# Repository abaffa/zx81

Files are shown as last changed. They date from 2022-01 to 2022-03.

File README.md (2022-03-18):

# ZX80/81 Project
A tribute repository for the Sinclair ZX81 homecomputer. Or... how I build my own zeddy.

I used the PCB designed by Wilco2009. You can get more info about (eagle/gerbers) at his repos (https://github.com/wilco2009/zx80-81-Double-Clone)

## Technical Information about ZX81
* [ZX81 Datasheet](_zx81/README.md)
* [ZX81 Peripherals](_zx81/peripherals/README.md)
* [ZX80/81 Project - Schematics](schema/README.md)

---

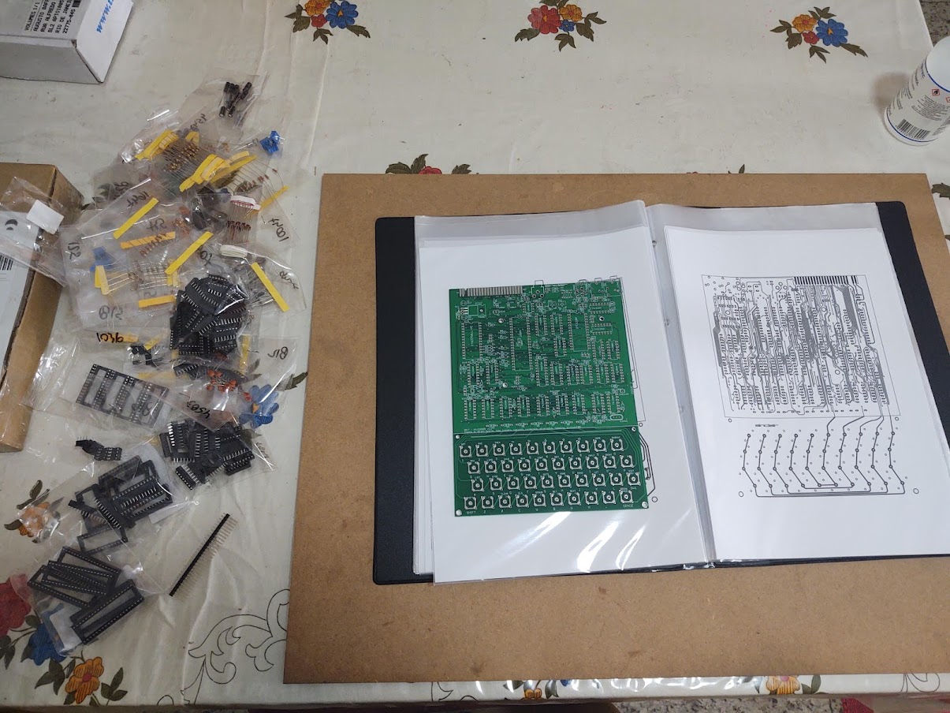
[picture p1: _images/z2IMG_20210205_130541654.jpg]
Starting Project


Starting Project

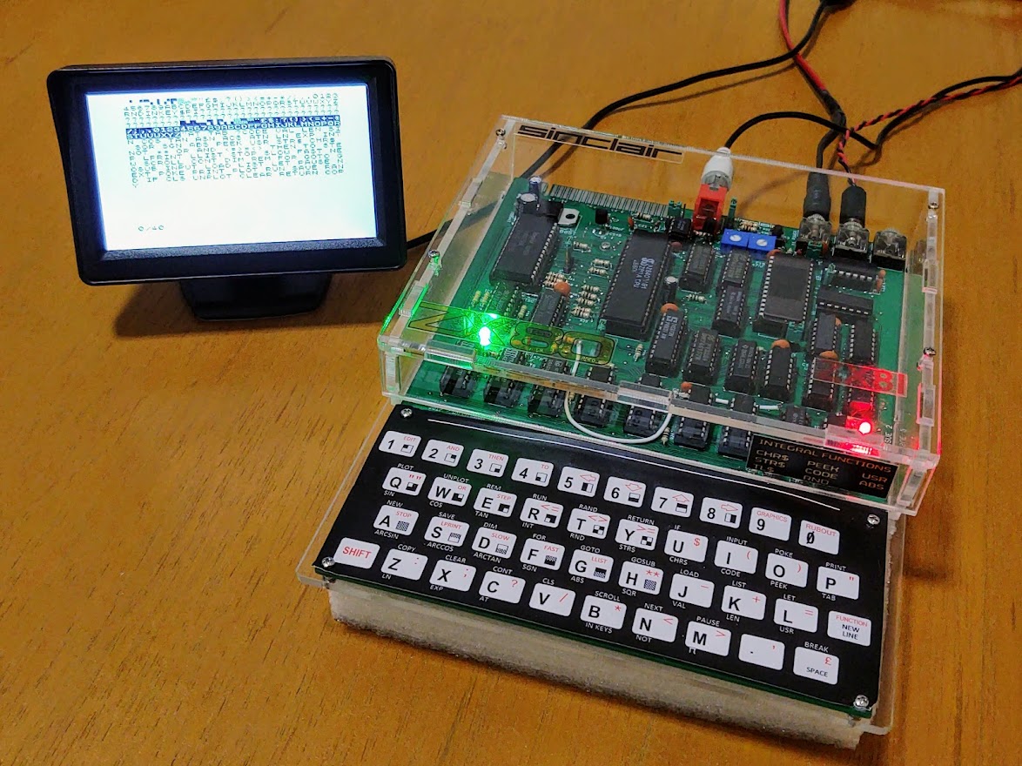
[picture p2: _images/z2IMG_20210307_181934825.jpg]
Project Done


Project Done

Zonx Prototype (https://www.youtube.com/watch?v=Kemn_Q3tHYs)

Zonx Prototype (video)

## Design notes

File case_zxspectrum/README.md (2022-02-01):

# 3D printed ZX Spectrum replacement case
by menyiques is licensed under the Creative Commons - Attribution - Share Alike license.

http://creativecommons.org/licenses/by-sa/3.0/

## Summary

WARNING: This is a concept and not a printable finished model.  Print under your responsability.

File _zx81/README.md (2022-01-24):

# Sinclair ZX81 Datasheet

* [Hardware](hardware.md)
* [Maintenance](maintenance.md)
* [Troubleshooting](troubleshooting.md)
* [Mods](mods.md)
* [List of Components](bom.md)

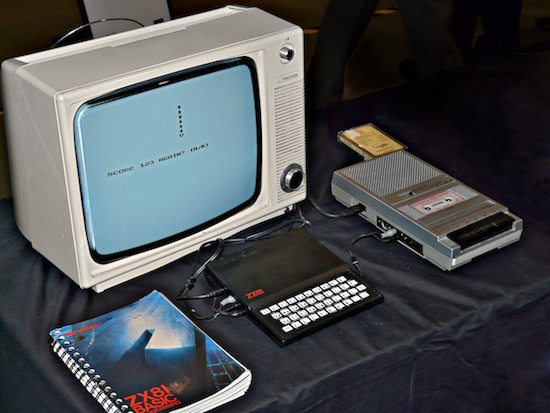
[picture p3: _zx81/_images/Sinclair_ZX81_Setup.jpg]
Sinclair ZX81


The ZX81 is the third computer from Sir Clive Sinclair's company, following the MK14 and the ZX80. Even having a relatively simple electronics, since it is made up of only 4 chips, it represents a significant improvement over its predecessor ZX80.

The computer is based on Zilog's Z80A microprocessor, with fairly limited RAM memory (1 kB), although expandable; and an 8 kB ROM that increased the 4 kb that the ZX80 had.

It introduces what would be a constant in Sinclair computers, which is the dedicated chip or "customized chip", such as the "Uncommitted Logic Array" or ULA.

The ULA was manufactured by Ferranti for Sinclair and replaces a total of 18 chips that performed similar functions in the ZX80. The main functions of this chip are:

* Generation of the clock frequency of 6.5 MHz through a ceramic filter.
* Bypass of the 3.5 MHz frequency necessary for microprocessor operation.
* TV signal generation compatible for RF modulator.
* Control of the external recording and playback device (SAVE / LOAD).
* Keyboard controls.
* Management of access priorities to RAM and ROM.
* Control of the general “timing” of the system.

Another important novelty compared to the ZX80 is the introduction of the SLOW mode, in addition to the FAST mode that it shares with the ZX80. This mode eliminates the annoying flicker characteristic of the ZX80 when making keystrokes.

The computer has no sound or color, working only in black and white and with limited graphic capabilities.

The keyboard is another of the characteristics of this computer, formed by a discussed membrane of 40 multifunction touch keys.

The computer uses Sinclair Basic as its programming language, whose interpreter is in ROM, in addition to the processor's own machine language. Although it is possible to find assemblers for other languages such as Forth.

It has an internal consumption in basic configuration of between 310 and 390 mA.

| Item  | Value |
| --- | --- |
|  Name |  Sinclair ZX81 |
|  Origin |  United Kingdom |
|  Launched |  March, 5th 1981 |
|  End of Production |  1984 |
|  Language |  Sinclair Basic |
|  Units Sold  |  > 1.5 Million |
|  Keyboard  |  40 Keys membrane keyboard |
|  CPU  |  Zilog Z80 A |
|  Speed  |  3.5 Mhz |
|  Bus  |  Data: 8 bits / Address 16 bits |
|  Ram  |  1KB (901 bytes available) - Max Expansion: 64KB (56 KB Available) |
|  Rom  |  8 KB |
|  Text Mode  | 32 x 24 (2 lines reserved for system messages and commands) |
|  Graphic Mode  | 64 x 44 (using PLOT / UNPLOT commands) |
|  Color  |  Black and White |
|  Sound  |  No |
|  Size and Weight  |  167 x 175 x 40 mm / 350 gr |
|  I/O Ports  |  Expansion Port, 2 cassete outputs (play and record), RF video output, load speed 300 bps (KCS) |
|  Power Source  |  External PSU, 9V DC, 600 mA (Positive polarity at the tip of the jack) |
|  Peripherals  |  ZX Printer |
|  Price  |  Kit: 50 GBP (UK, Jun 1981) - Assembled: 70 GBP (UK, Jun 1981) |

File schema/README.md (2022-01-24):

# ZX80/81 Project - Schematics
Schematics I made while studying how the ZX80/81 works

* [ZX81_Detailed_Schematics](ZX81_Detailed_Schematics.pdf) - Detailed Schematics used to create the PCBs - Gerber file
* [ZX81_Andy_Rea_ULA_Explained](ZX81_Andy_Rea_ULA_Explained.pdf) - ZX81 and ULA logic based on explained by Andy Rea
* [ZX81_Complete](ZX81_Complete.PDF) - Complete Schematic (ZX80 + Slow Circuit = ZX81) based on Sinclairs ZX80 Schematics and Grant Searle project

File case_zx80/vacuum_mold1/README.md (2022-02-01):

# Sinclair ZX80 Vacuum Form Molds 

by wjsteele is licensed under the Creative Commons - Public Domain Dedication license.

## Summary

This is a first attempt at a vacuum form mold set for the Sinclair ZX80 computer.  The ZX80's case was originally vacuum formed from polystyrene sheets, only later becoming injection molded.

This is an attempt to produce simple molds that can be made to replace the original cases which have become very brittle due to their age, or for a new ZX80 replica.  The Sinclair ZX80 computer was produced by a company called "Science Of Cambridge" (Later renamed Sinclar Research) in 1980 and was powered by the Zilog Z80 Microprocessor and utilized 4k of Rom and 1k of Ram.

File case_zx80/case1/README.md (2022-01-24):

# Sinclair ZX80 Case

by alvaroalea is licensed under the Creative Commons - Attribution - Non-Commercial - Share Alike license.

https://www.thingiverse.com/thing:1880449
http://creativecommons.org/licenses/by-nc-sa/3.0/

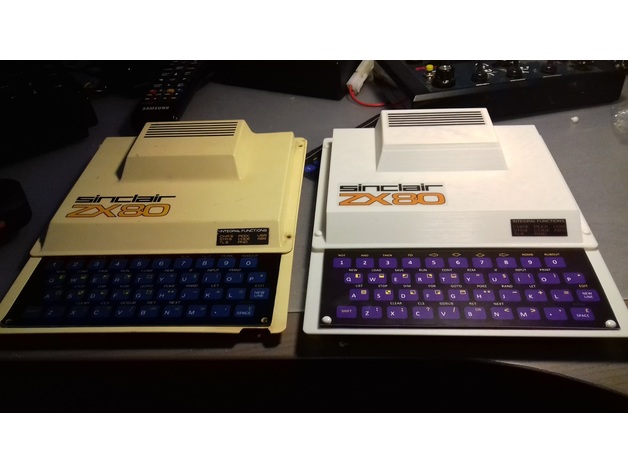
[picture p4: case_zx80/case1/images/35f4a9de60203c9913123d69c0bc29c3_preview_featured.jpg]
Printed Case


## Summary

This is part of the project to clone the Sinclair ZX80 8bits computer from 80's by people of the forum http://www.va-de-retro.com/foros/app.php/portal

botton side need to be printer in two part and optionally glued  in normal printers.

For the ribets, search for R2648 in certain chinesse web.

To be printed with support, the STL file also include some aditional supports I need to print it correctly with Cura.

There are aditional parts, for some customizations I made, check the correct parts for your need.

## Print Settings

Printer Brand: Prusa
Printer: Prusa Steel
Rafts: No
Supports: Yes
Resolution: 0.2mm layer, 0.4 nozzle
Infill: 100%

Notes: 
It's need a lot of support, I use Cura, with the zig-zag setting and a separation of 5mm.

## Post-Printing

Remove all the support and enlage the holes with a 2.5mm drill

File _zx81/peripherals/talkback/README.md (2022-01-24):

# ZX81 TALK-BACK

* [Mageco Eletronic SPO256 ZX81 Vocal Synthetizer Manual in French](MANUEL-ZX81-SPO256[MAGECO].pdf)
* [Eletronics - The Maplin Magazine Mar, 05th 1983](Maplin-Electronics-1983-03-05.pdf)

# ZX81 Talk~Back by Dave Goodman
(Maplin Magazine March 1983, UK)

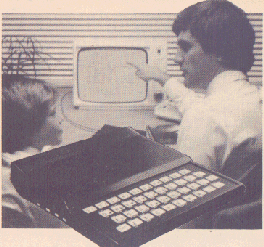
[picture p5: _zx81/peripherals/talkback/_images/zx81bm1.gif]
ZX81


* Add speech to your programs
* Allophone set provides unlimited vocabulary
* Plugs directly into expansion socket or motherboard
* Entry from simple PEEK and POKE in BASIC
* Audio output to extemal amplifier or our 'Sound-on-TV'

For many years considerable research and development has been done in the field of human speech synthesis. All languages have their own complex speech sounds, or ALLOPHONES, which are strung together to form recognisable words. The SHAW alphabet gives an indication of speech sounds, as many schoolchildren are probably aware.
Simple words like 'cad' use the letters 'see', 'ae', and 'tee'. Stringing these allophones together will produce the sound 'seat', not at all like 'cat', so letters of the alphabet are pronounced differently according to where they are used!

General Instruments' SPO256 Orator-Speech Processor makes use of the allophone system by storing sounds, with instructions, in 16K ROM. A Microtroller control data flow from ROM to a digital filter where speech elements are linked together, along with pitch and amplitude information. The resulting information is pulse width modulated, producing a digital output which has to be low pass filtered to produce recognisable speech.
Sixty-three allophones are available for use, and by concatenating individual sounds, reproduction of entire word lengths is possible. This is very flexible, although speech quality is not as good as systems where complete words are stored.

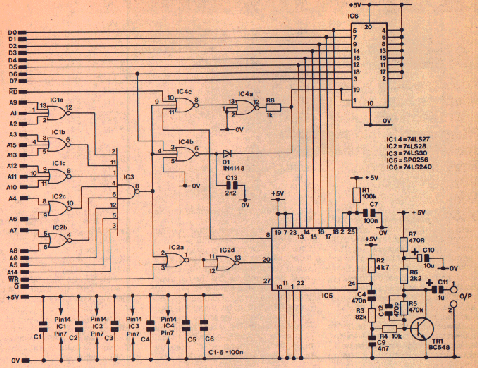
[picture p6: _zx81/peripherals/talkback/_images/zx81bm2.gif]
Circuit Diagram


## Circuit Description

Address lines A0 to A15 are decoded by IC1, 2 and 3 to give a memory-mapped 'PORT address of 16417. This address has not been allocated to the working system of the Zx81, and as it also has a RAM location it is ideal for use in this application. Writing to this address (POKE 16417) places a negative pulse on IC5 pin 20 Address Load input. Data written into IC5, on pins 13 to 18, is then loaded onto the input port, where it is processed to give speech output on pin 24. The circuitry of TR1 forms a low pass filter, to remove any H.F. content from the speech, and the resultant signal is amplified to a usable level of 100-500mV with the output on pin 1 (pin 2 is the 0V or screen). Obviously, the computer can supply data at a far greater rate than it can be processed by IC5, so pin 8 (standby) is used to enable IC6 if the 'PORT' address is read (PEEKed).

With suitable programming IC6 will place D0 to D8 to binary 0 and a software loop will prevent further data being entered to IC5 until the standby output resets. One problem, however, becomes apparent when the system is first switched on; R1 and C7 reset the SPO256 and pin 8 goes low. While the ZX81 CPU is resetting RAM locations, IC6 is enabled and data is prematurely entered, causing the computer to crash. lC4b, C13, and D1 hold IC6 pins 1 and 19 high to prevent this happening. Entering the command NEW can also cause this problem, but not if you are using 1 to 16K RAM. C13 may need to increase in value if larger RAM is used, and this is a subject for experimentation.

## Construction

Insert all 48 track pins through the holes marked with a circle, and solder them on both sides of the PCB. Fit resistors R1 to R7; if using the new 1% resistors with 5 band colour codes make sure that the values are correct. Finally, fit all capacitors, noting the polarity marking on C10. Do not insert the ICs yet. Solder all components to the PCB, clean, and inspect your work. Many faults can be cleared by using thinners and a stiff brush to remove all flux and solder splashes from the PCB.

If you do not possess a mother-board, fit a 2 x 23 socket (RK35Q) to the edge connector and solder all pins. Otherwise plug the module into your ZX81.

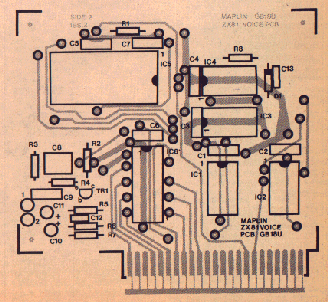
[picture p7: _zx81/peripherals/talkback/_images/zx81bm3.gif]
PCB Artwork and Legend


## Testing

Apply power. If all is well the cursor will appear as normal. Use a voltmeter to check that the 0V and +5V rails are correct on the PCB. Switch off and insert the six ICs into their sockets. Re-apply power. The cursor should appear again. You will need either an external amplifier or our sound/video project with connections to pins 1 and 2 on the module. Turn the amplifier or TV volume control to an acceptable level and type in POKE 16417, 197 followed by NEWLINE. You should hear the allophone 'oy' and a continuous 'e' sound. Type POKE 16417,0 NEWLINE and the sound will cease. Thus far, all should be well. Now enter program 1 and run it. Various prompts and directions appear during the program run and allophone sounds, not words, will be heard. Run the program several times to familiarise yourself with each sound and code number.

## Using the Talkback

If you refer to the Sinclair Manual page 178, you will see that address 16417 is not used by the working system. Fortunately this address, being part of the memory map, has a location in RAM which makes it ideal for use a a 'PORT'. Data POKEd to this address is read by the SPO256 chip, so the numbers entered must range from 192 to 255 to suit.
Table 1 gives a list of numbers and their equivalent allophone sound. Also shown is a list of ZX81 characters corresponding to each number and allophone. If a word, like COMPUTER, is phonetically split into a series of vowels and consonants the allophone equivalent will be something like this:

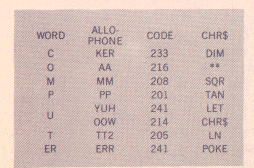
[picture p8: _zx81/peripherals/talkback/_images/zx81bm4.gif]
ZX81 Allophone Equivalent


## Allophones

The 5P0256 has 63 allophones, five of which are pauses of different duration, which leaves 58 to span the range of the English language. Because of this limitation compromises have to be made with pronunciation, but, in practise it is not a real problem as long as you do not mind your computer speaking with an American accent!

The letter c in computer does not sound like 'see', but 'k' as in kite. A short pause, e.g. code 194 (50ms) inserted between C and computer enhances the C, as can be heard in program 2. If you ran the test program, you will have heard each allophone spoken, and be already familiar with the sounds available, so now enter program 2.
The technique used in this program relies on placing allophone code numbers as CHR$ in line 1 after the REM statement. Altogether there are 18 CHRS in this line, including pauses. The first address after REM is 16514, so each character has its own address to 16532. The value of each address is POKEd into variable A, this being the PORT address of the speech processor, and line 1 is scanned, a character at a time, by line 10.

A software loop is set up by line 25 to allow time for each allophone to be spoken before continuing with the next instruction. Try removing line 25 from the program and listening to the difference.

Maybe you have your own routines for POKEIng numbers into port locations, so I won't go into programming techniques on the ZX81. Needless to say, if using this method the address must be found for the first character to be read after REM, otherwise your program may crash. Some of the allophone CHR$ must be entered in command word mode. One way of doing this is to first enter THEN (shift CHRS) to change the cursor from L to K, and then enter the command word. Step the cursor back to THEN and RUBOUT.

Step the cursor forward past the command word, and continue with the next CHR$. Always add a space (192 or "") at the end of the character string or insert POKE 16417,0 at the end of your program, otherwise speech will continue.
FOR-NEXT or PAUSE delays can be entered after the POKE 16417 command to slow down speech if you find that it talks too fast. Use codes 192 to 196 to add pauses between allophones where required. Previous sounds spoken can then be emphasised to suit the word formation, and speech made more intelligible.

Program 1.
```
1 REM TEST PROGRAM
2 LET A = 197
3 LET PORT = 16417
4 PRINT "PRESS NEWLINE"
5 IF INKEY$ = " " THEN GOTO 5
6 PRINT "ALLOPHONE ""OY"" WILL BE SPOKEN"
7 PAUSE 250
6 POKE PORT,A
9 POKE PORT,0
10 CLS
11 PRINT "NUMBER 197 TO 255 WILL BE DISPLAYED AND THE ALLOPHONE SPOKEN."
12 PAUSE 500
13 FOR A = 197 TO 255
14 PRINT AT 10,14;A
15 POKE PORT,A
16 FOR B = 0 TO 10
17 NEXT B
18 POKE PORT,192
19 NEXT A
20 POKE PORT,192
21 PRINT AT 15,0:"PRESS NEWLINE TO REPEAT TESTS"
22 INPUT A$
23 CLS
24 GOTO 11
```

Program 2.
```
1 LEN "" AT AND SQR "" TAB USR DIM AT ** SQR TAN LET CHR$ LN NEXT""
3 LET A = 16417
5 LET B = 16514
7 REM NUMBER OF CHR$
10 FOR C = B TO (B+17)
15 POKE A,PEEK C
20 REM WORD LENGTH
25 PEEK A=0 THEN GO TO 25
30 NEXT C
35 CLS
40 PRINT " ""I AM A COMPUTER"" "
45 PRINT AT 18.0;"PRESS NEWLINE"
50 INPUT A$
60 GOTO 1
```

Table 1
| chr$ | code | allophone | chr$ | code | allophone | chr$ | code | allophone |
|---|---|---|---|---|---|---|---|---|
| "" | 192 | pause 10ms | chr$ | 214 | oow | for | 235 | zer |
| at | 193 | pause 30ms | not | 215 | ao | goto | 236 | na |
| tab | 194 | pause 50ms | ** | 216 | aa | gosub | 237 | ll |
| code | 196 | pause 200ms | or | 217 | ye | input | 238 | ww |
| val | 197 | oy | and | 218 | ae | load | 239 | re |
| len | 198 | ay | <= | 219 | hh1 | list | 240 | wh |
| sin | 199 | eh | >= | 220 | bu | let | 241 | yuh |
| cos | 200 | kk3 | <> | 221 | th | pause | 242 | ch |
| tan | 201 | pp | then | 222 | uo | next | 243 | ere |
| asn | 202 | jh | to | 223 | uoo | poke | 244 | err |
| acs | 203 | nn | step | 224 | ou | print | 245 | uo |
| atn | 204 | 1h | lprint | 225 | dd2 | plot | 246 | dh2 |
| ln | 205 | tt2 | llist | 226 | gg | run | 247 | ss |
| exp | 206 | rr1 | stop | 227 | ve | save | 248 | nnn |
| int | 207 | ax | slow | 228 | gu | rand | 249 | her |
| sqr | 208 | mm | fast | 229 | ssh | if | 250 | or |
| sgn | 209 | tt1 | new | 230 | sz | cls | 251 | ar |
| abs | 210 | dh1 | scroll | 231 | r | unplot | 252 | yr |
| peek | 211 | iy | cont | 232 | ff | clear | 253 | ggg |
| usr | 212 | ey | dim | 233 | ker | return | 254 | el |
| str$ | 213 | dd1 | rem | 234 | ku | copy | 255 | bb | 

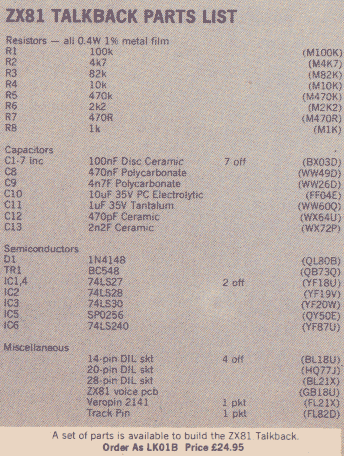
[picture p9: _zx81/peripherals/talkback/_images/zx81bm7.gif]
ZX81 Talkback parts list


---

## ZX81 Talk-Again

* [Talk-Again Repos by MCarlson](https://github.com/mcarlson-sb/talk-again)

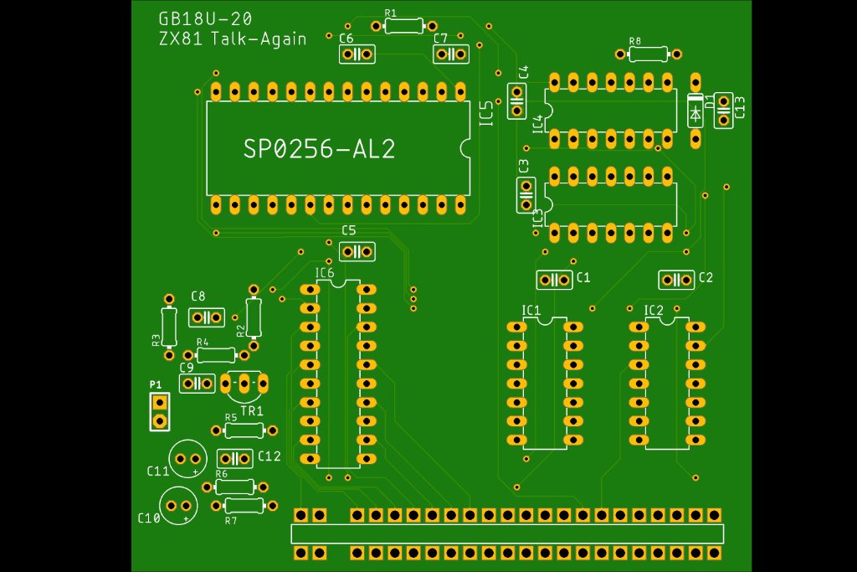
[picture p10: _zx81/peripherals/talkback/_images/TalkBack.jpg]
Talk-Again PCB


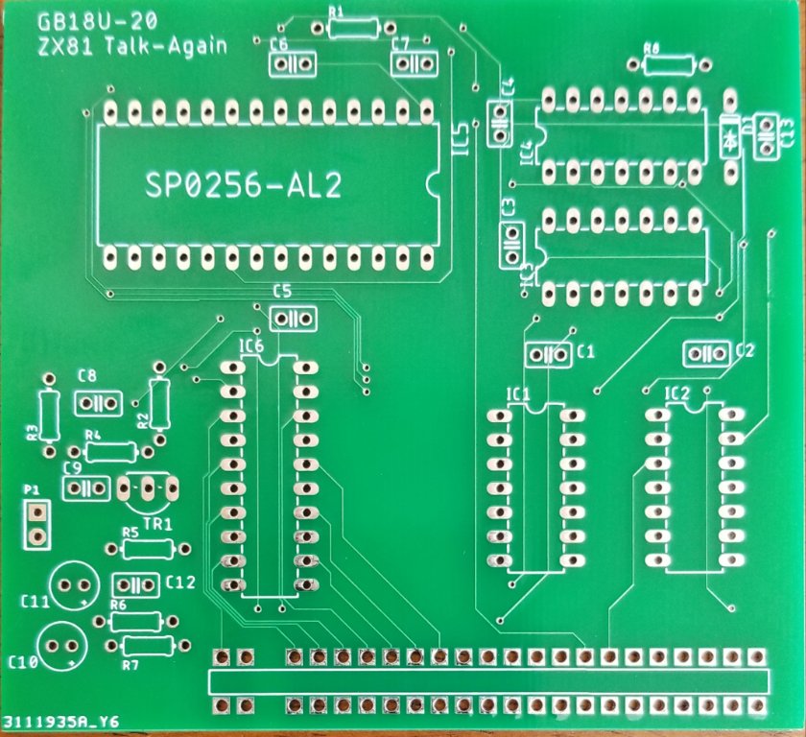
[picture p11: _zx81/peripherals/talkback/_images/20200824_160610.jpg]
Talk-Again PCB2


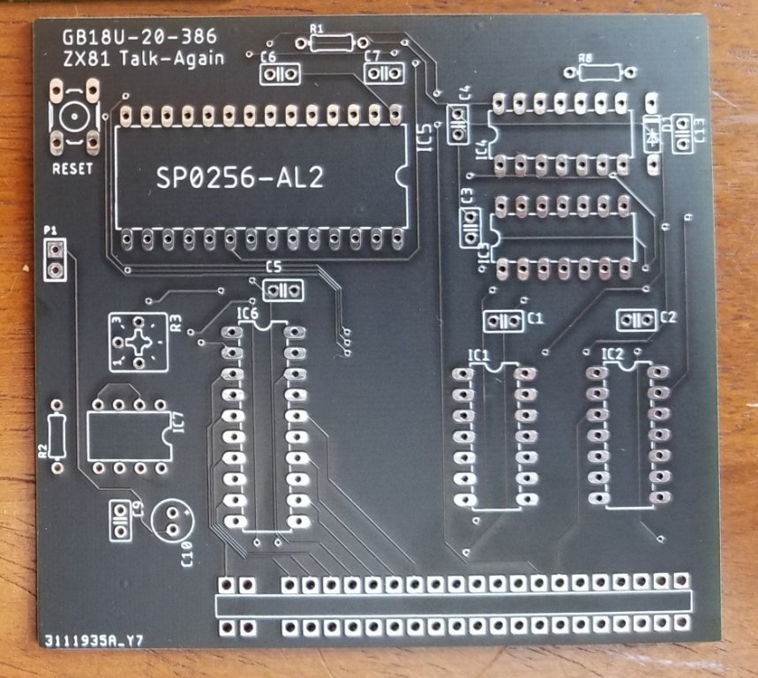
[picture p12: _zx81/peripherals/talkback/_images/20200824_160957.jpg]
Talk-Again PCB3


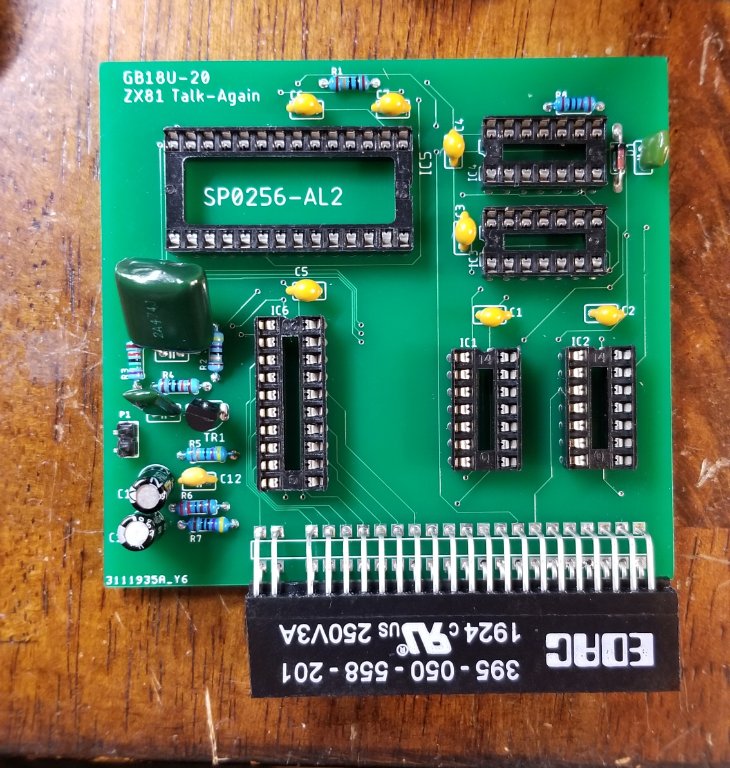
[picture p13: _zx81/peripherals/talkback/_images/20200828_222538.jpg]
Talk-Again PCB4


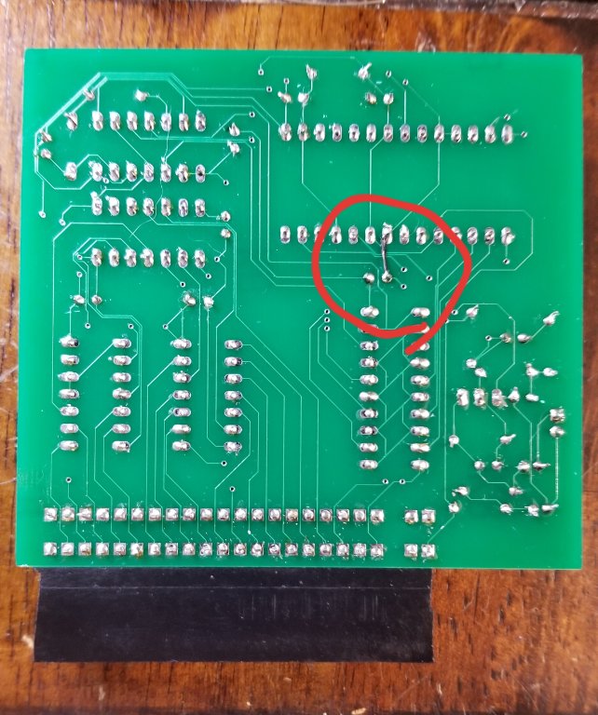
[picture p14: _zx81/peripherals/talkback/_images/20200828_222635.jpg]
Talk-Again PCB5


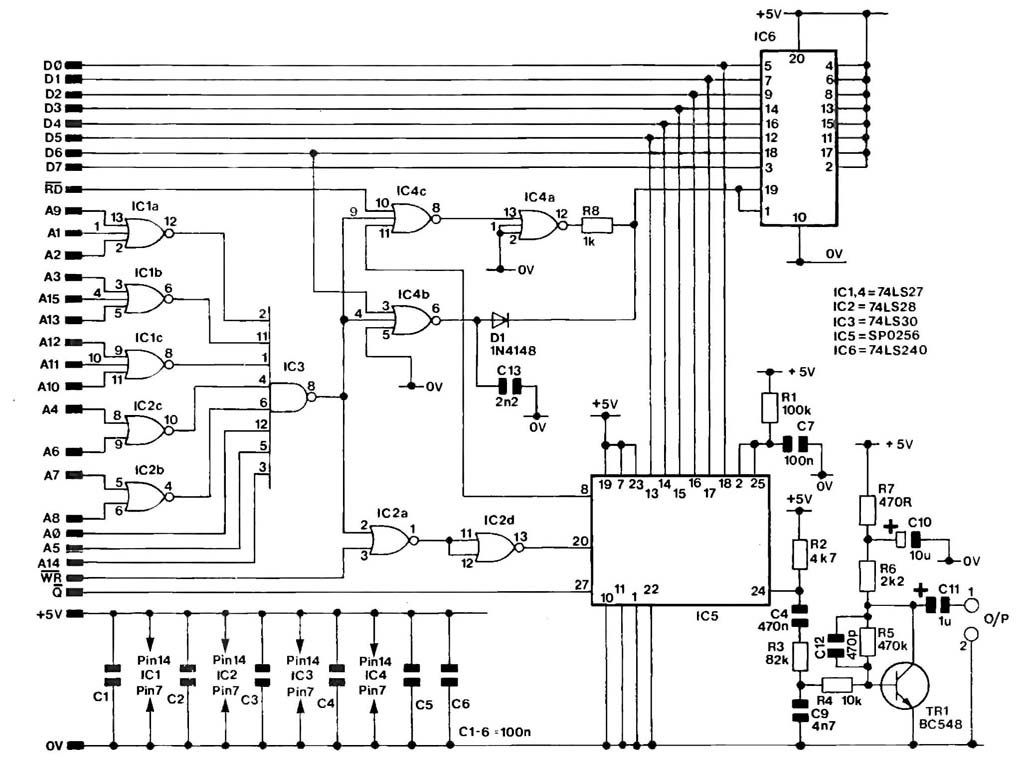
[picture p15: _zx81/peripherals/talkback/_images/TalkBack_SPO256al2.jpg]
TalkBack original Schema


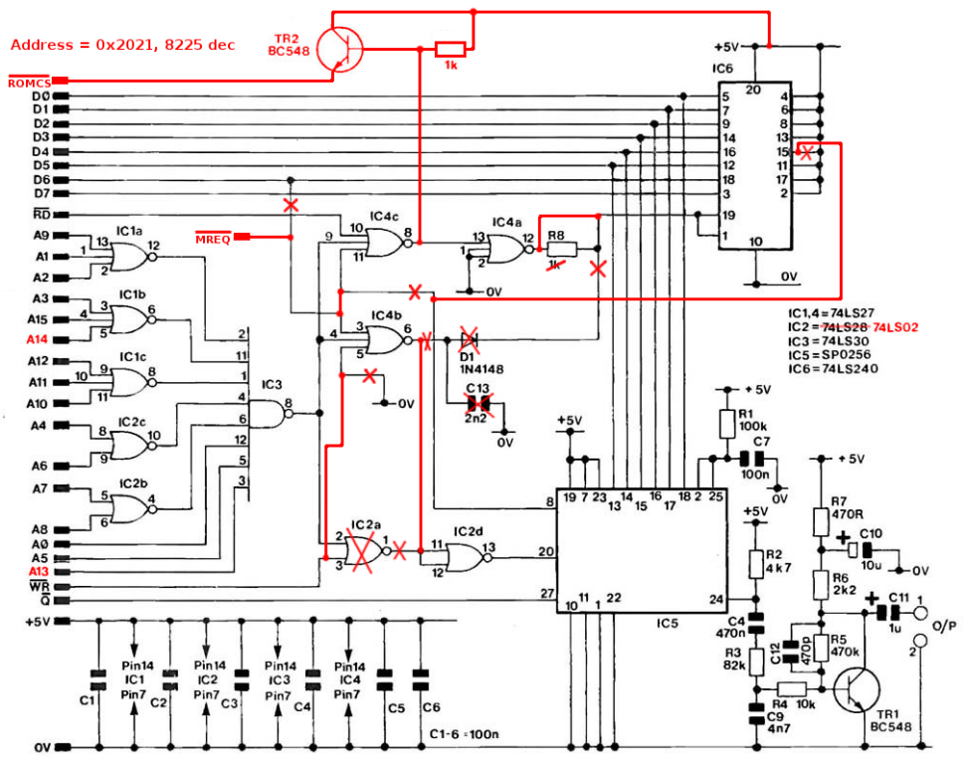
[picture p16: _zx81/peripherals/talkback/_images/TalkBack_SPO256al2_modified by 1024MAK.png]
TalkBack Modified Schema


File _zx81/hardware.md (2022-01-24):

# ZX81 Hardware

## Basic Motherboards

Issue #1. Made with curved traces and handmade. The board has the “solder mask” on the solder side in green. Most plates are green on the component side as well, although some plates can be found to be the color of the raw material on the plate.

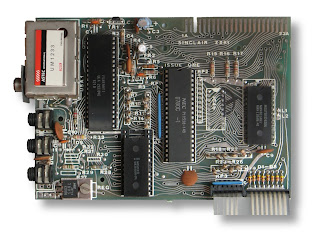
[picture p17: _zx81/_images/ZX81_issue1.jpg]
Issue 1


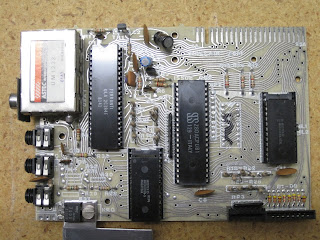
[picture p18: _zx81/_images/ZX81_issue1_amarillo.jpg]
Issue 1_yellow Issue 1 Yellow


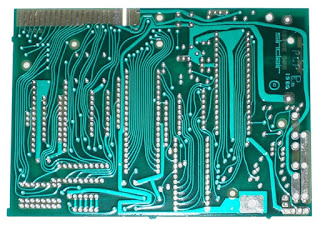
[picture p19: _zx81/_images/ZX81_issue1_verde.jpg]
Issue 1_green Issue 1 Green


Issue #2. It is a fairly difficult prototype to find. It is a unit that was made as a test for issue 3.

Issue #3. Made with CAD design and straight lines. The board has the solder mask on the solder side in red.

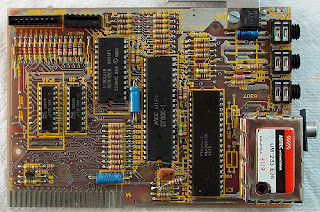
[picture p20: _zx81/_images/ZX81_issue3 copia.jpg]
Issue 3


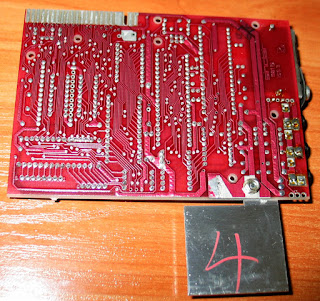
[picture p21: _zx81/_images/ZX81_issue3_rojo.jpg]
Issue 3_red Issue 3 Red


## CPUs

The CPU models that may appear in the ZX81 are:

* ZILOG Z80A
* NEC (uPD780C-1)
* MOSTEK (MK3880)

The pin layout or “pinout” is shown in the following figure:

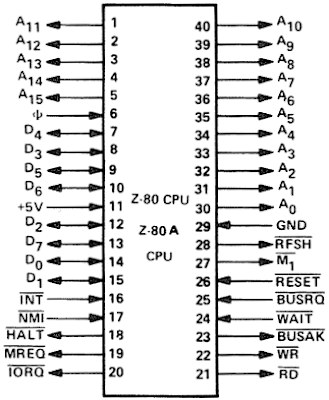
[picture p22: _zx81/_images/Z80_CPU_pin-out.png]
cpu_pinout CPU Pinout


## ROM

The ROM models that can be found in a ZX81 are:

* 2364 (8kB x 8 bits) 24-pin, on 28-pin socket
* Compatible Motorola ZCM38818C or 68764
* Compatible Mostek MK36809. This model can be found welded directly to the plate, without a base

The ROM firmware versions are:

* The “Standard” ROM. It is the original and the first buggy version as programmed by Sinclair.
* The “Improved” ROM. It is the second version programmed by Sinclair, and refined by Dr. I. Logan and Dr. Frank O'Hara. Some boards mounted a small circuit on top of the CPU with two SN74LS27N chips (“piggyback fix”).
* The “Shoulders of Giants” ROM. It is a debugged version programmed by Geoff Wearmouth.

The "piggyback fix" added to the "standard ROM" fixes the arithmetic errors but does not fix another bug involving the PAUSE function.

The error due to PAUSE –always with old ROMs-, causes the computer to crash or delete the program it has in memory by interrupting it with BREAK (“white-out effect”), as long as it is working in FAST mode. To avoid this, put POKE 16437,255; before the PAUSE statement.

The definitive test is to type PRINT PEEK 54, if the value received is 136, the ROM is correct.

To calculate the ROM checksum, enter the following code:

```
10 FAST
20 LET A=0
30 FOR B=0 TO 8191
40 LET A=A+PEEK B
50 NEXT B
60 PRINT A
```

| |  Standard ROM  |  Standard ROM + Piggyback Fix  |  Improved ROM  |
|---|---|---|---|
|  Checksum:  |  854885  |  854885  |  855106  |
|  PRINT PEEK 3823  |  33  |  33  |  205  |
|  PRINT SQR 0.25  |  1.3591409  |  0.5  |  0.5  |
|  PRINT 0.25**2  |  3.142384  |  0.0625  |  0.0625  |
|  PRINT 4-0.0000000001  |  12  |  4  |  4  |
|  PRINT SQR 0.0625  |  1.847264  |  0.25  |  0.25  |

The ROM pinout is shown in the following figure:

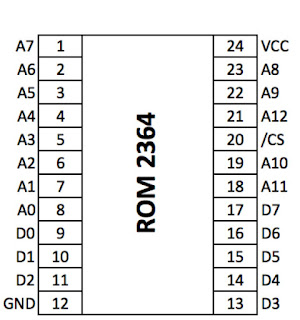
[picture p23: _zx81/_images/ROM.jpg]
rom_pinout ROM Pinout


## RAM

The boards can have two different models of RAM mounted:

* Two 18-pin ICs of type 2114 (1kB x 4 bits).
* A 24-pin IC of type 4118 (1kB x 8 bits) or 4816 (2kB x 8 bits). Type 4801 (1kB x 8 bits) is compatible with 4118.

| |  PRINT PEEK 16388 + 256*PEEK 16389  |  PRINT PEEK 16389  |
|---|---|---|
|  RAM 1kB:  |  17408  |  68  |
|  RAM 16kB:  |  32768  |  128  |

The pinouts of the different options are shown in the following figures:

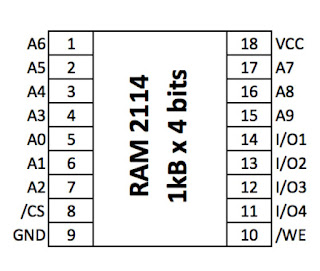
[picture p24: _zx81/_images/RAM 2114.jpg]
Ram_2114 RAM 2114


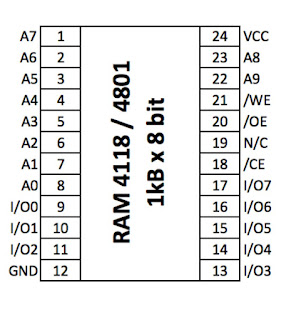
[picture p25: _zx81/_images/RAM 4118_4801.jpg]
Ram_4118_4801 RAM 4118/4801


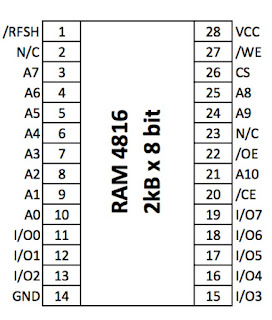
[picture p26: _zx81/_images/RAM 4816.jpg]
Ram_4816 RAM 4816


## ULA

There are three ULA models, both based on the Ferranti 2C000 prototype.

* 1st version: 2C158E. The reference to the version is placed on the rear face of the chip.
Only the year and week of production is written on the face when mounted on
the plinth This version does not generate the “back porch” of the image. The first versions
of this ULA, which were mounted on the issue #1 plate, are soldered directly
to plate without plinth.

* 2nd version: 2C184E. The video signal does not produce the "back porch" so on modern TVs you can see no picture or a very dark picture.

* 3rd version: 2C210E. It is the most modern version. Fix generation problem
from the back porch.

The pinout is common to all versions of ULA and can be seen in the figure below.

ULA_Pinout ULA Pinout

## Transistors

The ZX81 has only two transistors on the board: TR1 and TR2.

The transistor TR1 is part of the circuit that participates in the generation of the display of
so particular screen of the SLOW mode, interconnecting the signals /NMI, /HALT, /WAIT
and /INT, between the ULA and the CPU.

Transistor TR2 amplifies the clock signal at pin 14 of the ULA. The X1 oscillator is
6.5 MHz, which the ULA divides to 3.25 MHz, which is the CLK signal needed by the CPU in its
pin 6

## Electrolytic Capacitors

The ZX81 board only has two electrolytic capacitors: C3 and C5.

Capacitor C3 (22 uF – 16V) is part of the 7805 regulator circuit and serves as
input signal filtering and avoid unregulated power supply ripple.

Capacitor C5 is connected to pin 26 of the CPU which corresponds to the signal
/RESET. The ZX81 does not have a reset button but it has the circuit to be able to
install it. A simple push button between the pins of capacitor C5 enables the reset on the ZX81.

## Screen resolution

The way the ZX81 encodes video memory is slightly different if we have more than 3.25kB of RAM or less. In the case of having more than 3.25kB, the screen lines are encoded in the so-called expanded mode and always have the same size: 24 x 32 bytes (768 bytes + 25 bytes in HALT instructions = 793 bytes). The first byte in video memory is a HALT opcode, and each line is terminated with a HALT (end of line).

dfile Display File

In the case of having less than 3.25kB, the minimum size is 25 bytes, which corresponds to the first byte (HALT), plus 1 byte (HALT) for each of the 24 rows. That is, an empty screen occupies 25 bytes.

The following figure shows an example of the space occupied by the rendering after running the program in Basic on a computer with less than 3.25 kB of RAM. 

dfile2 Display File 2

## Expansion Port

The expansion port of the ZX81 is made up of a 46-pin male connector, although in reality 44 are used. The other two serve as placement marks.

expansion_port Expansion Port

| Top side |  |  | Bottom Side | 
|---|--|--|---|
| 1A | D7 | 1B | 5V |
| 2A | RAMCS | 2B |  |
| 3A | --SLOT-- | 3B | --SLOT-- |
| 4A | D0 | 4B | GND |
| 5A | D1 | 5B | GND |
| 6A | D2 | 6B | CLK |
| 7A | D6 | 7B | A1 |
| 8A | D5 | 8B | A2 |
| 9A | D3 | 9B | A3 |
| 10A | D4 | 10B | A4 |
| 11A | /INT | 1B | A15 |
| 12A | /NMI | 1B | A14 |
| 13A | /HALT | 1B | A13 |
| 14A | /MREQ | 1B | A12 |
| 15A | /IORQ | 1B | A11 |
| 16A | /RD | 1B | A10 |
| 17A | /WR | 1B | A9 |
| 18A | /BUSAK | 1B | A8 |
| 19A | /WAIT | 1B | A7 |
| 20A | /BUSRQ | 1B | A6 |
| 21A | /RESET | 1B | A5 |
| 22A | /M1 | 1B | A4 |
| 23A | /RFSH | 1B | /ROMCS |

| Signal  | Name  | Active | Direction |
|---|---|---|---|
| Address Bus | A0-A15 | HIGH | output |
| Data Bus | D0'-D7' | HIGH | bi-directional |
| Memory Request | /MREQ | LOW | output |
| I/O Request | /IORQ | LOW | output |
| Read | /RD | LOW | output |
| Write | /WR | LOW | output |
| ROM Selection | /ROMCS' | LOW | n/a |
| RAM Selection | /RAMCS | LOW | n/a |
| Reset | /RESET | LOW | n/a |
| Halt | /HALT | LOW | output |
| Wait | /WAIT | LOW | input |
| Bus Request | /BUSRQ | LOW | input |
| Bus Acknowledge | /BUSAK | LOW | output |
| Clock | /CLK | LOW | output |
| Refresh | /RFSH | LOW | output |
| Non-maskable Interruption | /NMI | LOW | intput |
| Interruption | /INT | LOW | input |
| Machine Cycle 1 | /M1 | LOW | output |

## External Connectors

|  RING  |  TYPE  |  CONNECTOR  |  TIP  |
|---|---|---|---|
|  TV Video  | RCA female 3.5 mm  |  GND |  TV signal  |
|  EAR  |  3.5 mm female jack  |  GND  |  Cassette input | 
|  MIC  |  3.5 mm female jack  |  GND  |  Cassette input  |
|  Power Source  |  3.5mm female jack  |  GND  |  9V DC  |

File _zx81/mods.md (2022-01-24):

# ZX81 Mods

## Internal Memory Expansion

This expansion is based on a 62256 SRAM static memory chip (32Kb x 8 bits). Other SRAM memories such as 43256, 55257 and 62CT081 are also suitable for this modification. With this expansion you can get up to 32kB of SRAM on the ZX81 board. With a simplification to this modification, 16kB are obtained.

The diagram shown below shows the modification corresponding to 32 KB:

32KB Ram

Below is the schematic for 16 kB:

16KB Ram

Cables HGR

Resistor HGR

Once this modification has been made, certain errors have been detected when executing HIRES graphics. These errors are not shown, however, with the Pseudo-HIRES, that is, in those generated entirely by software routines.

Cartoon WRX

Cartoon Original

There is no clear explanation for the error obtained, but it points to a higher speed of current SRAM memories compared to older ones. The proposed solution was found at random, and consists of putting a capacitor between the /RAMCS signal (pin 20) and GND (pin 22). The suggested capacitor value ranges from 33 pF to 68 pF, passing through values of 47 pF and 56 pF.

The next photo shows the position of the capacitor.

SRAM Capacitor

### References:

* [ZX-Team web - Internal 32 kB for the ZX81](http://www.zx81.de/english/_frame_e.htm)

## Replacing Original ROM with EPROM

The Spectrum's original ROM is a 24-pin 2364 (8kB x 8bit) chip, and is compatible with others such as the 68764 (Motorola) and 2716 EPROMs (or the Texas 2516 equivalent). All of them are either hard to find or too expensive for the purpose. This prototype shows a common EPROM like the 27C128. This EPROM is 16kB, and knowing that the ZX81 ROM is 8kB, it would allow us to have 2 different ROMs on the chip. With a selector that bridges the signal from A13 to GND or 5V, we would be able to select one bank or the other.

The 27C128 EPROM has 28 pins, so it is necessary to make a "piggyback" circuit to be able to place it on the socket. However, the ZX81 usually mounts 28-pin sockets even though the original ROM is 24-pin. To make a correct connection of the pins of the original ROM with the EPROM it is recommended to make this additional circuit.

Many of the connections are matched, hence the importance of aligning the socket with the pin strip. Very few wiring is required.

New EPROM

New EPROM2

The scheme is shown below:

New EPROM Schema

### References:
[Grant Searle hardware page for ZX80/ZX81](http://searle.hostei.com/grant/zx80/zx80.html#ROM)

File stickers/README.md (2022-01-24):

# ZX80/81 Project - Stickers
PVC Vinyl Stickers for ZX80/81 project

applied stickers Applied Stickers

Applied Stickers

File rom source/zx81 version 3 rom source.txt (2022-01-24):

; ===========================================================
; An Assembly Listing of the Operating System of the ZX81 ROM
; ===========================================================

; Last updated: 13-DEC-2004
; 2011		Updated to remove -, +, /, *, &, 
;		characters from labels (which confuse assemblers)
;
; 2011		Updated for conditional assembly of ORIGINAL or "Shoulders of Giants" ROM
;
; 2014-08-01	Updated to add CHARS_PER_LINE_WINDOW  which is normally 32.
;
;	The ideal pixel rates for square pixels on a PAL system are
;	14.75  MHz (interlaced) and
;	 7.375 MHz (non-interlaced, which the ZX80/ZX81 are).
;	These are not commonly available but fortunately one can buy
;	baud-rate generator frequencies such as
;	14.7456 and 7.3728 MHz that are only 0.03% low
;	which is more than close enough.
;
;	ZX video normally has 6.5 MHz pixel rate,
;	so 32 characters take 256 pixels in 39.4 microseconds.
;	A 7.3728 MHz clock and 40 characters produces 
;	320 pixels in 43.4 microseconds.
;
;	ZX80 video generation is software defined so it is
;	easy to get square pixels simply by subtracting 8 from the bytes
;	at hex addresses 287, 2AA and 2B8.
;	The video will appear to the left of the screen but
;	the characters will be square and a diagonal graphic line
;	will be at 45 degrees.
;
;	ZX81 video generation in fast mode exactly the same as the ZX80.
;
;	ZX81 video generation in slow mode is problematic, in that
;	the NMI generator expects a 3.25 MHz CPU clock 
;	(3.25MHz / 208 = 15.625 kHz = 64 microsecond line period)
;	It is inside the ULA where it cannot be modified.
;
;	Simply fitting a 7.3728 MHz crystal would reduce the line period to
;	57.3 microseconds. Slow mode would require the CPU clock to be
;	divided by 236.
;
;	Square pixels on NTSC requires 11+3/11 = 11.272... MHz (interlaced)
;	or 5.63.. non-interlaced which is slower than the original 6.5 MHz.
;	The NTSC line period is still 64 microseconds, so 256 pixels
;	stretch over 45 microseconds, and 320 pixels over 56 microseconds.
;	Thus it is possible to get square pixels on an NTSC display,
;	it is not possible to get 40 column text as well.
;	That would require the PAL clock, but pixels would not be square.
;
;	The ZX printer is fixed in hardware.
;	It will not work in 40-column mode.
;
;
;
;	PIXEL_CLOCK	equ	7372500
;
; on-line assembler complains about the line above
;
; CHARS_PER_LINE_WINDOW always 32 for 6.5   MHz pixel rate
;                       always 40 for 7.375 MHz PAL square pixel rate
;
CHARS_PER_LINE_WINDOW	equ	40	; 32	originally
;
; CHARS_PER_LINE always 32 for 6.5 MHz pixel rate
;                but 32 or 40 if using PAL square pixel rate
;
CHARS_HORIZONTAL	equ	40	; 32	originally
CHARS_VERTICAL		equ	24
;
; 2014-08-01
; Largely working but some bugs remain.
; Working:
; You can type text and it takes 40 characters before new line.
; 40 characters are nicely centred in the screen.
; PLOT X,Y accepts X from 0 to 79.
; Faulty:
; System crashing in an authentic ZX81 fashion,
; I don't know if this is due to software bugs
; or socket joint disturbance from key presses.
; 
;
; 2018-01-09 add org
; Assembles using on-line assembler "zasm" at:
;
; http://k1.spdns.de/cgi-bin/zasm.cgi
;
	org	0
	
FALSE		equ	0

ORIGINAL	equ	0
NOT_BODGED	equ	1

; 2018-02-09 CHARS_HORIZONTAL placed in SCROLL routine.
;		Thanks to Adam Klotblixt for testing code and spotting this bug.
;	Also added to some G007 routines.
;

;
; Work in progress.
; This file will cross-assemble an original version of the "Improved"
; ZX81 ROM.
; The file can be modified to change the behaviour of the ROM
; when used in emulators although there is no spare space available.
;
; The documentation is incomplete and if you can find a copy
; of "The Complete Spectrum ROM Disassembly" then many routines
; such as POINTERS and most of the mathematical routines are
; similar and often identical.
;
; I've used the labels from the above book in this file and also
; some from the more elusive Complete ZX81 ROM Disassembly
; by the same publishers, Melbourne House.

#if 0
; zasm does not understand these:
#define DEFB .BYTE	; TASM cross-assembler definitions
#define DEFW .WORD
#define EQU	.EQU
#endif

; define stuff sensibly:
;
; I/O locations:
;
IO_PORT_TAPE		equ	$FF	; write
IO_PORT_SCREEN		equ	$FF	; write

IO_PORT_KEYBOARD_RD	equ	$FE	; A0 low
IO_PORT_NMI_GEN_ON	equ	$FE	; A0 low
IO_PORT_NMI_GEN_OFF	equ	$FD	; A1 low
IO_PORT_PRINTER		equ	$FB	; A2 low

;
; System variables:
;
RAMBASE		equ	$4000
ERR_NR		equ	$4000		; The report code. Incremented before printing.
FLAGS		equ	$4001		; Bit 0: Suppression of leading space.
					; Bit 1: Control Flag for the printer.
					; Bit 2: Selects K or F mode; or, F or G
					; Bit 6: FP no. or string parameters.
					; Bit 7: Reset during syntax checking."
ERR_SP		equ	$4002		; Pointer to the GOSUB stack.
RAMTOP		equ	$4004		; The top of available RAM, or as specified.
MODE		equ	$4006		; Holds the code for K or F
PPC		equ	$4007		; Line number of the current statement.
PPC_hi		equ	PPC+1
VERSN		equ	$4009		; Marks the start of the RAM that is saved.
E_PPC		equ	$400A		; The BASIC line with the cursor
D_FILE		equ	$400C		; Pointer to Display file
DF_CC		equ	$400E		; Address for PRINT AT position
VARS		equ	$4010		; Pointer to variable area
DEST		equ	$4012		; Address of current variable in program area
E_LINE		equ	$4014		; Pointer to workspace
E_LINE_hi	equ	E_LINE+1
CH_ADD		equ	$4016		; Pointer for scanning a line, in program or workspace
X_PTR		equ	$4018		; Pointer to syntax error.
X_PTR_lo	equ	X_PTR
X_PTR_hi	equ	X_PTR+1
STKBOT		equ	$401A		; Pointer to calculator stack bottom.
STKEND		equ	$401C		; Pointer to calculator stack end.
BERG		equ	$401E		; Used for many different counting purposes
MEM		equ	$401F		; Pointer to base of table of fp. nos, either in calc. stack or variable area.
;					; Unused by ZX BASIC. Or FLAG Y for G007
DF_SZ		equ	$4022		; Number of lines in the lower screen
S_TOP		equ	$4023		; Current line number of automatic listing
LAST_K		equ	$4025		; Last Key pressed
DEBOUNCE_VAR	equ	$4027		; The de-bounce status
MARGIN		equ	$4028		; Adjusts for differing TV standards
NXTLIN		equ	$4029		; Next BASIC line to be interpreted
OLDPPC		equ	$402B		; Last line number, in case needed.
FLAGX		equ	$402D		; Bit 0: Reset indicates an arrayed variable
					; Bit 1: Reset indicates a given variable exists
					; Bit 5: Set during INPUT mode
					; Bit 7: Set when INPUT is to be numeric
STRLEN		equ	$402E		; Length of a string, or a BASIC line
STRLEN_lo	equ	STRLEN		; 
T_ADDR		equ	$4030		; Pointer to parameter table. & distinguishes between PLOT & UNPLOT
SEED		equ	$4032		; For RANDOM function
FRAMES		equ	$4034		; Frame counter
FRAMES_hi	equ	FRAMES+1	; 
COORDS		equ	$4036		; X & Y for PLOT
COORDS_x	equ	COORDS		; 
PR_CC		equ	$4038		; Print buffer counter
S_POSN		equ	$4039		; Line & Column for PRINT AT
S_POSN_x	equ	$4039		; 
S_POSN_y	equ	$403A		; 
CDFLAG		equ	$403B		; Bit 6 = the true fast/slow flag
					; Bit 7 = copy of the fast/slow flag. RESET when FAST needed
PRBUFF		equ	$403C		; Printer buffer
PRBUFF_END	equ	$405C		; 
MEM_0_1st	equ	$405D		; room for 5 floating point numbers (meme_0 to mem_ 5???)
;			$407B		; unused. Or RESTART to G007
;			$407D		; The BASIC program starts here
;		equ	$40
;		equ	$40
;		equ	$40
; First byte after system variables:
USER_RAM	equ	$407D
MAX_RAM		equ	$7FFF

;===============================
; ZX81 constants:
;===============================
; ZX characters (not the same as ASCII)
;-------------------------------
ZX_SPACE	equ	$00
;	ZX_graphic		equ	$01	
;	ZX_graphic		equ	$02	
;	ZX_graphic		equ	$03	
;	ZX_graphic		equ	$04	
;	ZX_graphic		equ	$05	
;	ZX_graphic		equ	$06	
;	ZX_graphic		equ	$07	
;	ZX_graphic		equ	$08	
;	ZX_graphic		equ	$09	
;	ZX_graphic		equ	$0A	
ZX_QUOTE		equ	$0B
ZX_POUND		equ	$0C
ZX_DOLLAR		equ	$0D
ZX_COLON		equ	$0E
ZX_QUERY		equ	$0F
ZX_BRACKET_LEFT		equ	$10
ZX_BRACKET_RIGHT	equ	$11
ZX_GREATER_THAN		equ	$12
ZX_LESS_THAN		equ	$13
ZX_EQUAL		equ	$14
ZX_PLUS			equ	$15
ZX_MINUS		equ	$16
ZX_STAR			equ	$17
ZX_SLASH		equ	$18
ZX_SEMICOLON		equ	$19
ZX_COMMA		equ	$1A
ZX_PERIOD		equ	$1B
ZX_0		equ	$1C
ZX_1		equ	$1D
ZX_2		equ	$1E
ZX_3		equ	$1F
ZX_4		equ	$20
ZX_5		equ	$21
ZX_6		equ	$22
ZX_7		equ	$23
ZX_8		equ	$24
ZX_9		equ	$25
ZX_A		equ	$26
ZX_B		equ	$27
ZX_C		equ	$28
ZX_D		equ	$29
ZX_E		equ	$2A
ZX_F		equ	$2B
ZX_G		equ	$2C
ZX_H		equ	$2D
ZX_I		equ	$2E
ZX_J		equ	$2F
ZX_K		equ	$30
ZX_L		equ	$31
ZX_M		equ	$32
ZX_N		equ	$33
ZX_O		equ	$34
ZX_P		equ	$35
ZX_Q		equ	$36
ZX_R		equ	$37
ZX_S		equ	$38
ZX_T		equ	$39
ZX_U		equ	$3A
ZX_V		equ	$3B
ZX_W		equ	$3C
ZX_X		equ	$3D
ZX_Y		equ	$3E
ZX_Z		equ	$3F
ZX_RND			equ	$40
ZX_INKEY_STR		equ	$41
ZX_PI			equ	$42
;
; $43 to $6F not used
;
ZX_cursor_up		equ	$70
ZX_cursor_down		equ	$71
ZX_cursor_left		equ	$72
ZX_cursor_right		equ	$73

ZX_GRAPHICS		equ	$74
ZX_EDIT			equ	$75
ZX_NEWLINE		equ	$76
ZX_RUBOUT		equ	$77
ZX_KL			equ	$78
ZX_FUNCTION		equ	$79
;
; $7A to $7F not used
;
ZX_CURSOR		equ	$7F
;
; $80 to $BF are inverses of $00 to $3F
;
;	ZX_graphic		equ	$80	 ; inverse space
;	ZX_graphic		equ	$81	
;	ZX_graphic		equ	$82	
;	ZX_graphic		equ	$83	
;	ZX_graphic		equ	$84	
;	ZX_graphic		equ	$85	
;	ZX_graphic		equ	$86	
;	ZX_graphic		equ	$87	
;	ZX_graphic		equ	$88	
;	ZX_graphic		equ	$89	
;	ZX_graphic		equ	$8A	
ZX_INV_QUOTE		equ	$8B
ZX_INV_POUND		equ	$8C
ZX_INV_DOLLAR		equ	$8D
ZX_INV_COLON		equ	$8E
ZX_INV_QUERY		equ	$8F
ZX_INV_BRACKET_RIGHT	equ	$90
ZX_INV_BRACKET_LEFT	equ	$91
ZX_INV_GT		equ	$92

ZX_INV_PLUS		equ	$95
ZX_INV_MINUS		equ	$96

ZX_INV_K		equ	$B0
ZX_INV_S		equ	$B8

ZX_DOUBLE_QUOTE		equ	$C0
ZX_AT			equ	$C1
ZX_TAB			equ	$C2
; not used		equ	$C3
ZX_CODE			equ	$C4
ZX_VAL			equ	$C5
ZX_LEN			equ	$C6
ZX_SIN			equ	$C7
ZX_COS			equ	$C8
ZX_TAN			equ	$C9
ZX_ASN			equ	$CA
ZX_ACS			equ	$CB
ZX_ATN			equ	$CC
ZX_LN			equ	$CD
ZX_EXP			equ	$CE
ZX_INT			equ	$CF

ZX_SQR			equ	$D0
ZX_SGN			equ	$D1
ZX_ABS			equ	$D2
ZX_PEEK			equ	$D3
ZX_USR			equ	$D4
ZX_STR_STR		equ	$D5		; STR$
ZX_CHR_STR		equ	$D6		; CHR$
ZX_NOT			equ	$D7
ZX_POWER		equ	$D8
ZX_OR			equ	$D9
ZX_AND			equ	$DA
ZX_LESS_OR_EQUAL	equ	$DB
ZX_GREATER_OR_EQUAL	equ	$DC
ZX_NOT_EQUAL		equ	$DD
ZX_THEN			equ	$DE
ZX_TO			equ	$DF

ZX_STEP			equ	$E0
ZX_LPRINT		equ	$E1
ZX_LLIST		equ	$E2
ZX_STOP			equ	$E3
ZX_SLOW			equ	$E4
ZX_FAST			equ	$E5
ZX_NEW			equ	$E6
ZX_SCROLL		equ	$E7
ZX_CONT			equ	$E8
ZX_DIM			equ	$E9
ZX_REM			equ	$EA
ZX_FOR			equ	$EB
ZX_GOTO			equ	$EC
ZX_GOSUB		equ	$ED
ZX_INPUT		equ	$EE
ZX_LOAD			equ	$EF

ZX_LIST			equ	$F0
ZX_LET			equ	$F1
ZX_PAUSE		equ	$F2
ZX_NEXT			equ	$F3
ZX_POKE			equ	$F4
ZX_PRINT		equ	$F5
ZX_PLOT			equ	$F6
ZX_RUN			equ	$F7
ZX_SAVE			equ	$F8
ZX_RAND			equ	$F9
ZX_IF			equ	$FA
ZX_CLS			equ	$FB
ZX_UNPLOT		equ	$FC
ZX_CLEAR		equ	$FD
ZX_RETURN		equ	$FE
ZX_COPY			equ	$FF

;
_CLASS_00	equ	0
_CLASS_01	equ	1
_CLASS_02	equ	2
_CLASS_03	equ	3
_CLASS_04	equ	4
_CLASS_05	equ	5
_CLASS_06	equ	6

; These values taken from BASIC manual
; 
;
ERROR_CODE_SUCCESS			equ	0
ERROR_CODE_CONTROL_VARIABLE		equ	1
ERROR_CODE_UNDEFINED_VARIABLE		equ	2
ERROR_CODE_SUBSCRIPT_OUT_OF_RANGE	equ	3
ERROR_CODE_NOT_ENOUGH_MEMORY		equ	4
ERROR_CODE_NO_ROOM_ON_SCREEN		equ	5
ERROR_CODE_ARITHMETIC_OVERFLOW		equ	6
ERROR_CODE_RETURN_WITHOUT_GOSUB		equ	7
ERROR_CODE_INPUT_AS_A_COMMAND		equ	8
ERROR_CODE_STOP				equ	9
ERROR_CODE_INVALID_ARGUMENT		equ	10

ERROR_CODE_INTEGER_OUT_OF_RANGE		equ	11
ERROR_CODE_VAL_STRING_INVALID		equ	12
ERROR_CODE_BREAK			equ	13

ERROR_CODE_EMPTY_PROGRAM_NAME		equ	15

;
; codes for Forth-like calculator
;
__jump_true		equ	$00
__exchange		equ	$01
__delete		equ	$02
__subtract		equ	$03
__multiply		equ	$04
__division		equ	$05
__to_power		equ	$06
__or			equ	$07
__boolean_num_and_num	equ	$08
__num_l_eql		equ	$09
__num_gr_eql		equ	$0A
__nums_neql		equ	$0B
__num_grtr		equ	$0C
__num_less		equ	$0D
__nums_eql		equ	$0E
__addition		equ	$0F
__strs_and_num		equ	$10
__str_l_eql		equ	$11
__str_gr_eql		equ	$12
__strs_neql		equ	$13
__str_grtr		equ	$14
__str_less		equ	$15
__strs_eql		equ	$16
__strs_add		equ	$17
__negate		equ	$18
__code			equ	$19
__val			equ	$1A 
__len			equ	$1B 
__sin			equ	$1C
__cos			equ	$1D
__tan			equ	$1E
__asn			equ	$1F
__acs			equ	$20
__atn			equ	$21
__ln			equ	$22
__exp			equ	$23
__int			equ	$24
__sqr			equ	$25
__sgn			equ	$26
__abs			equ	$27
__peek			equ	$28
__usr_num		equ	$29
__str_dollar		equ	$2A
__chr_dollar		equ	$2B
__not			equ	$2C
__duplicate		equ	$2D
__n_mod_m		equ	$2E
__jump			equ	$2F
__stk_data		equ	$30
__dec_jr_nz		equ	$31
__less_0		equ	$32
__greater_0		equ	$33
__end_calc		equ	$34
__get_argt		equ	$35
__truncate		equ	$36
__fp_calc_2		equ	$37
__e_to_fp		equ	$38

;
; __series_xx			equ	$39 : $80__$9F.
; tells the stack machine to push 
; 0 to 31 floating-point values on the stack.
;
__series_06		equ	$86
__series_08		equ	$88
__series_0C		equ	$8C
;	__stk_const_xx			equ	$3A : $A0__$BF.
;	__st_mem_xx			equ	$3B : $C0__$DF.
;	__get_mem_xx			equ	$3C : $E0__$FF.

__st_mem_0			equ	$C0
__st_mem_1			equ	$C1
__st_mem_2			equ	$C2
__st_mem_3			equ	$C3
__st_mem_4			equ	$C4
__st_mem_5			equ	$C5
__st_mem_6			equ	$C6
__st_mem_7			equ	$C7

__get_mem_0			equ	$E0
__get_mem_1			equ	$E1
__get_mem_2			equ	$E2
__get_mem_3			equ	$E3
__get_mem_4			equ	$E4

__stk_zero			equ	$A0
__stk_one			equ	$A1
__stk_half			equ	$A2
__stk_half_pi			equ	$A3
__stk_ten			equ	$A4

;*****************************************
;** Part 1. RESTART ROUTINES AND TABLES **
;*****************************************

; THE 'START'

; All Z80 chips start at location zero.
; At start-up the Interrupt Mode is 0, ZX computers use Interrupt Mode 1.
; Interrupts are disabled .

mark_0000:
START:
	OUT	(IO_PORT_NMI_GEN_OFF),A	; Turn off the NMI generator if this ROM is 
				; running in ZX81 hardware. This does nothing 
				; if this ROM is running within an upgraded
				; ZX80.
	LD	BC,MAX_RAM	; Set BC to the top of possible RAM.
				; The higher unpopulated addresses are used for
				; video generation.
	JP	RAM_CHECK	; Jump forward to RAM_CHECK.

; THE 'ERROR' RESTART

; The error restart deals immediately with an error.
; ZX computers execute the same code in runtime as when checking syntax.
; If the error occurred while running a program
; then a brief report is produced.
; If the error occurred while entering a BASIC line or in input etc., 
; then the error marker indicates the exact point at which the error lies.

mark_0008:
ERROR_1:
	LD	HL,(CH_ADD)	; fetch character address from CH_ADD.
	LD	(X_PTR),HL	; and set the error pointer X_PTR.
	JR	ERROR_2		; forward to continue at ERROR_2.

; THE 'PRINT A CHARACTER' RESTART

; This restart prints the character in the accumulator using the alternate
; register set so there is no requirement to save the main registers.
; There is sufficient room available to separate a space (zero) from other
; characters as leading spaces need not be considered with a space.

mark_0010:
PRINT_A:
	AND	A		; test for zero - space.
	JP	NZ,PRINT_CH	; jump forward if not to PRINT_CH.

	JP	PRINT_SP	; jump forward to PRINT_SP.

; ___
#if ORIGINAL
	DEFB	$FF		; unused location.
#else
	DEFB	$01		;+ unused location. Version. PRINT PEEK 23
#endif

; THE 'COLLECT A CHARACTER' RESTART

; The character addressed by the system variable CH_ADD is fetched and if it
; is a non-space, non-cursor character it is returned else CH_ADD is 
; incremented and the new addressed character tested until it is not a space.

mark_0018:
GET_CHAR:
	LD	HL,(CH_ADD)	; set HL to character address CH_ADD.
	LD	A,(HL)		; fetch addressed character to A.

TEST_SP:
	AND	A		; test for space.
	RET	NZ		; return if not a space

	NOP			; else trickle through
	NOP			; to the next routine.

; THE 'COLLECT NEXT CHARACTER' RESTART

; The character address is incremented and the new addressed character is 
; returned if not a space, or cursor, else the process is repeated.

mark_0020:
NEXT_CHAR:
	CALL	CH_ADD_PLUS_1	; gets next immediate
				; character.
	JR	TEST_SP		; back
; ___

	DEFB	$FF, $FF, $FF	; unused locations.

; THE 'FLOATING POINT CALCULATOR' RESTART

; this restart jumps to the recursive floating-point calculator.
; the ZX81's internal, FORTH-like, stack-based language.
;
; In the five remaining bytes there is, appropriately, enough room for the
; end-calc literal - the instruction which exits the calculator.

mark_0028:
FP_CALC:
#if ORIGINAL
	JP	CALCULATE	; jump immediately to the CALCULATE routine.
#else

	JP	CALCULATE	;+ jump to the NEW calculate routine address.
#endif

mark_002B:
end_calc:
	POP	AF		; drop the calculator return address RE_ENTRY
	EXX			; switch to the other set.

	EX	(SP),HL		; transfer H'L' to machine stack for the
				; return address.
				; when exiting recursion then the previous
				; pointer is transferred to H'L'.

	EXX			; back to main set.
	RET			; return.

; THE 'MAKE BC SPACES' RESTART

; This restart is used eight times to create, in workspace, the number of
; spaces passed in the BC register.

mark_0030:
BC_SPACES:
	PUSH	BC		; push number of spaces on stack.
	LD	HL,(E_LINE)	; fetch edit line location from E_LINE.
	PUSH	HL		; save this value on stack.
	JP	RESERVE		; jump forward to continue at RESERVE.

_START		equ	$00
_ERROR_1	equ	$08
_PRINT_A	equ	$10
_GET_CHAR	equ	$18
_NEXT_CHAR	equ	$20
_FP_CALC	equ	$28
_BC_SPACES	equ	$30

; THE 'INTERRUPT' RESTART

;	The Mode 1 Interrupt routine is concerned solely with generating the central
;	television picture.
;	On the ZX81 interrupts are enabled only during the interrupt routine, 
;	although the interrupt 
;
;	This Interrupt Service Routine automatically disables interrupts at the 
;	outset and the last interrupt in a cascade exits before the interrupts are
;	enabled.
;
;	There is no DI instruction in the ZX81 ROM.
;
;	A maskable interrupt is triggered when bit 6 of the Z80's Refresh register
;	changes from set to reset.
;
;	The Z80 will always be executing a HALT (NEWLINE) when the interrupt occurs.
;	A HALT instruction repeatedly executes NOPS but the seven lower bits
;	of the Refresh register are incremented each time as they are when any 
;	simple instruction is executed. (The lower 7 bits are incremented twice for
;	a prefixed instruction)
;
;	This is controlled by the Sinclair Computer Logic Chip - manufactured from 
;	a Ferranti Uncommitted Logic Array.
;
;	When a Mode 1 Interrupt occurs the Program Counter, which is the address in
;	the upper echo display following the NEWLINE/HALT instruction, goes on the 
;	machine stack.	193 interrupts are required to generate the last part of
;	the 56th border line and then the 192 lines of the central TV picture and, 
;	although each interrupt interrupts the previous one, there are no stack 
;	problems as the 'return address' is discarded each time.
;
;	The scan line counter in C counts down from 8 to 1 within the generation of
;	each text line. For the first interrupt in a cascade the initial value of 
;	C is set to 1 for the last border line.
;	Timing is of the utmost importance as the RH border, horizontal retrace
;	and LH border are mostly generated in the 58 clock cycles this routine 
;	takes .

MARK_0038:
INTERRUPT:
	DEC	C		; (4)	decrement C - the scan line counter.
	JP	NZ,SCAN_LINE	; (10/10) JUMP forward if not zero to SCAN_LINE

	POP	HL		; (10) point to start of next row in display 
				;	file.

	DEC	B		; (4)	decrement the row counter. (4)
	RET	Z		; (11/5) return when picture complete to R_IX_1_LAST_NEWLINE
				;	with interrupts disabled.

	SET	3,C		; (8)	Load the scan line counter with eight.
				;	Note. LD C,$08 is 7 clock cycles which 
				;	is way too fast.

; ->

mark_0041:
WAIT_INT:
;
; NB $DD is for 32-column display
;
	LD	R,A		; (9) Load R with initial rising value $DD.

	EI			; (4) Enable Interrupts.	[ R is now $DE ].

	JP	(HL)		; (4) jump to the echo display file in upper
				;	memory and execute characters $00 - $3F 
				;	as NOP instructions.	The video hardware 
				;	is able to read these characters and, 
				;	with the I register is able to convert 
				;	the character bitmaps in this ROM into a 
				;	line of bytes. Eventually the NEWLINE/HALT
				;	will be encountered before R reaches $FF. 
				;	It is however the transition from $FF to 
				;	$80 that triggers the next interrupt.
				;	[ The Refresh register is now $DF ]

; ___

mark_0045:
SCAN_LINE:
	POP	DE		; (10) discard the address after NEWLINE as the 
				;	same text line has to be done again
				;	eight times. 

	RET	Z		; (5)	Harmless Nonsensical Timing.
				;	(condition never met)

	JR	WAIT_INT	; (12) back to WAIT_INT

;	Note. that a computer with less than 4K or RAM will have a collapsed
;	display file and the above mechanism deals with both types of display.
;
;	With a full display, the 32 characters in the line are treated as NOPS
;	and the Refresh register rises from $E0 to $FF and, at the next instruction 
;	- HALT, the interrupt occurs.
;	With a collapsed display and an initial NEWLINE/HALT, it is the NOPs 
;	generated by the HALT that cause the Refresh value to rise from $E0 to $FF,
;	triggering an Interrupt on the next transition.
;	This works happily for all display lines between these extremes and the 
;	generation of the 32 character, 1 pixel high, line will always take 128 
;	clock cycles.

; THE 'INCREMENT CH_ADD' SUBROUTINE

; This is the subroutine that increments the character address system variable
; and returns if it is not the cursor character. The ZX81 has an actual 
; character at the cursor position rather than a pointer system variable
; as is the case with prior and subsequent ZX computers.

mark_0049:
CH_ADD_PLUS_1:
	LD	HL,(CH_ADD)	; fetch character address to CH_ADD.

mark_004C:
TEMP_PTR1:
	INC	HL		; address next immediate location.

mark_004D:
TEMP_PTR2:
	LD	(CH_ADD),HL	; update system variable CH_ADD.

	LD	A,(HL)		; fetch the character.
	CP	ZX_CURSOR	; compare to cursor character.
	RET	NZ		; return if not the cursor.

	JR	TEMP_PTR1	; back for next character to TEMP_PTR1.

; THE 'ERROR_2' BRANCH

; This is a continuation of the error restart.
; If the error occurred in runtime then the error stack pointer will probably
; lead to an error report being printed unless it occurred during input.
; If the error occurred when checking syntax then the error stack pointer
; will be an editing routine and the position of the error will be shown
; when the lower screen is reprinted.

mark_0056:
ERROR_2:
	POP	HL		; pop the return address which points to the
				; DEFB, error code, after the RST 08.
	LD	L,(HL)		; load L with the error code. HL is not needed
				; anymore.

mark_0058:
ERROR_3:
	LD	(IY+ERR_NR-RAMBASE),L	; place error code in system variable ERR_NR
	LD	SP,(ERR_SP)	; set the stack pointer from ERR_SP
	CALL	SLOW_FAST	; selects slow mode.
	JP	SET_MIN		; exit to address on stack via routine SET_MIN.

; ___

	DEFB	$FF		; unused.

; THE 'NON MASKABLE INTERRUPT' ROUTINE

;	Jim Westwood's technical dodge using Non-Maskable Interrupts solved the
;	flicker problem of the ZX80 and gave the ZX81 a multi-tasking SLOW mode 
;	with a steady display.	Note that the AF' register is reserved for this 
;	function and its interaction with the display routines.	When counting 
;	TV lines, the NMI makes no use of the main registers.
;	The circuitry for the NMI generator is contained within the SCL (Sinclair 
;	Computer Logic) chip. 
;	( It takes 32 clock cycles while incrementing towards zero ). 

mark_0066:
NMI:
	EX	AF,AF'		; (4) switch in the NMI's copy of the 
				;	accumulator.
	INC	A		; (4) increment.
	JP	M,NMI_RET	; (10/10) jump, if minus, to NMI_RET as this is
				;	part of a test to see if the NMI 
				;	generation is working or an intermediate 
				;	value for the ascending negated blank 
				;	line counter.

	JR	Z,NMI_CONT	; (12) forward to NMI_CONT
				;	when line count has incremented to zero.

; Note. the synchronizing NMI when A increments from zero to one takes this
; 7 clock cycle route making 39 clock cycles in all.

mark_006D:
NMI_RET:
	EX	AF,AF'		; (4)	switch out the incremented line counter
				;	or test result $80
	RET			; (10) return to User application for a while.

; ___

;	This branch is taken when the 55 (or 31) lines have been drawn.

mark_006F:
NMI_CONT:
	EX	AF,AF'		; (4) restore the main accumulator.

	PUSH	AF		; (11) *		Save Main Registers
	PUSH	BC		; (11) **
	PUSH	DE		; (11) ***
	PUSH	HL		; (11) ****

;	the next set-up procedure is only really applicable when the top set of 
;	blank lines have been generated.

	LD	HL,(D_FILE)	; (16) fetch start of Display File from D_FILE
				;      points to the HALT at beginning.
	SET	7,H		; (8)  point to upper 32K 'echo display file'

	HALT			; (1)  HALT synchronizes with NMI.
				;      Used with special hardware connected to the
				;      Z80 HALT and WAIT lines to take 1 clock cycle.

;	the NMI has been generated - start counting.
;	The cathode ray is at the RH side of the TV.
;
;	First the NMI servicing, similar to CALL		=	17 clock cycles.
;	Then the time taken by the NMI for zero-to-one path	=	39 cycles
;	The HALT above						=	01 cycles.
;	The two instructions below				=	19 cycles.
;	The code at R_IX_1 up to and including the CALL		=	43 cycles.
;	The Called routine at DISPLAY_5				=	24 cycles.
;	--------------------------------------				---
;	Total Z80 instructions					=	143 cycles.
;
;	Meanwhile in TV world,
;	Horizontal retrace					=	15 cycles.
;	Left blanking border 8 character positions		=	32 cycles
;	Generation of 75% scanline from the first NEWLINE	=	96 cycles
;	---------------------------------------				---
;								=	143 cycles
;
;	Since at the time the first JP (HL) is encountered to execute the echo
;	display another 8 character positions have to be put out, then the
;	Refresh register need to hold $F8. Working back and counteracting 
;	the fact that every instruction increments the Refresh register then
;	the value that is loaded into R needs to be $F5.	:-)
;
;
	OUT	(IO_PORT_NMI_GEN_OFF),A		; (11) Stop the NMI generator.

	JP	(IX)				; (8) forward to R_IX_1 (after top) or R_IX_2

; ****************
; ** KEY TABLES **
; ****************

; THE 'UNSHIFTED' CHARACTER CODES

mark_007E:
K_UNSHIFT:
	DEFB	ZX_Z
	DEFB	ZX_X
	DEFB	ZX_C
	DEFB	ZX_V

	DEFB	ZX_A
	DEFB	ZX_S
	DEFB	ZX_D
	DEFB	ZX_F
	DEFB	ZX_G

	DEFB	ZX_Q
	DEFB	ZX_W
	DEFB	ZX_E
	DEFB	ZX_R
	DEFB	ZX_T

	DEFB	ZX_1
	DEFB	ZX_2
	DEFB	ZX_3
	DEFB	ZX_4
	DEFB	ZX_5

	DEFB	ZX_0
	DEFB	ZX_9
	DEFB	ZX_8
	DEFB	ZX_7
	DEFB	ZX_6

	DEFB	ZX_P
	DEFB	ZX_O
	DEFB	ZX_I
	DEFB	ZX_U
	DEFB	ZX_Y

	DEFB	ZX_NEWLINE
	DEFB	ZX_L
	DEFB	ZX_K
	DEFB	ZX_J
	DEFB	ZX_H

	DEFB	ZX_SPACE
	DEFB	ZX_PERIOD
	DEFB	ZX_M
	DEFB	ZX_N
	DEFB	ZX_B

; THE 'SHIFTED' CHARACTER CODES

mark_00A5:
K_SHIFT:
	DEFB	ZX_COLON	; :
	DEFB	ZX_SEMICOLON	; ;
	DEFB	ZX_QUERY	; ?
	DEFB	ZX_SLASH	; /
	DEFB	ZX_STOP
	DEFB	ZX_LPRINT
	DEFB	ZX_SLOW
	DEFB	ZX_FAST
	DEFB	ZX_LLIST
	DEFB	$C0		; ""
	DEFB	ZX_OR
	DEFB	ZX_STEP
	DEFB	$DB		; <=
	DEFB	$DD		; <>
	DEFB	ZX_EDIT
	DEFB	ZX_AND
	DEFB	ZX_THEN
	DEFB	ZX_TO
	DEFB	$72		; cursor-left
	DEFB	ZX_RUBOUT
	DEFB	ZX_GRAPHICS
	DEFB	$73		; cursor-right
	DEFB	$70		; cursor-up
	DEFB	$71		; cursor-down
	DEFB	ZX_QUOTE	; "
	DEFB	$11		; )
	DEFB	$10		; (
	DEFB	ZX_DOLLAR	; $
	DEFB	$DC		; >=
	DEFB	ZX_FUNCTION
	DEFB	ZX_EQUAL
	DEFB	ZX_PLUS
	DEFB	ZX_MINUS
	DEFB	ZX_POWER	; **
	DEFB	ZX_POUND	; £ 
	DEFB	ZX_COMMA	; ,
	DEFB	ZX_GREATER_THAN	; >
	DEFB	ZX_LESS_THAN	; <
	DEFB	ZX_STAR		; *

; THE 'FUNCTION' CHARACTER CODES

mark_00CC:
K_FUNCT:
	DEFB	ZX_LN
	DEFB	ZX_EXP
	DEFB	ZX_AT
	DEFB	ZX_KL
	DEFB	ZX_ASN
	DEFB	ZX_ACS
	DEFB	ZX_ATN
	DEFB	ZX_SGN
	DEFB	ZX_ABS
	DEFB	ZX_SIN
	DEFB	ZX_COS
	DEFB	ZX_TAN
	DEFB	ZX_INT
	DEFB	ZX_RND
	DEFB	ZX_KL
	DEFB	ZX_KL
	DEFB	ZX_KL
	DEFB	ZX_KL
	DEFB	ZX_KL
	DEFB	ZX_KL
	DEFB	ZX_KL
	DEFB	ZX_KL
	DEFB	ZX_KL
	DEFB	ZX_KL
	DEFB	ZX_TAB
	DEFB	ZX_PEEK
	DEFB	ZX_CODE
	DEFB	ZX_CHR_STR	;	CHR$
	DEFB	ZX_STR_STR	;	STR$
	DEFB	ZX_KL
	DEFB	ZX_USR
	DEFB	ZX_LEN
	DEFB	ZX_VAL
	DEFB	ZX_SQR
	DEFB	ZX_KL
	DEFB	ZX_KL
	DEFB	ZX_PI
	DEFB	ZX_NOT
	DEFB	ZX_INKEY_STR

; THE 'GRAPHIC' CHARACTER CODES

mark_00F3:
K_GRAPH:
	DEFB	$08		; graphic
	DEFB	$0A		; graphic
	DEFB	$09		; graphic
	DEFB	$8A		; graphic
	DEFB	$89		; graphic

	DEFB	$81		; graphic
	DEFB	$82		; graphic
	DEFB	$07		; graphic
	DEFB	$84		; graphic
	DEFB	$06		; graphic

	DEFB	$01		; graphic
	DEFB	$02		; graphic
	DEFB	$87		; graphic
	DEFB	$04		; graphic
	DEFB	$05		; graphic

	DEFB	ZX_RUBOUT
	DEFB	ZX_KL
	DEFB	$85		; graphic
	DEFB	$03		; graphic
	DEFB	$83		; graphic

	DEFB	$8B		; graphic
	DEFB	$91		; inverse )
	DEFB	$90		; inverse (
	DEFB	$8D		; inverse $
	DEFB	$86		; graphic

	DEFB	ZX_KL
	DEFB	$92		; inverse >
	DEFB	$95		; inverse +
	DEFB	$96		; inverse -
	DEFB	$88		; graphic

; THE 'TOKEN' TABLES

mark_0111:
TOKEN_TABLE:
	DEFB	ZX_QUERY						+$80; '?'
	DEFB	ZX_QUOTE,	ZX_QUOTE				+$80; ""
	DEFB	ZX_A,	ZX_T						+$80; AT
	DEFB	ZX_T,	ZX_A,	ZX_B					+$80; TAB
	DEFB	ZX_QUERY						+$80; '?'
	DEFB	ZX_C,	ZX_O,	ZX_D,	ZX_E				+$80; CODE
	DEFB	ZX_V,	ZX_A,	ZX_L					+$80; VAL
	DEFB	ZX_L,	ZX_E,	ZX_N					+$80; LEN
	DEFB	ZX_S,	ZX_I,	ZX_N					+$80; SIN
	DEFB	ZX_C,	ZX_O,	ZX_S					+$80; COS
	DEFB	ZX_T,	ZX_A,	ZX_N					+$80; TAN
	DEFB	ZX_A,	ZX_S,	ZX_N					+$80; ASN
	DEFB	ZX_A,	ZX_C,	ZX_S					+$80; ACS
	DEFB	ZX_A,	ZX_T,	ZX_N					+$80; ATN
	DEFB	ZX_L,	ZX_N						+$80; LN
	DEFB	ZX_E,	ZX_X,	ZX_P					+$80; EXP
	DEFB	ZX_I,	ZX_N,	ZX_T					+$80; INT
	DEFB	ZX_S,	ZX_Q,	ZX_R					+$80; SQR
	DEFB	ZX_S,	ZX_G,	ZX_N					+$80; SGN
	DEFB	ZX_A,	ZX_B,	ZX_S					+$80; ABS
	DEFB	ZX_P,	ZX_E,	ZX_E,	ZX_K				+$80; PEEK
	DEFB	ZX_U,	ZX_S,	ZX_R					+$80; USR
	DEFB	ZX_S,	ZX_T,	ZX_R,	ZX_DOLLAR			+$80; STR$
	DEFB	ZX_C,	ZX_H,	ZX_R,	ZX_DOLLAR			+$80; CHR$
	DEFB	ZX_N,	ZX_O,	ZX_T					+$80; NOT
	DEFB	ZX_STAR,	ZX_STAR					+$80; **
	DEFB	ZX_O,	ZX_R						+$80; OR
	DEFB	ZX_A,	ZX_N,	ZX_D					+$80; AND
	DEFB	ZX_LESS_THAN,		ZX_EQUAL			+$80; >=
	DEFB	ZX_GREATER_THAN,	ZX_EQUAL			+$80; <=
	DEFB	ZX_LESS_THAN,		ZX_GREATER_THAN			+$80; ><
	DEFB	ZX_T,	ZX_H,	ZX_E,	ZX_N				+$80; THEN
	DEFB	ZX_T,	ZX_O						+$80; TO
	DEFB	ZX_S,	ZX_T,	ZX_E,	ZX_P				+$80; STEP
	DEFB	ZX_L,	ZX_P,	ZX_R,	ZX_I,	ZX_N,	ZX_T		+$80; LPRINT
	DEFB	ZX_L,	ZX_L,	ZX_I,	ZX_S,	ZX_T			+$80; LLIST
	DEFB	ZX_S,	ZX_T,	ZX_O,	ZX_P				+$80; STOP
	DEFB	ZX_S,	ZX_L,	ZX_O,	ZX_W				+$80; SLOW
	DEFB	ZX_F,	ZX_A,	ZX_S,	ZX_T				+$80; FAST
	DEFB	ZX_N,	ZX_E,	ZX_W					+$80; NEW
	DEFB	ZX_S,	ZX_C,	ZX_R,	ZX_O,	ZX_L,	ZX_L		+$80; SCROLL
	DEFB	ZX_C,	ZX_O,	ZX_N,	ZX_T				+$80; CONT
	DEFB	ZX_D,	ZX_I,	ZX_M					+$80; DIM
	DEFB	ZX_R,	ZX_E,	ZX_M					+$80; REM
	DEFB	ZX_F,	ZX_O,	ZX_R					+$80; FOR
	DEFB	ZX_G,	ZX_O,	ZX_T,	ZX_O				+$80; GOTO
	DEFB	ZX_G,	ZX_O,	ZX_S,	ZX_U,	ZX_B			+$80; GOSUB
	DEFB	ZX_I,	ZX_N,	ZX_P,	ZX_U,	ZX_T			+$80; INPUT
	DEFB	ZX_L,	ZX_O,	ZX_A,	ZX_D				+$80; LOAD
	DEFB	ZX_L,	ZX_I,	ZX_S,	ZX_T				+$80; LIST
	DEFB	ZX_L,	ZX_E,	ZX_T					+$80; LET
	DEFB	ZX_P,	ZX_A,	ZX_U,	ZX_S,	ZX_E			+$80; PAUSE
	DEFB	ZX_N,	ZX_E,	ZX_X,	ZX_T				+$80; NEXT
	DEFB	ZX_P,	ZX_O,	ZX_K,	ZX_E				+$80; POKE
	DEFB	ZX_P,	ZX_R,	ZX_I,	ZX_N,	ZX_T			+$80; PRINT
	DEFB	ZX_P,	ZX_L,	ZX_O,	ZX_T				+$80; PLOT
	DEFB	ZX_R,	ZX_U,	ZX_N					+$80; RUN
	DEFB	ZX_S,	ZX_A,	ZX_V,	ZX_E				+$80; SAVE
	DEFB	ZX_R,	ZX_A,	ZX_N,	ZX_D				+$80; RAND
	DEFB	ZX_I,	ZX_F						+$80; IF
	DEFB	ZX_C,	ZX_L,	ZX_S					+$80; CLS
	DEFB	ZX_U,	ZX_N,	ZX_P,	ZX_L,	ZX_O,	ZX_T		+$80; UNPLOT
	DEFB	ZX_C,	ZX_L,	ZX_E,	ZX_A,	ZX_R			+$80; CLEAR
	DEFB	ZX_R,	ZX_E,	ZX_T,	ZX_U,	ZX_R,	ZX_N		+$80; RETURN
	DEFB	ZX_C,	ZX_O,	ZX_P,	ZX_Y				+$80; COPY
	DEFB	ZX_R,	ZX_N,	ZX_D					+$80; RND
	DEFB	ZX_I,	ZX_N,	ZX_K,	ZX_E,	ZX_Y,	ZX_DOLLAR	+$80; INKEY$
	DEFB	ZX_P,	ZX_I						+$80; PI

; THE 'LOAD_SAVE UPDATE' ROUTINE

;
;

mark_01FC:
LOAD_SAVE:
	INC	HL		;
	EX	DE,HL		;
	LD	HL,(E_LINE)	; system variable edit line E_LINE.
	SCF			; set carry flag
	SBC	HL,DE		;
	EX	DE,HL		;
	RET	NC		; return if more bytes to LOAD_SAVE.

	POP	HL		; else drop return address

; THE 'DISPLAY' ROUTINES

;
;

mark_0207:
SLOW_FAST:
	LD	HL,CDFLAG	; Address the system variable CDFLAG.
	LD	A,(HL)		; Load value to the accumulator.
	RLA			; rotate bit 6 to position 7.
	XOR	(HL)		; exclusive or with original bit 7.
	RLA			; rotate result out to carry.
	RET	NC		; return if both bits were the same.

;	Now test if this really is a ZX81 or a ZX80 running the upgraded ROM.
;	The standard ZX80 did not have an NMI generator.

	LD	A,$7F		; Load accumulator with %011111111
	EX	AF,AF'		; save in AF'

	LD	B,17		; A counter within which an NMI should occur
				; if this is a ZX81.
	OUT	(IO_PORT_NMI_GEN_ON),A	; start the NMI generator.

;	Note that if this is a ZX81 then the NMI will increment AF'.

mark_0216:
LOOP_11:

	DJNZ	LOOP_11		; self loop to give the NMI a chance to kick in.
				; = 16*13 clock cycles + 8 = 216 clock cycles.

	OUT	(IO_PORT_NMI_GEN_OFF),A	; Turn off the NMI generator.
	EX	AF,AF'		; bring back the AF' value.
	RLA			; test bit 7.
	JR	NC,NO_SLOW	; forward, if bit 7 is still reset, to NO_SLOW.

;	If the AF' was incremented then the NMI generator works and SLOW mode can
;	be set.

	SET	7,(HL)		; Indicate SLOW mode - Compute and Display.

	PUSH	AF		; *		Save Main Registers
	PUSH	BC		; **
	PUSH	DE		; ***
	PUSH	HL		; ****

	JR	DISPLAY_1	; skip forward - to DISPLAY_1.

; ___

mark_0226:
NO_SLOW:
	RES	6,(HL)		; reset bit 6 of CDFLAG.
	RET			; return.

; THE 'MAIN DISPLAY' LOOP

; This routine is executed once for every frame displayed.

mark_0229:
DISPLAY_1:

	LD	HL,(FRAMES)	; fetch two-byte system variable FRAMES.
	DEC	HL		; decrement frames counter.
mark_022D:
DISPLAY_P:
	LD	A,$7F		; prepare a mask
	AND	H		; pick up bits 6-0 of H.
	OR	L		; and any bits of L.
	LD	A,H		; reload A with all bits of H for PAUSE test.

;	Note both branches must take the same time.

	JR	NZ,ANOTHER	; (12/7) forward if bits 14-0 are not zero 
				; to ANOTHER

	RLA			; (4) test bit 15 of FRAMES.
	JR	OVER_NC		; (12) forward with result to OVER_NC

; ___

mark_0237:
ANOTHER:
	LD	B,(HL)		; (7) Note. Harmless Nonsensical Timing weight.
	SCF			; (4) Set Carry Flag.

; Note. the branch to here takes either (12)(7)(4) cyles or (7)(4)(12) cycles.

mark_0239:
OVER_NC:
	LD	H,A		; (4)	set H to zero
	LD	(FRAMES),HL	; (16) update system variable FRAMES 
	RET	NC		; (11/5) return if FRAMES is in use by PAUSE 
				; command.

mark_023E:
DISPLAY_2:
	CALL	KEYBOARD	; gets the key row in H and the column in L. 
				; Reading the ports also starts
				; the TV frame synchronization pulse. (VSYNC)

	LD	BC,(LAST_K)	; fetch the last key values
	LD	(LAST_K),HL	; update LAST_K with new values.

	LD	A,B		; load A with previous column - will be $FF if
				; there was no key.
	ADD	A,2		; adding two will set carry if no previous key.

	SBC	HL,BC		; subtract with the carry the two key values.

; If the same key value has been returned twice then HL will be zero.

	LD	A,(DEBOUNCE_VAR)
	OR	H		; and OR with both bytes of the difference
	OR	L		; setting the zero flag for the upcoming branch.

	LD	E,B		; transfer the column value to E
	LD	B,11		; and load B with eleven 

	LD	HL,CDFLAG	; address system variable CDFLAG
	RES	0,(HL)		; reset the rightmost bit of CDFLAG
	JR	NZ,NO_KEY	; skip forward if debounce/diff >0 to NO_KEY

	BIT	7,(HL)		; test compute and display bit of CDFLAG
	SET	0,(HL)		; set the rightmost bit of CDFLAG.
	RET	Z		; return if bit 7 indicated fast mode.

	DEC	B		; (4) decrement the counter.
	NOP			; (4) Timing - 4 clock cycles. ??
	SCF			; (4) Set Carry Flag

mark_0264:
NO_KEY:

	LD	HL,DEBOUNCE_VAR	;
	CCF			; Complement Carry Flag
	RL	B		; rotate left B picking up carry
				;	C<-76543210<-C

mark_026A:
LOOP_B:

	DJNZ	LOOP_B		; self-loop while B>0 to LOOP_B

	LD	B,(HL)		; fetch value of DEBOUNCE_VAR to B
	LD	A,E		; transfer column value
	CP	$FE		;
	SBC	A,A		; A = A-A-C = 0-Carry
#if 1
; I think this truncating DEBOUNCE_VAR 
; which would explain why the VSYNC time didn't match
; my calculations that assumed debouncing for 255 loops.
;
;
	LD	B,$1F		; binary 000 11111
	OR	(HL)		;
	AND	B		; truncate column, 0 to 31
#endif
	RRA			;
	LD	(HL),A		;

	OUT	(IO_PORT_SCREEN),A	; end the TV frame synchronization pulse.

	LD	HL,(D_FILE)	; (12) set HL to the Display File from D_FILE
	SET	7,H		; (8) set bit 15 to address the echo display.

	CALL	DISPLAY_3	; (17) routine DISPLAY_3 displays the top set 
				; of blank lines.

; THE 'VIDEO_1' ROUTINE

mark_0281:
R_IX_1:
	LD	A,R		; (9)	Harmless Nonsensical Timing
				;	or something very clever?
	LD	BC,25*256+1	; (10)	25 lines, 1 scanline in first. ($1901)

; 32 characters, use $F5 (i.e. minus 11)
; 40 characters, use $ED (i.e. minus 19)
;

mark_0286:
	LD	A,277-CHARS_PER_LINE_WINDOW	; $F5 for 6.5MHz clocked machines
				; (7)	This value will be loaded into R and 
				; ensures that the cycle starts at the right 
				; part of the display	- after last character 
				; position.

	CALL	DISPLAY_5	; (17) routine DISPLAY_5 completes the current 
				; blank line and then generates the display of 
				; the live picture using INT interrupts
				; The final interrupt returns to the next 
				; address.
R_IX_1_LAST_NEWLINE:
	DEC	HL		; point HL to the last NEWLINE/HALT.

	CALL	DISPLAY_3	; displays the bottom set of blank lines.

; ___

mark_028F:
R_IX_2:
	JP	DISPLAY_1	; JUMP back to DISPLAY_1

; THE 'DISPLAY BLANK LINES' ROUTINE 

;	This subroutine is called twice (see above) to generate first the blank 
;	lines at the top of the television display and then the blank lines at the
;	bottom of the display. 
;
;	It is actually pretty bad.
;	PAL or NTSC = 312 or 
;   1 to   5 = 5 long and 5 short sync
;   6 to  23 = blank
;  24 to 309 = image
; 310 to 312 = 6 short sync
;
; The ZX80 generates either 62 or 110 blank lines
;
; 262 - 31 - 31 = 200
; 312 - 55 - 55 = 202
;
; This does not include 'VSYNC' line periods.
;

mark_0292:
DISPLAY_3:
	POP	IX		; pop the return address to IX register.
				; will be either R_IX_1 or R_IX_2 - see above.

	LD	C,(IY+MARGIN-RAMBASE)	; load C with value of system constant MARGIN.
	BIT	7,(IY+CDFLAG-RAMBASE)	; test CDFLAG for compute and display.
	JR	Z,DISPLAY_4	; forward, with FAST mode, to DISPLAY_4

	LD	A,C		; move MARGIN to A	- 31d or 55d.
	NEG			; Negate
	INC	A		;
	EX	AF,AF'		; place negative count of blank lines in A'

	OUT	(IO_PORT_NMI_GEN_ON),A	; enable the NMI generator.

	POP	HL		; ****
	POP	DE		; ***
	POP	BC		; **
	POP	AF		; *		Restore Main Registers

	RET			; return - end of interrupt.	Return is to 
				; user's program - BASIC or machine code.
				; which will be interrupted by every NMI.

; THE 'FAST MODE' ROUTINES

mark_02A9:

DISPLAY_4:

	LD	A,284-CHARS_PER_LINE_WINDOW	; $FC for 6.5MHz clocked machines
				; (7)	load A with first R delay value

	LD	B,1		; (7)	one row only.

	CALL	DISPLAY_5	; (17) routine DISPLAY_5

	DEC	HL		; (6)	point back to the HALT.
	EX	(SP),HL		; (19) Harmless Nonsensical Timing if paired.
	EX	(SP),HL		; (19) Harmless Nonsensical Timing.
	JP	(IX)		; (8)	to R_IX_1 or R_IX_2

; THE 'DISPLAY_5' SUBROUTINE

;	This subroutine is called from SLOW mode and FAST mode to generate the 
;	central TV picture. With SLOW mode the R register is incremented, with
;	each instruction, to $F7 by the time it completes.	With fast mode, the 
;	final R value will be $FF and an interrupt will occur as soon as the 
;	Program Counter reaches the HALT.	(24 clock cycles)

mark_02B5:
DISPLAY_5:
	LD	R,A		; (9) Load R from A.	R = slow: $F5 fast: $FC

;; Original, for 32 column display:
;;
;;	LD	A,$DD		; (7) load future R value.	$F6	$FD
;;
;; For other display widths,
;; need to count down three instructions then the number of characters
;;
	LD	A,256-3-CHARS_PER_LINE_WINDOW	; (7) load future R value.	$F6	$FD

	EI			; (4) Enable Interrupts		$F7	$FE

	JP	(HL)		; (4) jump to the echo display.	$F8	$FF

; THE 'KEYBOARD SCANNING' SUBROUTINE

; The keyboard is read during the vertical sync interval while no video is 
; being displayed.	Reading a port with address bit 0 low i.e. $FE starts the 
; vertical sync pulse.

mark_02BB:
KEYBOARD:
	LD	HL,$FFFF	; (16) prepare a buffer to take key.
	LD	BC,$FEFE	; (20) set BC to port $FEFE. The B register, 
				;	with its single reset bit also acts as 
				;	an 8-counter.
	IN	A,(C)		; (11) read the port - all 16 bits are put on 
				;	the address bus.	Start VSYNC pulse.
	OR	$01		; (7)	set the rightmost bit so as to ignore 
				;	the SHIFT key.

mark_02C5:
EACH_LINE:
	OR	$E0		; [7] OR %11100000
	LD	D,A		; [4] transfer to D.
	CPL			; [4] complement - only bits 4-0 meaningful now.
	CP	1		; [7] sets carry if A is zero.
	SBC	A,A		; [4] $FF if $00 else zero.
	OR	B		; [7] $FF or port FE,FD,FB....
	AND	L		; [4] unless more than one key, L will still be 
				;	$FF. if more than one key is pressed then A is 
				;	now invalid.
	LD	L,A		; [4] transfer to L.

; now consider the column identifier.

	LD	A,H		; [4] will be $FF if no previous keys.
	AND	D		; [4] 111xxxxx
	LD	H,A		; [4] transfer A to H

; since only one key may be pressed, H will, if valid, be one of
; 11111110, 11111101, 11111011, 11110111, 11101111
; reading from the outer column, say Q, to the inner column, say T.

	RLC	B		; [8]	rotate the 8-counter/port address.
				;	sets carry if more to do.
	IN	A,(C)		; [10] read another half-row.
				;	all five bits this time.

	JR	C,EACH_LINE	; [12](7) loop back, until done, to EACH_LINE

;	The last row read is SHIFT,Z,X,C,V	for the second time.

	RRA			; (4) test the shift key - carry will be reset
				;	if the key is pressed.
	RL	H		; (8) rotate left H picking up the carry giving
				;	column values -
				;	$FD, $FB, $F7, $EF, $DF.
				;	or $FC, $FA, $F6, $EE, $DE if shifted.

;	We now have H identifying the column and L identifying the row in the
;	keyboard matrix.

;	This is a good time to test if this is an American or British machine.
;	The US machine has an extra diode that causes bit 6 of a byte read from
;	a port to be reset.

	RLA			; (4) compensate for the shift test.
	RLA			; (4) rotate bit 7 out.
	RLA			; (4) test bit 6.

	SBC	A,A		; (4)		$FF or 0 {USA}
	AND	$18		; (7)		24 or 0
	ADD	A,31		; (7)		55 or 31

;	result is either 31 (USA) or 55 (UK) blank lines above and below the TV 
;	picture.

	LD	(MARGIN),A	; (13) update system variable MARGIN

	RET			; (10) return

; THE 'SET FAST MODE' SUBROUTINE

;
;

mark_02E7:
SET_FAST:
	BIT	7,(IY+CDFLAG-RAMBASE)
	RET	Z		;

	HALT			; Wait for Interrupt
	OUT	(IO_PORT_NMI_GEN_OFF),A	;
	RES	7,(IY+CDFLAG-RAMBASE)
	RET			; return.

; THE 'REPORT_F'

mark_02F4:
REPORT_F:
	RST	_ERROR_1
	DEFB	$0E		; Error Report: No Program Name supplied.

; THE 'SAVE COMMAND' ROUTINE

;
;

mark_02F6:
SAVE:
	CALL	NAME
	JR	C,REPORT_F	; back with null name

	EX	DE,HL		;

;
; The next 6 bytes differ
;
#if NOT_BODGED
; what ZASM assembled:
; 02FC: 11CB12
	LD	DE,$12CB	; five seconds timing value (4811 decimal)
; 02FF: CD460F
mark_02FF:
HEADER:
	CALL	BREAK_1

#else
; what the SG ROM disassembled to:
;	02FC   ED;FD
			LDIR			; Patch tape SAVE
;	02FE   C3;07;02
			JP	SLOW_FAST	; to $0207
;	0301   0F
			RRCA
#endif

mark_0302:
	JR	NC,BREAK_2

mark_0304:
DELAY_1:
	DJNZ	DELAY_1

	DEC	DE		;
	LD	A,D		;
	OR	E		;
	JR	NZ,HEADER	; back for delay to HEADER

mark_030B:
OUT_NAME:
	CALL	OUT_BYTE
	BIT	7,(HL)		; test for inverted bit.
	INC	HL		; address next character of name.
	JR	Z,OUT_NAME	; back if not inverted to OUT_NAME

; now start saving the system variables onwards.

	LD	HL,VERSN	; set start of area to VERSN thereby
				; preserving RAMTOP etc.

mark_0316:
OUT_PROG:
	CALL	OUT_BYTE

	CALL	LOAD_SAVE	; 			>>
	JR	OUT_PROG	; loop back

; THE 'OUT_BYTE' SUBROUTINE

; This subroutine outputs a byte a bit at a time to a domestic tape recorder.

mark_031E:
OUT_BYTE:
	LD	E,(HL)		; fetch byte to be saved.
	SCF			; set carry flag - as a marker.

mark_0320:
EACH_BIT:
	RL	E		; C < 76543210 < C
	RET	Z		; return when the marker bit has passed 
				; right through.			>>

	SBC	A,A		; $FF if set bit or $00 with no carry.
	AND	$05		; $05 "  "   "   "  $00
	ADD	A,$04		; $09 "  "   "   "  $04
	LD	C,A		; transfer timer to C. a set bit has a longer
				; pulse than a reset bit.

mark_0329:
PULSES:
	OUT	(IO_PORT_TAPE),A	; pulse to cassette.
	LD	B,$23		; set timing constant

mark_032D:
DELAY_2:
	DJNZ	DELAY_2		; self-loop

	CALL	BREAK_1		; test for BREAK key.

mark_0332:
BREAK_2:
	JR	NC,REPORT_D	; forward with break to REPORT_D

	LD	B,$1E		; set timing value.

mark_0336:
DELAY_3:

	DJNZ	DELAY_3		; self-loop

	DEC	C		; decrement counter
	JR	NZ,PULSES	; loop back

mark_033B:
DELAY_4:
	AND	A		; clear carry for next bit test.
	DJNZ	DELAY_4		; self loop (B is zero - 256)

	JR	EACH_BIT	; loop back

; THE 'LOAD COMMAND' ROUTINE

mark_0340:
LOAD:
	CALL	NAME

; DE points to start of name in RAM.

	RL	D		; pick up carry 
	RRC	D		; carry now in bit 7.

mark_0347:

#if NOT_BODGED

LNEXT_PROG:
	CALL	IN_BYTE
	JR	LNEXT_PROG	; loop

; THE 'IN_BYTE' SUBROUTINE

mark_034C:
IN_BYTE:
	LD	C,$01		; prepare an eight counter 00000001.

mark_034E:
NEXT_BIT:
	LD	B,$00		; set counter to 256

#else
; what the SG ROM has:
;0347   EB
			EX DE,HL            ; NEXT-PROG
;0348   ED;FC
			LDIR                ; Patch tape LOAD
;034A   C3;07;02
			JP SLOW_FAST
;034D   01;06;00
			LD BC,6          
#endif

mark_0350:
BREAK_3:
	LD	A,$7F		; read the keyboard row 
	IN	A,(IO_PORT_KEYBOARD_RD)	; with the SPACE key.

	OUT	(IO_PORT_SCREEN),A	; output signal to screen.

	RRA			; test for SPACE pressed.
	JR	NC,BREAK_4	; forward if so to BREAK_4

	RLA			; reverse above rotation
	RLA			; test tape bit.
	JR	C,GET_BIT	; forward if set to GET_BIT

	DJNZ	BREAK_3		; loop back

	POP	AF		; drop the return address.
	CP	D		; ugh.

mark_0361:
RESTART:
	JP	NC,INITIAL	; jump forward to INITIAL if D is zero 
				; to reset the system
				; if the tape signal has timed out for example
				; if the tape is stopped. Not just a simple 
				; report as some system variables will have
				; been overwritten.

	LD	H,D		; else transfer the start of name
	LD	L,E		; to the HL register

mark_0366:
IN_NAME:
	CALL	IN_BYTE		; is sort of recursion for name
				; part. received byte in C.
	BIT	7,D		; is name the null string ?
	LD	A,C		; transfer byte to A.
	JR	NZ,MATCHING	; forward with null string

	CP	(HL)		; else compare with string in memory.
	JR	NZ,LNEXT_PROG	; back with mis-match
				; (seemingly out of subroutine but return 
				; address has been dropped).

mark_0371:
MATCHING:
	INC	HL		; address next character of name
	RLA			; test for inverted bit.
	JR	NC,IN_NAME	; back if not

; the name has been matched in full. 
; proceed to load the data but first increment the high byte of E_LINE, which
; is one of the system variables to be loaded in. Since the low byte is loaded
; before the high byte, it is possible that, at the in-between stage, a false
; value could cause the load to end prematurely - see	LOAD_SAVE check.

	INC	(IY+E_LINE_hi-RAMBASE)	; increment E_LINE_hi.
	LD	HL,VERSN	; start loading at VERSN.

mark_037B:
IN_PROG:
	LD	D,B		; set D to zero as indicator.
	CALL	IN_BYTE		; loads a byte
	LD	(HL),C		; insert assembled byte in memory.
	CALL	LOAD_SAVE		; 		>>
	JR	IN_PROG		; loop back

; ___

; this branch assembles a full byte before exiting normally
; from the IN_BYTE subroutine.

mark_0385:
GET_BIT:
	PUSH	DE		; save the 
	LD	E,$94		; timing value.

mark_0388:
TRAILER:
	LD	B,26		; counter to twenty six.

mark_038A:
COUNTER:
	DEC	E		; decrement the measuring timer.
	IN	A,(IO_PORT_KEYBOARD_RD)	; read the tape input
	RLA			;
	BIT	7,E		;
	LD	A,E		;
	JR	C,TRAILER	; loop back with carry to TRAILER

	DJNZ	COUNTER

	POP	DE		;
	JR	NZ,BIT_DONE

	CP	$56		;
	JR	NC,NEXT_BIT

mark_039C:
BIT_DONE:
	CCF			; complement carry flag
	RL	C		;
	JR	NC,NEXT_BIT

	RET			; return with full byte.

; ___

; if break is pressed while loading data then perform a reset.
; if break pressed while waiting for program on tape then OK to break.

mark_03A2:
BREAK_4:
	LD	A,D		; transfer indicator to A.
	AND	A		; test for zero.
	JR	Z,RESTART	; back if so

mark_03A6:
REPORT_D:
	RST	_ERROR_1
	DEFB	$0C		; Error Report: BREAK - CONT repeats

; THE 'PROGRAM NAME' SUBROUTINE

mark_03A8:
NAME:
	CALL	SCANNING
	LD	A,(FLAGS)	; sv
	ADD	A,A		;
	JP	M,REPORT_C

	POP	HL		;
	RET	NC		;

	PUSH	HL		;
	CALL	SET_FAST
	CALL	STK_FETCH
	LD	H,D		;
	LD	L,E		;
	DEC	C		;
	RET	M		;

	ADD	HL,BC		;
	SET	7,(HL)		;
	RET			;

; THE 'NEW' COMMAND ROUTINE

mark_03C3:
NEW:
	CALL	SET_FAST
	LD	BC,(RAMTOP)	; fetch value of system variable RAMTOP
	DEC	BC		; point to last system byte.

; THE 'RAM CHECK' ROUTINE

mark_03CB:
RAM_CHECK:
	LD	H,B		;
	LD	L,C		;
	LD	A,$3F		;

mark_03CF:
RAM_FILL:
	LD	(HL),$02	;
	DEC	HL		;
	CP	H		;
	JR	NZ,RAM_FILL

mark_03D5:
RAM_READ:
	AND	A		;
	SBC	HL,BC		;
	ADD	HL,BC		;
	INC	HL		;
	JR	NC,SET_TOP

	DEC	(HL)		;
	JR	Z,SET_TOP

	DEC	(HL)		;
	JR	Z,RAM_READ

mark_03E2:
SET_TOP:
	LD	(RAMTOP),HL	; set system variable RAMTOP to first byte 
				; above the BASIC system area.

; THE 'INITIALIZATION' ROUTINE

mark_03E5:
INITIAL:
	LD	HL,(RAMTOP)	; fetch system variable RAMTOP.
	DEC	HL		; point to last system byte.
	LD	(HL),$3E	; make GO SUB end-marker $3E - too high for
				; high order byte of line number.
				; (was $3F on ZX80)
	DEC	HL		; point to unimportant low-order byte.
	LD	SP,HL		; and initialize the stack-pointer to this
				; location.
	DEC	HL		; point to first location on the machine stack
	DEC	HL		; which will be filled by next CALL/PUSH.
	LD	(ERR_SP),HL	; set the error stack pointer ERR_SP to
				; the base of the now empty machine stack.

; Now set the I register so that the video hardware knows where to find the
; character set. This ROM only uses the character set when printing to 
; the ZX Printer. The TV picture is formed by the external video hardware. 
; Consider also, that this 8K ROM can be retro-fitted to the ZX80 instead of 
; its original 4K ROM so the video hardware could be on the ZX80.

	LD	A,$1E		; address for this ROM is $1E00.
	LD	I,A		; set I register from A.
	IM	1		; select Z80 Interrupt Mode 1.

	LD	IY,ERR_NR	; set IY to the start of RAM so that the 
				; system variables can be indexed.

	LD	(IY+CDFLAG-RAMBASE),%01000000
				; Bit 6 indicates Compute and Display required.

	LD	HL,USER_RAM	; The first location after System Variables -
				; 16509 decimal.
	LD	(D_FILE),HL	; set system variable D_FILE to this value.
	LD	B,$19		; prepare minimal screen of 24 NEWLINEs
				; following an initial NEWLINE.

mark_0408:
LINE:
	LD	(HL),ZX_NEWLINE	; insert NEWLINE (HALT instruction)
	INC	HL		; point to next location.
	DJNZ	LINE		; loop back for all twenty five to LINE

	LD	(VARS),HL	; set system variable VARS to next location

	CALL	CLEAR		; sets $80 end-marker and the 
				; dynamic memory pointers E_LINE, STKBOT and
				; STKEND.

mark_0413:
N_L_ONLY:
	CALL	CURSOR_IN	; inserts the cursor and 
				; end-marker in the Edit Line also setting
				; size of lower display to two lines.

	CALL	SLOW_FAST	; selects COMPUTE and DISPLAY

; THE 'BASIC LISTING' SECTION

mark_0419:
UPPER:
	CALL	CLS
	LD	HL,(E_PPC)	; sv
	LD	DE,(S_TOP)	; sv
	AND	A		;
	SBC	HL,DE		;
	EX	DE,HL		;
	JR	NC,ADDR_TOP

	ADD	HL,DE		;
	LD	(S_TOP),HL	; sv

mark_042D:
ADDR_TOP:
	CALL	LINE_ADDR
	JR	Z,LIST_TOP

	EX	DE,HL		;

mark_0433:
LIST_TOP:
	CALL	LIST_PROG
	DEC	(IY+BERG-RAMBASE)
	JR	NZ,LOWER

	LD	HL,(E_PPC)	; sv
	CALL	LINE_ADDR
	LD	HL,(CH_ADD)	; sv
	SCF			; Set Carry Flag
	SBC	HL,DE		;
	LD	HL,S_TOP	; sv
	JR	NC,INC_LINE

	EX	DE,HL		;
	LD	A,(HL)		;
	INC	HL		;
	LDI			;
	LD	(DE),A		;
	JR	UPPER
; ___

mark_0454:
DOWN_KEY:

	LD	HL,E_PPC	; sv

mark_0457:
INC_LINE:
	LD	E,(HL)		;
	INC	HL		;
	LD	D,(HL)		;
	PUSH	HL		;
	EX	DE,HL		;
	INC	HL		;
	CALL	LINE_ADDR
	CALL	LINE_NUM
	POP	HL		;

mark_0464:
KEY_INPUT:
	BIT	5,(IY+FLAGX-RAMBASE)
	JR	NZ,LOWER	; forward

	LD	(HL),D		;
	DEC	HL		;
	LD	(HL),E		;
	JR	UPPER

; THE 'EDIT LINE COPY' SECTION

; This routine sets the edit line to just the cursor when
; 1) There is not enough memory to edit a BASIC line.
; 2) The edit key is used during input.
; The entry point LOWER

mark_046F:
EDIT_INP:
	CALL	CURSOR_IN	; sets cursor only edit line.

; ->

mark_0472:
LOWER:
	LD	HL,(E_LINE)	; fetch edit line start from E_LINE.

mark_0475:
EACH_CHAR:
	LD	A,(HL)		; fetch a character from edit line.
	CP	$7E		; compare to the number marker.
	JR	NZ,END_LINE	; forward if not

	LD	BC,6		; else six invisible bytes to be removed.
	CALL	RECLAIM_2
	JR	EACH_CHAR	; back
; ___

mark_0482:
END_LINE:
	CP	ZX_NEWLINE		;
	INC	HL		;
	JR	NZ,EACH_CHAR

mark_0487:
EDIT_LINE:
	CALL	CURSOR		; sets cursor K or L.

mark_048A:
EDIT_ROOM:
	CALL	LINE_ENDS
	LD	HL,(E_LINE)	; sv
	LD	(IY+ERR_NR-RAMBASE),$FF
	CALL	COPY_LINE
	BIT	7,(IY+ERR_NR-RAMBASE)
	JR	NZ,DISPLAY_6

	LD	A,(DF_SZ)	; 
	CP	CHARS_VERTICAL	; $18 = 24
	JR	NC,DISPLAY_6

	INC	A		;
	LD	(DF_SZ),A	; 
	LD	B,A		;
	LD	C,1		;
	CALL	LOC_ADDR
	LD	D,H		;
	LD	E,L		;
	LD	A,(HL)		;

mark_04B1:
FREE_LINE:
	DEC	HL		;
	CP	(HL)		;
	JR	NZ,FREE_LINE

	INC	HL		;
	EX	DE,HL		;
	LD	A,(RAMTOP+1)	; sv RAMTOP_hi
	CP	$4D		;
	CALL	C,RECLAIM_1
	JR	EDIT_ROOM

; THE 'WAIT FOR KEY' SECTION

mark_04C1:
DISPLAY_6:
	LD	HL,$0000	;
	LD	(X_PTR),HL	; sv

	LD	HL,CDFLAG	; system variable CDFLAG

#if NOT_BODGED
	BIT	7,(HL)		;

	CALL	Z,DISPLAY_1

mark_04CF:
SLOW_DISP:
	BIT	0,(HL)		;
	JR	Z,SLOW_DISP

#else
;	04CA   D3;00
			OUT ($00),A         ; PORT 0
;	04CC   CB;46
L04CC:
			BIT 0,(HL)           
;	04CE   28;FC
			JR Z,L04CC
;	04D0   D3;01
			OUT ($01),A         ; PORT 1
;	04D2   00
			NOP

#endif

	LD	BC,(LAST_K)	; sv
	CALL	DEBOUNCE
	CALL	DECODE

	JR	NC,LOWER	; back

; THE 'KEYBOARD DECODING' SECTION

;	The decoded key value is in E and HL points to the position in the 
;	key table. D contains zero.

mark_04DF:
K_DECODE:
	LD	A,(MODE)	; Fetch value of system variable MODE
	DEC	A		; test the three values together

	JP	M,FETCH_2	; forward, if was zero

	JR	NZ,FETCH_1	; forward, if was 2

;	The original value was one and is now zero.

	LD	(MODE),A	; update the system variable MODE

	DEC	E		; reduce E to range $00 - $7F
	LD	A,E		; place in A
	SUB	39		; subtract 39 setting carry if range 00 - 38
	JR	C,FUNC_BASE	; forward, if so

	LD	E,A		; else set E to reduced value

mark_04F2:
FUNC_BASE:
	LD	HL,K_FUNCT	; address of K_FUNCT table for function keys.
	JR	TABLE_ADD	; forward
; ___
mark_04F7:
FETCH_1:
	LD	A,(HL)		;
	CP	ZX_NEWLINE	;
	JR	Z,K_L_KEY

	CP	ZX_RND		; $40
	SET	7,A		;
	JR	C,ENTER

	LD	HL,$00C7	; (expr reqd)

mark_0505:
TABLE_ADD:
	ADD	HL,DE		;
	JR	FETCH_3

; ___

mark_0508:
FETCH_2:
	LD	A,(HL)		;
	BIT	2,(IY+FLAGS-RAMBASE)	; K or L mode ?
	JR	NZ,TEST_CURS

	ADD	A,$C0		;
	CP	$E6		;
	JR	NC,TEST_CURS

mark_0515:
FETCH_3:
	LD	A,(HL)		;

mark_0516:
TEST_CURS:
	CP	$F0		;
	JP	PE,KEY_SORT

mark_051B:
ENTER:
	LD	E,A		;
	CALL	CURSOR

	LD	A,E		;
	CALL	ADD_CHAR

mark_0523:
BACK_NEXT:
	JP	LOWER		; back

; THE 'ADD CHARACTER' SUBROUTINE

mark_0526:
ADD_CHAR:
	CALL	ONE_SPACE
	LD	(DE),A		;
	RET			;

; THE 'CURSOR KEYS' ROUTINE

mark_052B:
K_L_KEY:
	LD	A,ZX_KL		;

mark_052D:
KEY_SORT:
	LD	E,A		;
	LD	HL,$0482	; base address of ED_KEYS (exp reqd)
	ADD	HL,DE		;
	ADD	HL,DE		;
	LD	C,(HL)		;
	INC	HL		;
	LD	B,(HL)		;
	PUSH	BC		;

mark_0537:
CURSOR:
	LD	HL,(E_LINE)	; sv
	BIT	5,(IY+FLAGX-RAMBASE)
	JR	NZ,L_MODE

mark_0540:
K_MODE:
	RES	2,(IY+FLAGS-RAMBASE)	; Signal use K mode

mark_0544:
TEST_CHAR:
	LD	A,(HL)		;
	CP	ZX_CURSOR	;
	RET	Z		; return

	INC	HL		;
	CALL	NUMBER
	JR	Z,TEST_CHAR

	CP	ZX_A		; $26
	JR	C,TEST_CHAR

	CP	$DE		; ZX_THEN ??
	JR	Z,K_MODE

mark_0556:
L_MODE:
	SET	2,(IY+FLAGS-RAMBASE)	; Signal use L mode
	JR	TEST_CHAR

; THE 'CLEAR_ONE' SUBROUTINE

mark_055C:
CLEAR_ONE:
	LD	BC,$0001	;
	JP	RECLAIM_2

; THE 'EDITING KEYS' TABLE

mark_0562:
ED_KEYS:
	DEFW	UP_KEY
	DEFW	DOWN_KEY
	DEFW	LEFT_KEY
	DEFW	RIGHT_KEY
	DEFW	FUNCTION
	DEFW	EDIT_KEY
	DEFW	N_L_KEY
	DEFW	RUBOUT
	DEFW	FUNCTION
	DEFW	FUNCTION

; THE 'CURSOR LEFT' ROUTINE

;
;

mark_LEFT_KEY:
LEFT_KEY:
	CALL	LEFT_EDGE
	LD	A,(HL)		;
	LD	(HL),ZX_CURSOR	;
	INC	HL		;
	JR	GET_CODE

; THE 'CURSOR RIGHT' ROUTINE

mark_RIGHT_KEY:
RIGHT_KEY:
	INC	HL		;
	LD	A,(HL)		;
	CP	ZX_NEWLINE		;
	JR	Z,ENDED_2

	LD	(HL),ZX_CURSOR	;
	DEC	HL		;

mark_0588:
GET_CODE:
	LD	(HL),A		;

mark_0589:
ENDED_1:
	JR	BACK_NEXT

; THE 'RUBOUT' ROUTINE

mark_058B:
RUBOUT:
	CALL	LEFT_EDGE
	CALL	CLEAR_ONE
	JR	ENDED_1

; THE 'ED_EDGE' SUBROUTINE

;
;

mark_0593:
LEFT_EDGE:
	DEC	HL		;
	LD	DE,(E_LINE)	; sv
	LD	A,(DE)		;
	CP	ZX_CURSOR	;
	RET	NZ		;

	POP	DE		;

mark_059D:
ENDED_2:
	JR	ENDED_1

; THE 'CURSOR UP' ROUTINE

;
;

mark_059F:
UP_KEY:
	LD	HL,(E_PPC)	; sv
	CALL	LINE_ADDR
	EX	DE,HL		;
	CALL	LINE_NUM
	LD	HL,E_PPC+1	; point to system variable E_PPC_hi
	JP	KEY_INPUT	; jump back

; THE 'FUNCTION KEY' ROUTINE

;
;

mark_FUNCTION:
FUNCTION:
	LD	A,E		;
	AND	$07		;
	LD	(MODE),A	; sv
	JR	ENDED_2		; back

; THE 'COLLECT LINE NUMBER' SUBROUTINE

mark_05B7:
ZERO_DE:
	EX	DE,HL		;
	LD	DE,DISPLAY_6 + 1	; $04C2 - a location addressing two zeros.

; ->

mark_05BB:
LINE_NUM:
	LD	A,(HL)		;
	AND	$C0		;
	JR	NZ,ZERO_DE

	LD	D,(HL)		;
	INC	HL		;
	LD	E,(HL)		;
	RET			;

; THE 'EDIT KEY' ROUTINE

mark_EDIT_KEY:
EDIT_KEY:
	CALL	LINE_ENDS	; clears lower display.

	LD	HL,EDIT_INP	; Address: EDIT_INP
	PUSH	HL		; ** is pushed as an error looping address.

	BIT	5,(IY+FLAGX-RAMBASE)	; test FLAGX
	RET	NZ		; indirect jump if in input mode
				; to EDIT_INP (begin again).

;

	LD	HL,(E_LINE)	; fetch E_LINE
	LD	(DF_CC),HL	; and use to update the screen cursor DF_CC

; so now RST $10 will print the line numbers to the edit line instead of screen.
; first make sure that no newline/out of screen can occur while sprinting the
; line numbers to the edit line.

				; prepare line 0, column 0.

	LD	HL,256*CHARS_VERTICAL + CHARS_HORIZONTAL + 1
;
	LD	(S_POSN),HL	; update S_POSN with these dummy values.

	LD	HL,(E_PPC)	; fetch current line from E_PPC may be a 
				; non-existent line e.g. last line deleted.
	CALL	LINE_ADDR	; gets address or that of
				; the following line.
	CALL	LINE_NUM	; gets line number if any in DE
				; leaving HL pointing at second low byte.

	LD	A,D		; test the line number for zero.
	OR	E		;
	RET	Z		; return if no line number - no program to edit.

	DEC	HL		; point to high byte.
	CALL	OUT_NO		; writes number to edit line.

	INC	HL		; point to length bytes.
	LD	C,(HL)		; low byte to C.
	INC	HL		;
	LD	B,(HL)		; high byte to B.

	INC	HL		; point to first character in line.
	LD	DE,(DF_CC)	; fetch display file cursor DF_CC

	LD	A,ZX_CURSOR	; prepare the cursor character.
	LD	(DE),A		; and insert in edit line.
	INC	DE		; increment intended destination.

	PUSH	HL		; * save start of BASIC.

	LD	HL,29		; set an overhead of 29 bytes.
	ADD	HL,DE		; add in the address of cursor.
	ADD	HL,BC		; add the length of the line.
	SBC	HL,SP		; subtract the stack pointer.

	POP	HL		; * restore pointer to start of BASIC.

	RET	NC		; return if not enough room to EDIT_INP EDIT_INP.
				; the edit key appears not to work.

	LDIR			; else copy bytes from program to edit line.
				; Note. hidden floating point forms are also
				; copied to edit line.

	EX	DE,HL		; transfer free location pointer to HL

	POP	DE		; ** remove address EDIT_INP from stack.

	CALL	SET_STK_B	; sets STKEND from HL.

	JR	ENDED_2		; back to ENDED_2 and after 3 more jumps
				; to LOWER, LOWER.
				; Note. The LOWER routine removes the hidden 
				; floating-point numbers from the edit line.

; THE 'NEWLINE KEY' ROUTINE

mark_060C:
N_L_KEY:
	CALL	LINE_ENDS

	LD	HL,LOWER	; prepare address: LOWER

	BIT	5,(IY+FLAGX-RAMBASE)
	JR	NZ,NOW_SCAN

	LD	HL,(E_LINE)	; sv
	LD	A,(HL)		;
	CP	$FF		;
	JR	Z,STK_UPPER

	CALL	CLEAR_PRB
	CALL	CLS

mark_0626:
STK_UPPER:
	LD	HL,UPPER	; Address: UPPER

mark_0629:
NOW_SCAN:
	PUSH	HL		; push routine address (LOWER or UPPER).
	CALL	LINE_SCAN
	POP	HL		;
	CALL	CURSOR
	CALL	CLEAR_ONE
	CALL	E_LINE_NUM
	JR	NZ,N_L_INP

	LD	A,B		;
	OR	C		;
	JP	NZ,N_L_LINE

	DEC	BC		;
	DEC	BC		;
	LD	(PPC),BC	; sv
	LD	(IY+DF_SZ-RAMBASE),2
	LD	DE,(D_FILE)	; sv

	JR	TEST_NULL	; forward

; ___

mark_064E:
N_L_INP:
	CP	ZX_NEWLINE	;
	JR	Z,N_L_NULL

	LD	BC,(T_ADDR)	; 
	CALL	LOC_ADDR
	LD	DE,(NXTLIN)	; 
	LD	(IY+DF_SZ-RAMBASE),2

mark_0661:
TEST_NULL:
	RST	_GET_CHAR
	CP	ZX_NEWLINE	;

mark_0664:
N_L_NULL:
	JP	Z,N_L_ONLY

	LD	(IY+FLAGS-RAMBASE),$80
	EX	DE,HL		;

mark_066C:
NEXT_LINE:
	LD	(NXTLIN),HL	; 
	EX	DE,HL		;
	CALL	TEMP_PTR2
	CALL	LINE_RUN
	RES	1,(IY+FLAGS-RAMBASE)	; Signal printer not in use
	LD	A,$C0		;
;;	LD	(IY+X_PTR_lo-RAMBASE),A		;; ERROR IN htm SOURCE! IY+$19 is X_PTR_hi
	LD	(IY+X_PTR_hi-RAMBASE),A
	CALL	X_TEMP
	RES	5,(IY+FLAGX-RAMBASE)
	BIT	7,(IY+ERR_NR-RAMBASE)
	JR	Z,STOP_LINE

	LD	HL,(NXTLIN)	;
	AND	(HL)		;
	JR	NZ,STOP_LINE

	LD	D,(HL)		;
	INC	HL		;
	LD	E,(HL)		;
	LD	(PPC),DE	;
	INC	HL		;
	LD	E,(HL)		;
	INC	HL		;
	LD	D,(HL)		;
	INC	HL		;
	EX	DE,HL		;
	ADD	HL,DE		;
	CALL	BREAK_1
	JR	C,NEXT_LINE

	LD	HL,ERR_NR
	BIT	7,(HL)
	JR	Z,STOP_LINE

	LD	(HL),$0C

mark_06AE:
STOP_LINE:
	BIT	7,(IY+PR_CC-RAMBASE)
	CALL	Z,COPY_BUFF
;
#if 0
	LD	BC,$0121	;
#else
	LD	BC,256*1 + CHARS_HORIZONTAL + 1
#endif
;
;
	CALL	LOC_ADDR
	LD	A,(ERR_NR)
	LD	BC,(PPC)
	INC	A
	JR	Z,REPORT

	CP	$09
	JR	NZ,CONTINUE

	INC	BC

mark_06CA:
CONTINUE:
	LD	(OLDPPC),BC	;
	JR	NZ,REPORT

	DEC	BC		;

mark_06D1:
REPORT:
	CALL	OUT_CODE
	LD	A,ZX_SLASH

	RST	_PRINT_A
	CALL	OUT_NUM
	CALL	CURSOR_IN
	JP	DISPLAY_6

; ___

mark_06E0:
N_L_LINE:
	LD	(E_PPC),BC	;
	LD	HL,(CH_ADD)	;
	EX	DE,HL		;
	LD	HL,N_L_ONLY
	PUSH	HL		;
	LD	HL,(STKBOT)	;
	SBC	HL,DE		;
	PUSH	HL		;
	PUSH	BC		;
	CALL	SET_FAST
	CALL	CLS
	POP	HL		;
	CALL	LINE_ADDR
	JR	NZ,COPY_OVER

	CALL	NEXT_ONE
	CALL	RECLAIM_2

mark_0705:
COPY_OVER:
	POP	BC		;
	LD	A,C		;
	DEC	A		;
	OR	B		;
	RET	Z		;

	PUSH	BC		;
	INC	BC		;
	INC	BC		;
	INC	BC		;
	INC	BC		;
	DEC	HL		;
	CALL	MAKE_ROOM
	CALL	SLOW_FAST
	POP	BC		;
	PUSH	BC		;
	INC	DE		;
	LD	HL,(STKBOT)	;
	DEC	HL		;
	LDDR			; copy bytes
	LD	HL,(E_PPC)	;
	EX	DE,HL		;
	POP	BC		;
	LD	(HL),B		;
	DEC	HL		;
	LD	(HL),C		;
	DEC	HL		;
	LD	(HL),E		;
	DEC	HL		;
	LD	(HL),D		;

	RET			; return.

; THE 'LIST' AND 'LLIST' COMMAND ROUTINES

mark_072C:
LLIST:
	SET	1,(IY+FLAGS-RAMBASE)	; signal printer in use

mark_0730:
LIST:
	CALL	FIND_INT

	LD	A,B		; fetch high byte of user-supplied line number.
	AND	$3F		; and crudely limit to range 1-16383.

	LD	H,A		;
	LD	L,C		;
	LD	(E_PPC),HL	;
	CALL	LINE_ADDR

mark_073E:
LIST_PROG:
	LD	E,$00		;

mark_0740:
UNTIL_END:
	CALL	OUT_LINE	; lists one line of BASIC
				; making an early return when the screen is
				; full or the end of program is reached.
	JR	UNTIL_END	; loop back to UNTIL_END

; THE 'PRINT A BASIC LINE' SUBROUTINE

mark_0745:
OUT_LINE:
	LD	BC,(E_PPC)	; sv
	CALL	CP_LINES
	LD	D,$92		;
	JR	Z,TEST_END

	LD	DE,$0000	;
	RL	E		;

mark_0755:
TEST_END:
	LD	(IY+BERG-RAMBASE),E
	LD	A,(HL)		;
	CP	$40		;
	POP	BC		;
	RET	NC		;

	PUSH	BC		;
	CALL	OUT_NO
	INC	HL		;
	LD	A,D		;

	RST	_PRINT_A
	INC	HL		;
	INC	HL		;

mark_0766:
COPY_LINE:
	LD	(CH_ADD),HL	;
	SET	0,(IY+FLAGS-RAMBASE)	; Suppress leading space

mark_076D:
MORE_LINE:
	LD	BC,(X_PTR)	;
	LD	HL,(CH_ADD)	;
	AND	A		;
	SBC	HL,BC		;
	JR	NZ,TEST_NUM

	LD	A,ZX_INV_S	; $B8	; 

	RST	_PRINT_A

mark_077C:
TEST_NUM:
	LD	HL,(CH_ADD)	;
	LD	A,(HL)		;
	INC	HL		;
	CALL	NUMBER
	LD	(CH_ADD),HL	;
	JR	Z,MORE_LINE

	CP	ZX_CURSOR	;
	JR	Z,OUT_CURS

	CP	ZX_NEWLINE		;
	JR	Z,OUT_CH

	BIT	6,A		;
	JR	Z,NOT_TOKEN

	CALL	TOKENS
	JR	MORE_LINE
; ___

mark_079A:
NOT_TOKEN:
	RST	_PRINT_A
	JR	MORE_LINE
; ___

mark_079D:
OUT_CURS:
	LD	A,(MODE)	; Fetch value of system variable MODE
	LD	B,$AB		; Prepare an inverse [F] for function cursor.

	AND	A		; Test for zero -
	JR	NZ,FLAGS_2	; forward if not to FLAGS_2

	LD	A,(FLAGS)	; Fetch system variable FLAGS.
	LD	B,ZX_INV_K	; Prepare an inverse [K] for keyword cursor.

mark_07AA:
FLAGS_2:
	RRA			; 00000?00 -> 000000?0
	RRA			; 000000?0 -> 0000000?
	AND	$01		; 0000000?	0000000x

	ADD	A,B		; Possibly [F] -> [G]	or	[K] -> [L]

	CALL	PRINT_SP
	JR	MORE_LINE

; THE 'NUMBER' SUBROUTINE

mark_07B4:
NUMBER:
	CP	$7E		;
	RET	NZ		;

	INC	HL		;
	INC	HL		;
	INC	HL		;
	INC	HL		;
	INC	HL		;
	RET			;

; THE 'KEYBOARD DECODE' SUBROUTINE

mark_07BD:
DECODE:
	LD	D,0		;
	SRA	B		; shift bit from B to Carry
	SBC	A,A		; A = 0 - Carry
	OR	$26		; %00100110
	LD	L,5		;
	SUB	L		;

mark_07C7:
KEY_LINE:
	ADD	A,L		;
	SCF			; Set Carry Flag
	RR	C		;
	JR	C,KEY_LINE

	INC	C		;
	RET	NZ		;

	LD	C,B		;
	DEC	L		;
	LD	L,1		;
	JR	NZ,KEY_LINE

	LD	HL,$007D	; (expr reqd)
	LD	E,A		;
	ADD	HL,DE		;
	SCF			; Set Carry Flag
	RET			;

; THE 'PRINTING' SUBROUTINE

mark_07DC:
LEAD_SP:
	LD	A,E		;
	AND	A		;
	RET	M		;

	JR	PRINT_CH

; ___
; HL is typically -10000, -1000, -100, -10 
; and repeatedly subtracted from BC
; i.e. it print
;
;
mark_07E1:
OUT_DIGIT:
	XOR	A		; assume the digit is zero to begin with

mark_07E2:
DIGIT_INC:
	ADD	HL,BC		; HL += -ve number
	INC	A		;
	JR	C,DIGIT_INC	; loop

	SBC	HL,BC		; undo last iteration
	DEC	A		; undo last iteration
	JR	Z,LEAD_SP	; leading zeros shown as spaces

mark_07EB:
OUT_CODE:
	LD	E,ZX_0		; $1C
	ADD	A,E		;

mark_07EE:
OUT_CH:
	AND	A		;
	JR	Z,PRINT_SP

mark_07F1:
PRINT_CH:
	RES	0,(IY+FLAGS-RAMBASE)	; signal leading space permitted

mark_07F5:
PRINT_SP:
	EXX			;
	PUSH	HL		;
	BIT	1,(IY+FLAGS-RAMBASE)	; is printer in use ?
	JR	NZ,LPRINT_A

	CALL	ENTER_CH
	JR	PRINT_EXX

; ___

mark_0802:
LPRINT_A:
	CALL	LPRINT_CH

mark_0805:
PRINT_EXX:
	POP	HL		;
	EXX			;
	RET			;

; ___

mark_0808:
ENTER_CH:
	LD	D,A		;
	LD	BC,(S_POSN)	;
	LD	A,C		;
	CP	CHARS_HORIZONTAL+1	;
	JR	Z,TEST_LOW

mark_0812:
TEST_N_L:
	LD	A,ZX_NEWLINE		;
	CP	D		;
	JR	Z,WRITE_N_L

	LD	HL,(DF_CC)	;
	CP	(HL)		;
	LD	A,D		;
	JR	NZ,WRITE_CH

	DEC	C		;
	JR	NZ,EXPAND_1

	INC	HL			;
	LD	(DF_CC),HL		;
	LD	C,CHARS_HORIZONTAL+1	; $21 = 33 normally
	DEC	B			;
	LD	(S_POSN),BC		;

mark_082C:
TEST_LOW:
	LD	A,B		;
	CP	(IY+DF_SZ-RAMBASE)
	JR	Z,REPORT_5

	AND	A		;
	JR	NZ,TEST_N_L

mark_0835:
REPORT_5:
	LD	L,4		; 'No more room on screen'
	JP	ERROR_3

; ___

mark_083A:
EXPAND_1:
	CALL	ONE_SPACE
	EX	DE,HL		;

mark_083E:
WRITE_CH:
	LD	(HL),A		;
	INC	HL		;
	LD	(DF_CC),HL	;
	DEC	(IY+S_POSN_x-RAMBASE)
	RET			;

; ___

mark_0847:
WRITE_N_L:
	LD	C,CHARS_HORIZONTAL+1	; $21 = 33
	DEC	B		;
	SET	0,(IY+FLAGS-RAMBASE)	; Suppress leading space
	JP	LOC_ADDR

; THE 'LPRINT_CH' SUBROUTINE

; This routine sends a character to the ZX-Printer placing the code for the
; character in the Printer Buffer.
; Note. PR_CC contains the low byte of the buffer address. The high order byte 
; is always constant. 

mark_0851:
LPRINT_CH:
	CP	ZX_NEWLINE	; compare to NEWLINE.
	JR	Z,COPY_BUFF	; forward if so

	LD	C,A		; take a copy of the character in C.
	LD	A,(PR_CC)	; fetch print location from PR_CC
	AND	$7F		; ignore bit 7 to form true position.
	CP	$5C		; compare to 33rd location

	LD	L,A		; form low-order byte.
	LD	H,$40		; the high-order byte is fixed.

	CALL	Z,COPY_BUFF	; to send full buffer to 
				; the printer if first 32 bytes full.
				; (this will reset HL to start.)

	LD	(HL),C		; place character at location.
	INC	L		; increment - will not cross a 256 boundary.
	LD	(IY+PR_CC-RAMBASE),L	; update system variable PR_CC
				; automatically resetting bit 7 to show that
				; the buffer is not empty.
	RET			; return.

; THE 'COPY' COMMAND ROUTINE

; The full character-mapped screen is copied to the ZX-Printer.
; All twenty-four text/graphic lines are printed.

mark_0869:
COPY:
;
; check - is this $16==22 or 24?
;
;;	LD	D,$16		; prepare to copy twenty four text lines.
	LD	D,22		; prepare to copy twenty four text lines.
	LD	HL,(D_FILE)	; set HL to start of display file from D_FILE.
	INC	HL		; 
	JR	COPY_D		; forward

; ___

; A single character-mapped printer buffer is copied to the ZX-Printer.

mark_0871:
COPY_BUFF:
	LD	D,1		; prepare to copy a single text line.
	LD	HL,PRBUFF	; set HL to start of printer buffer PRBUFF.

; both paths converge here.

mark_0876:
COPY_D:
	CALL	SET_FAST

	PUSH	BC		; *** preserve BC throughout.
				; a pending character may be present 
				; in C from LPRINT_CH

mark_087A:
COPY_LOOP:
	PUSH	HL		; save first character of line pointer. (*)
	XOR	A		; clear accumulator.
	LD	E,A		; set pixel line count, range 0-7, to zero.

; this inner loop deals with each horizontal pixel line.

mark_087D:
COPY_TIME:
	OUT	(IO_PORT_PRINTER),A	; bit 2 reset starts the printer motor
				; with an inactive stylus - bit 7 reset.
	POP	HL		; pick up first character of line pointer (*)
				; on inner loop.

mark_0880:
COPY_BRK:
	CALL	BREAK_1
	JR	C,COPY_CONT	; forward with no keypress to COPY_CONT

; else A will hold 11111111 0

	RRA			; 0111 1111
	OUT	(IO_PORT_PRINTER),A	; stop ZX printer motor, de-activate stylus.

mark_0888:
REPORT_D2:
	RST	_ERROR_1
	DEFB	$0C		; Error Report: BREAK - CONT repeats

; ___

mark_088A:
COPY_CONT:
	IN	A,(IO_PORT_PRINTER)	; read from printer port.
	ADD	A,A		; test bit 6 and 7
	JP	M,COPY_END	; jump forward with no printer to COPY_END

	JR	NC,COPY_BRK	; back if stylus not in position to COPY_BRK

	PUSH	HL		; save first character of line pointer (*)
	PUSH	DE		; ** preserve character line and pixel line.

	LD	A,D		; text line count to A?
	CP	2		; sets carry if last line.
	SBC	A,A		; now $FF if last line else zero.

; now cleverly prepare a printer control mask setting bit 2 (later moved to 1)
; of D to slow printer for the last two pixel lines ( E = 6 and 7)

	AND	E		; and with pixel line offset 0-7
	RLCA			; shift to left.
	AND	E		; and again.
	LD	D,A		; store control mask in D.

mark_089C:
COPY_NEXT:
	LD	C,(HL)		; load character from screen or buffer.
	LD	A,C		; save a copy in C for later inverse test.
	INC	HL		; update pointer for next time.
	CP	ZX_NEWLINE	; is character a NEWLINE ?
	JR	Z,COPY_N_L	; forward, if so, to COPY_N_L

	PUSH	HL		; * else preserve the character pointer.

	SLA	A		; (?) multiply by two
	ADD	A,A		; multiply by four
	ADD	A,A		; multiply by eight

	LD	H,$0F		; load H with half the address of character set.
	RL	H		; now $1E or $1F (with carry)
	ADD	A,E		; add byte offset 0-7
	LD	L,A		; now HL addresses character source byte

	RL	C		; test character, setting carry if inverse.
	SBC	A,A		; accumulator now $00 if normal, $FF if inverse.

	XOR	(HL)		; combine with bit pattern at end or ROM.
	LD	C,A		; transfer the byte to C.
	LD	B,8		; count eight bits to output.

mark_08B5:
COPY_BITS:
	LD	A,D		; fetch speed control mask from D.
	RLC	C		; rotate a bit from output byte to carry.
	RRA			; pick up in bit 7, speed bit to bit 1
	LD	H,A		; store aligned mask in H register.

mark_08BA:
COPY_WAIT:
	IN	A,(IO_PORT_PRINTER)	; read the printer port
	RRA				; test for alignment signal from encoder.
	JR	NC,COPY_WAIT		; loop if not present to COPY_WAIT

	LD	A,H			; control byte to A.
	OUT	(IO_PORT_PRINTER),A	; and output to printer port.
	DJNZ	COPY_BITS		; loop for all eight bits to COPY_BITS

	POP	HL			; * restore character pointer.
	JR	COPY_NEXT		; back for adjacent character line to COPY_NEXT

; ___

; A NEWLINE has been encountered either following a text line or as the 
; first character of the screen or printer line.

mark_08C7:
COPY_N_L:
	IN	A,(IO_PORT_PRINTER)	; read printer port.
	RRA			; wait for encoder signal.
	JR	NC,COPY_N_L	; loop back if not to COPY_N_L

	LD	A,D		; transfer speed mask to A.
	RRCA			; rotate speed bit to bit 1. 
				; bit 7, stylus control is reset.
	OUT	(IO_PORT_PRINTER),A	; set the printer speed.

	POP	DE		; ** restore character line and pixel line.
	INC	E		; increment pixel line 0-7.
	BIT	3,E		; test if value eight reached.
	JR	Z,COPY_TIME	; back if not

; eight pixel lines, a text line have been completed.

	POP	BC		; lose the now redundant first character 
				; pointer
	DEC	D		; decrease text line count.
	JR	NZ,COPY_LOOP	; back if not zero

	LD	A,$04			; stop the already slowed printer motor.
	OUT	(IO_PORT_PRINTER),A	; output to printer port.

mark_08DE:
COPY_END:
	CALL	SLOW_FAST
	POP	BC		; *** restore preserved BC.

; THE 'CLEAR PRINTER BUFFER' SUBROUTINE

; This subroutine sets 32 bytes of the printer buffer to zero (space) and
; the 33rd character is set to a NEWLINE.
; This occurs after the printer buffer is sent to the printer but in addition
; after the 24 lines of the screen are sent to the printer. 
; Note. This is a logic error as the last operation does not involve the 
; buffer at all. Logically one should be able to use 
; 10 LPRINT "HELLO ";
; 20 COPY
; 30 LPRINT ; "WORLD"
; and expect to see the entire greeting emerge from the printer.
; Surprisingly this logic error was never discovered and although one can argue
; if the above is a bug, the repetition of this error on the Spectrum was most
; definitely a bug.
; Since the printer buffer is fixed at the end of the system variables, and
; the print position is in the range $3C - $5C, then bit 7 of the system
; variable is set to show the buffer is empty and automatically reset when
; the variable is updated with any print position - neat.

mark_08E2:
CLEAR_PRB:
	LD	HL,PRBUFF_END	; address fixed end of PRBUFF
	LD	(HL),ZX_NEWLINE	; place a newline at last position.
	LD	B,32		; prepare to blank 32 preceding characters. 
;
; NB the printer is fixed at 32 characters, maybe it can be tweaked ???
;
mark_08E9:
PRB_BYTES:
	DEC	HL		; decrement address - could be DEC L.
	LD	(HL),0		; place a zero byte.
	DJNZ	PRB_BYTES	; loop for all thirty-two

	LD	A,L		; fetch character print position.
	SET	7,A		; signal the printer buffer is clear.
	LD	(PR_CC),A	; update one-byte system variable PR_CC
	RET			; return.

; THE 'PRINT AT' SUBROUTINE

;
;
;
mark_08F5:
PRINT_AT:

	LD	A,CHARS_VERTICAL-1	; originally 23
	SUB	B		;
	JR	C,WRONG_VAL

mark_08FA:
TEST_VAL:
	CP	(IY+DF_SZ-RAMBASE)
	JP	C,REPORT_5

	INC	A		;
	LD	B,A		;
	LD	A,CHARS_HORIZONTAL-1	; originally 31

	SUB	C		;

mark_0905:
WRONG_VAL:
	JP	C,REPORT_B

	ADD	A,2		;
	LD	C,A		;

mark_090B:
SET_FIELD:
	BIT	1,(IY+FLAGS-RAMBASE)	; Is printer in use?
	JR	Z,LOC_ADDR

	LD	A,$5D		;
	SUB	C		;
	LD	(PR_CC),A	;
	RET			;

; THE 'LOCATE ADDRESS' ROUTINE

;
; I'm guessing this locates the address of a character at X,Y 
; on the screen, with 0,0 being on the bottom left?
; S_POSN_x    equ $4039
; S_POSN_y    equ $403A
; so when BC is stored there, B is Y and C is X
;
mark_0918:
LOC_ADDR:
	LD	(S_POSN),BC	;
	LD	HL,(VARS)	;
	LD	D,C		;
	LD	A,CHARS_HORIZONTAL+2	; $22 == 34 originally.
	SUB	C		;
	LD	C,A		;
	LD	A,ZX_NEWLINE	;
	INC	B		;

mark_0927:
LOOK_BACK:
	DEC	HL		;
	CP	(HL)		;
	JR	NZ,LOOK_BACK

	DJNZ	LOOK_BACK

	INC	HL		;
	CPIR			;
	DEC	HL		;
	LD	(DF_CC),HL	;
	SCF			; Set Carry Flag
	RET	PO		;

	DEC	D		;
	RET	Z		;
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

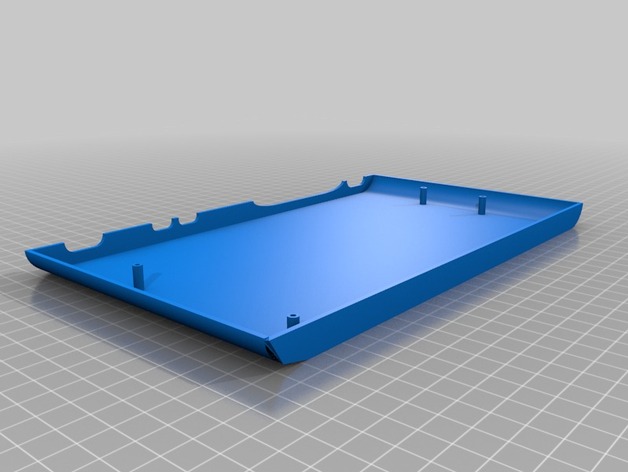
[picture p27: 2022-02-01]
case_zxspectrum/images/Spectrum_case3_preview_featured.jpg

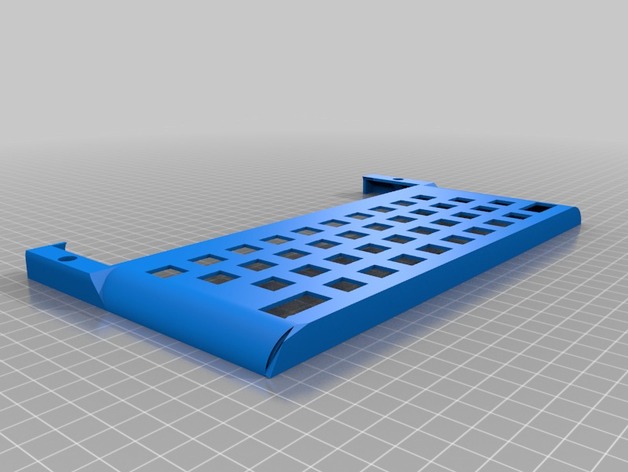
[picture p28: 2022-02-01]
case_zxspectrum/images/Spectrum_case2_preview_featured.jpg

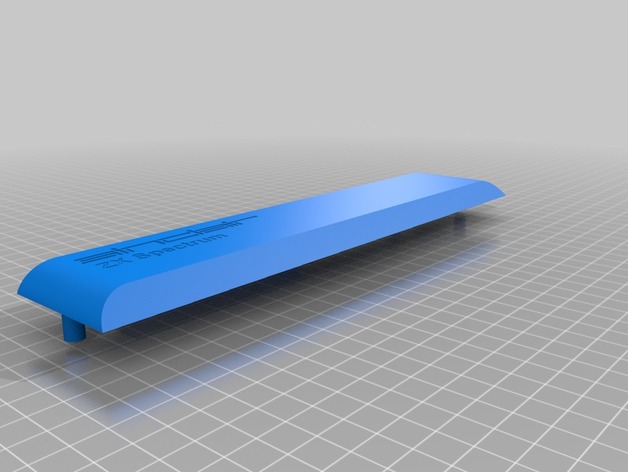
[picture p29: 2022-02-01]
case_zxspectrum/images/Spectrum_case1_preview_featured.jpg

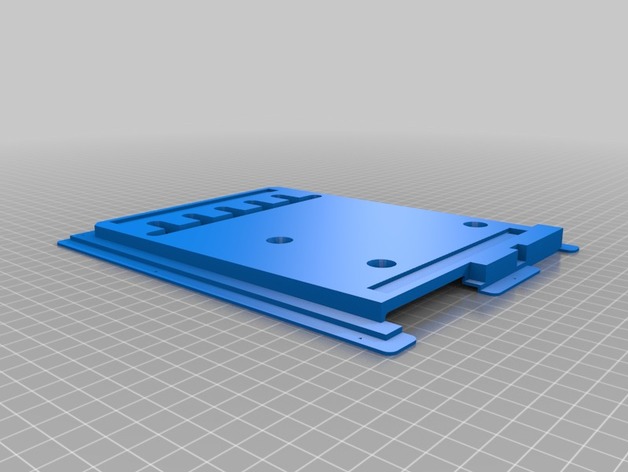
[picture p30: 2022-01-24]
case_zx80/case1/images/7cd02b0c3a2fe636d86667bb849b0b5a_preview_featured.jpg

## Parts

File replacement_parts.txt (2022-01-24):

ZX Spectrum 48k

All versions
ZTX213 can be replaced with BC251, BC307, BC512, BC557
ZTX313 can be replaced with BC172, BC183, BC238, BC383
ZTX650 can be replaced with BC537, BC737, BC487, BC489, BC538 (using BC487 in TR4 position may cause overheating)
BC184 can be replaced with BC384, BC413, BC550

For issue 2 boards and above
ZTX650 can be replaced with ZTX651 in TR4 position
ZTX213 can be replaced with ZTX750 in TR5 position
ZTX313 can be replaced with BC547, BC548 and BC549 in TR1/TR2 position (Usually improves picture quality significantly)
BA157 can be replaced by BA158 or 1N4937 fast recovery diodes

For issue 3 boards and above
ZTX450 can be replaced with ZTX650/651 in TR7 position
ZTX313 can be replaced with BC184 in TR8 - TR9 position

Issue 3B
TR1, TR2, TR3 and TR6 can be replaced with MPS2369

Issue 6A
TR8 and TR9 can be replaced with BC549B

Spectrum +3
TR1 in the +3 PSU is an H1061. Possible alternatives include the BD243C and TIP41C

Integrated Circuits

RAM
MM5920N (national Semiconductors) chips are equivalent to 4116 RAM chips
AM9016EDC (AMD) chips are the same as 4116 chips.
IMS2600P-12 (Inmos) chips work in any upper RAM position (IC15-22)
41256 chips work in place of 4164 upper RAM chips
V53C256P80L chips work in any upper RAM position (IC15-22)
MN41257-12 chips work in any upper RAM position (IC15-22)

Logic
74LSxx series chips can be replaced with 74HCTxx series chips

CPU
Various makes of Z80 processor are used on Spectrums. Zilog Z80 CPU NEC D780C

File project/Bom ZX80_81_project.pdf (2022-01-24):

Qt | Part | Value | Device | Package
18 | R1,R3..R12,R18,R22..R24,R27,R30,R34 | 1K | R-EU_0204/7 | 0204/7
2 | R2,R25 | 470 | R-EU_0204/7 | 0204/7
6 | R13..R17,R28 | 47K | R-EU_0204/7 | 0204/7
1 | R19 | 2K2 | R-EU_0204/7 | 0204/7
2 | R20,R32 | 330 | R-EU_0204/7 | 0204/7
1 | R21 | 220K | R-EU_0204/7 | 0204/7
3 | R26,R31,R39 | 10K | R-EU_0204/7 | 0204/7
1 | R29 | 180 | R-EU_0204/7 | 0204/7
1 | R35 | 1M | R-EU_0204/7 | 0204/7
1 | R36 | 2K7 | R-EU_0204/7 | 0204/7
1 | R38 | 100 | R-EU_0207/7 | 0207/7
1 | R40 | 820k | R-EU_0207/7 | 0207/7
3 | R41,R42,R43 | 680 | R-EU_0204/7 | R-EU_0204/7
12 | D1..D11,D12 | 1N4148DO35-7 | 1N4148DO35-7 | DO35-7
1 | D13 | 1N4007 | 1N4007 | DO41-10
1 | R33 | 1k | TRIMPOT POTUS-L | B25P
1 | R37 | 5K | TRIMPOT POTUS-L | B25P
2 | SOCKET | | | DIL28-6
1 | SOCKET | | | DIL20
5 | SOCKET | | | DIL16
1 | SOCKET | | | DIL08
18 | SOCKET | | | DIL14
1 | SOCKET | | | DIL40
1 | X1 | 6.5MHz | XTAL/S | QS
3 | X2..X4 | JACK | 3.5MM | HEMBRA
4 | C6,C21,C22,C24 | 100nF | C-EU025-024X044 | C025-024X044
1 | C8 | 22uF | CPOL-EUE2-4 | E2-4
1 | C15 | 220pF | CPOL-EUE2-4 | E2-4
1 | C10 | 1uF | CPOL-EUE2-4 | E2-4
1 | C23 | 100uF
1 | C18 | 10nF | C-EU025-024X044 | C025-024X044
1 | C7 | 100pF | C-EU025-024X044 | C025-024X044
3 | C9,C11,C14 | 47pF | C-EU025-024X044 | C025-024X044
11 | C1..C5,C12..C13,C16,C17,C19,C20 | 47nF | C-EU025-024X044 | C025-024X044
1 | IC22 | 7805T | 7805T | TO220H
1 | POWERLED | RED | LED3MM | LED3MM
1 | ZX81LED | YELLOW | LED3MM | LED3MM
2 | Q1,Q2 | BC548 | BC548 | TO92-EBC
6 | JP1..JP6 | JP2E | JP2 | jumper
1 | JP1..JP6 | JP2E | JP2 | Barra de Pinos
4 | IC11,IC12,IC23,U4 | 74LS00N | 74LS00N | DIL14
1 | IC13 | 74LS04N | 74LS04N | DIL14
2 | IC14,IC15 | 74LS05N | 74LS05N | DIL14
1 | IC16 | 74LS10N | 74LS10N | DIL14
2 | IC17,U3 | 74LS32N | 74LS32N | DIL14
2 | IC18,IC19 | 74LS74N | 74LS74N | DIL14
1 | IC20 | 74LS86N | 74LS86N | DIL14
1 | IC21 | 74LS93N | 74LS93N | DIL14

## Bill of Materials

ZX80/81

## Augusto Baffa

Qt | Part | Value | Device | Package 1 | U1 | 74LS393N | 74LS393N | DIL14 1 | U2 | 74AC11N | 74LS11N | DIL14 1 | U5 | 74LS08N | 74LS08N | DIL14 1 | U6 | 74LS02N | 74LS02N | DIL14 1 | IC24 | LM1881 | DIL8 | DIL08 1 | IC1 | Z80A | Z80CPU | DIL40 1 | IC10 | 74LS365N | 74LS365N | DIL16 1 | IC2 | 27C512 | 27C128P | DIL28-6 1 | IC3 | CY62256LL-PC | CY62256LL-PC | DIL28-6 1 | IC5 | 74S373N | 74S373N | DIL20 3 | IC6..IC8 | 74157N | 74157N | DIL16 1 | IC9 | 74165N | 74165N | DIL16 2 | S1,S2 | 255SB | 255SB | Switch / Jumper 1 | X5 | RCA | VIDEO | HEMBRA 1 | JP4 | PUSH BUTTON | RESET | 6X6X7MM

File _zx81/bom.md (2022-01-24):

# ZX81 - List of Components

| No. | Value | Issue 1 | Issue 3 | Alternative | Comments
| --- | --- | --- | --- | --- | ---
| Resistors |  |  |  |  | 
| R1 | 10K | Yes | Yes |  | 
| R2 | 680 | Yes | Yes |  | 
| R3 | --- | --- | --- | --- | Not used. 330R is connected to C6 in piggy-back
| R4 | 18K | Yes | Yes |  | 
| R5 | 330 | Yes | Yes |  | 
| R6 | 2K2 | Yes | Yes |  | 
| R7 | 470 | Yes | Yes |  | 
| R8 | 470 | Yes | Yes |  | 
| R9 | 470 | Yes | Yes |  | 
| R10 | 470 | Yes | Yes |  | 
| R11 | 470 | Yes | Yes |  | 
| R12 | 470 | Yes | Yes |  | 
| R13 | 470 | Yes | Yes |  | 
| R14 | 470 | Yes | Yes |  | 
| R15 | 220K | Yes | Yes |  | 
| R16 | 1K | Yes | Yes |  | 
| R17 | 1K | Yes | Yes |  | 
| R18 | 1K | Yes | Yes |  | 
| R19 | 1K | Yes | Yes |  | 
| R20 | 1K | Yes | Yes |  | 
| R21 | 1K | Yes | Yes |  | 
| R22 | 1K | Yes | Yes |  | 
| R23 | 1K | Yes | Yes |  | 
| R24 | 1K | Yes | Yes |  | 
| R25 | 1K | Yes | Yes |  | 
| R26 | 1K | Yes | Yes |  | 
| R27 | 1K | Yes | Yes |  | 
| R28 | 680 | Yes | Yes |  | 
| R29 | 1M | Yes | Yes |  | 
| R30 | --- | --- | --- | --- | Not used
| R31 | --- | --- | --- | --- | Not used
| R32 | --- | --- | --- | --- | Not used
| R33 | 4K7 | Yes | Yes |  | 
| R34 | 220 | Yes | Yes |  | 
| R35 | 1K | No | Yes |  | 
| R36 | 1K | No | Yes |  | 
| R37 | 1K | No | Yes |  | 
| R38 | 1K | No | Yes |  | 
| R39 | 1K | No | Yes |  | 
| R40 | 1K | No | Yes |  | 
| R41 | 1K | No | Yes |  | 
| R42 | 1K | No | Yes |  | 
| R43 | 1K | No | Yes |  | 
| R44 | 1K | No | Yes |  | 
| R45 | 1K | No | Yes |  | 
| R46 | 1K | No | Yes |  | 
| R47 | 1K | No | Yes |  | 
|  |  |  |  |  | 
| Resistor Network |  |  |  |  | 
| RP1 | 8 x 10K | Yes | No |  | 
| RP2 | --- | --- | --- | --- | Not used
| RP3 | 5 x 10K | Yes | No |  | 
|  |  |  |  |  | 
| Capacitors |  |  |  |  | 
| C1 | 47pF | Yes | Yes | | Ceramic | 
| C2 | 47nF | Yes | Yes | | Ceramic | 
| C3 | 22uF | Yes | Yes | | Electrolytic  | 
| C4 | 47nF | Yes | Yes | | Ceramic | 
| C5 | 1uF | Yes | Yes | | Electrolytic  | 
| C6 | 100pF | Yes | Yes | | Ceramic | 
| C7 | 47pF | Yes | Yes | | Ceramic | 
| C8 | 47nF | Yes | Yes | | Ceramic | 
| C9 | 47nF | Yes | Yes | | Ceramic | 
| C10 | 10nF | Yes | Yes | | Ceramic | 
| C11 | 47nF | Yes | Yes | | Ceramic | 
| C12 | 47pF | Yes | Yes | | Ceramic | 
| C13 | --- | No | --- | --- | Not used
| C14 | --- | No | --- | --- | Not used
|  |  |  |  |  | 
| Semiconductors |  |  |  |  | 
| IC1 | ULA | Yes | Yes |  | 40 pins
| IC2 | ROM 2364 | Yes | Yes |  | 24 pins
| IC3 | CPU D780C-1 | Yes | Yes | MK3880 | 40 pins
| IC4a | /RAM |  |  |  | 
| IC4b | PD2114LC | Yes | Yes |  | 18 pins
| IC4 | MK4118 | Yes | Yes | MK4801 or 4816 | 24 pins
| TR1 | ZTX313 | Yes | Yes |  | 
| TR2 | ZTX313 | Yes | Yes |  | 
| D1 | 1N4448 | Yes | Yes | 1N4148 or 1S44 | 
| D2 | 1N4448 | Yes | Yes | 1N4148 or 1S44 | 
| D3 | 1N4448 | Yes | Yes | 1N4148 or 1S44 | 
| D4 | 1N4448 | Yes | Yes | 1N4148 or 1S44 | 
| D5 | 1N4448 | Yes | Yes | 1N4148 or 1S44 | 
| D6 | 1N4448 | Yes | Yes | 1N4148 or 1S44 | 
| D7 | 1N4448 | Yes | Yes | 1N4148 or 1S44 | 
| D8 | 1N4448 | Yes | Yes | 1N4148 or 1S44 | 
| D9 | --- | --- | --- | --- | Not used
|  |  |  |  |  | 
| Miscellaneous |  |  |  |  | 
| REG | 7805 | Yes | Yes |  | 
| X1 | 6,5MHZ | Yes | Yes |  | 
| MOD | UN1223 | Yes | Yes |  | 
| KB1 | conector | Yes | Yes |  | 5 pins
| KB2 | conector | Yes | Yes |  | 8 pins

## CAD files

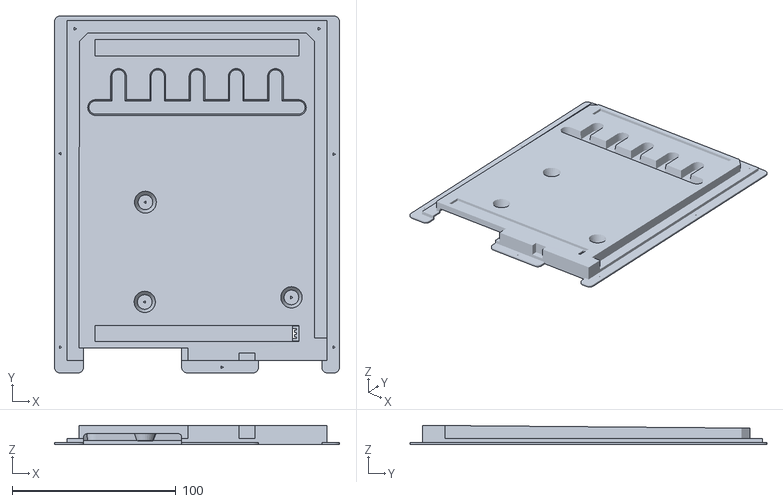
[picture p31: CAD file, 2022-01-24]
case_zx80/case1/files/abajo_entero_switch_no_sup.stl
174.3 x 218.3 x 11.8

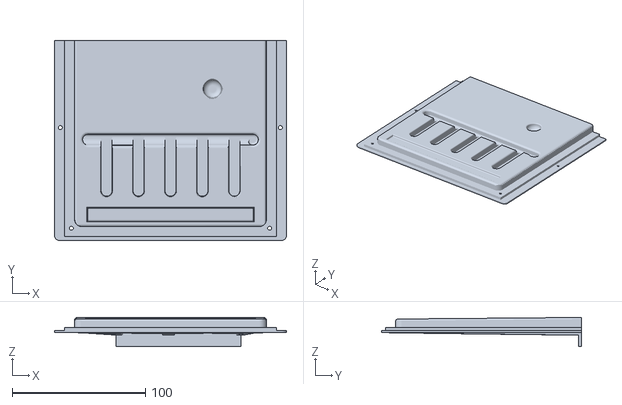
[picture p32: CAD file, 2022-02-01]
case_zx80/case2/zx-80_bottom_part1.stl
174.3 x 150.1 x 21.9

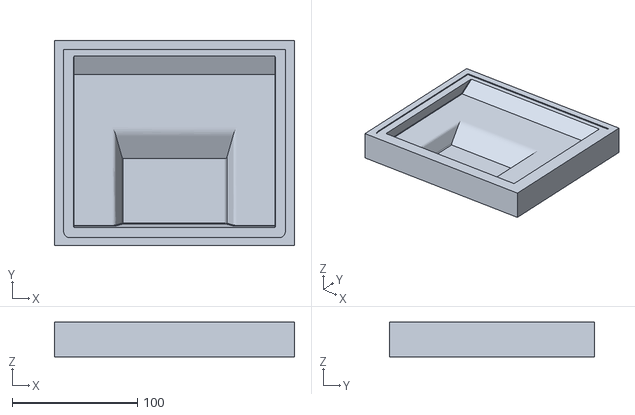
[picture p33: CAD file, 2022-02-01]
case_zx80/vacuum_mold1/files/ZX80_Top_Mold.stl
191.5 x 163.4 x 27.8

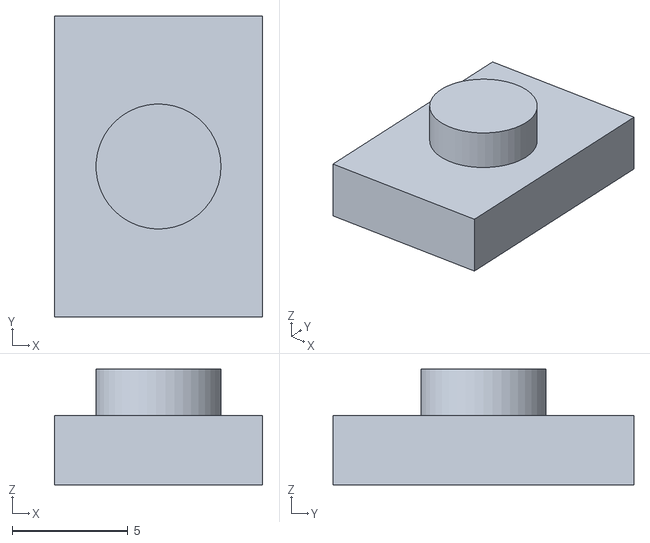
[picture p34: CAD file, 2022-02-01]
case_zx81/case1/files/zx81_foot.stl
9.00 x 13.0 x 5.00

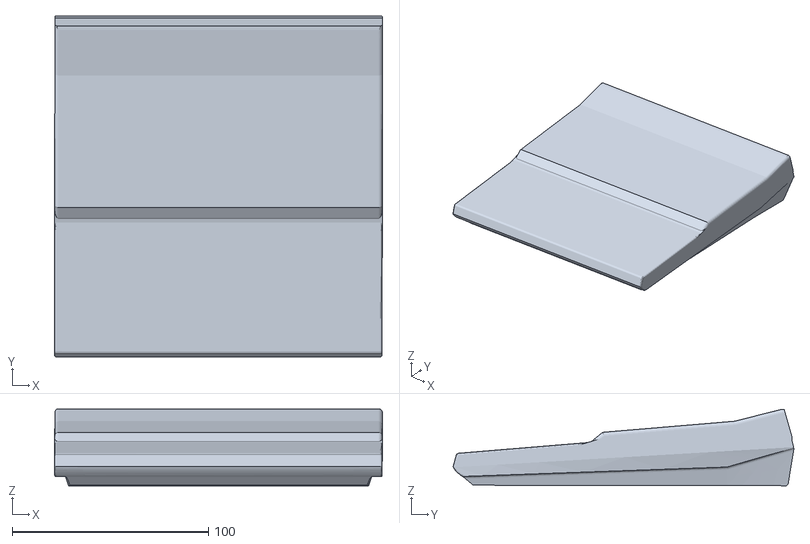
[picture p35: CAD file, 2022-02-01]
case_zx81/case3/files/zx81Block.stl
167.2 x 173.7 x 39.0

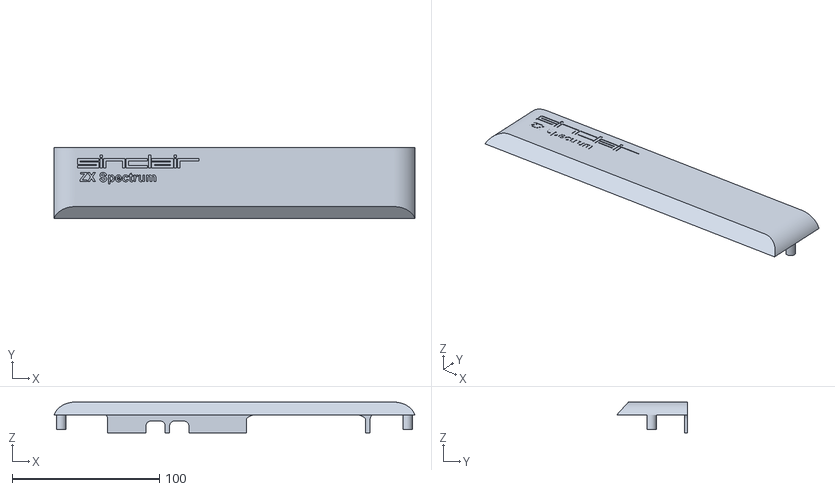
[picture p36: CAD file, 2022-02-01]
case_zxspectrum/files/Spectrum_case1.stl
244.9 x 48.1 x 20.9

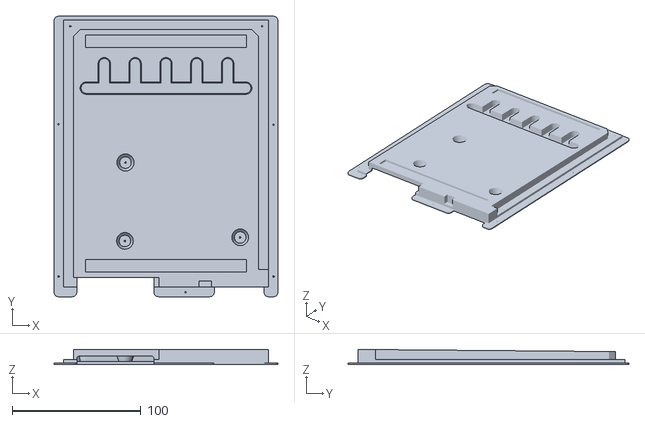
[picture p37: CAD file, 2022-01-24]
case_zx80/case1/files/abajo_entero_no_switch_no_sup.stl
174.3 x 218.3 x 11.8

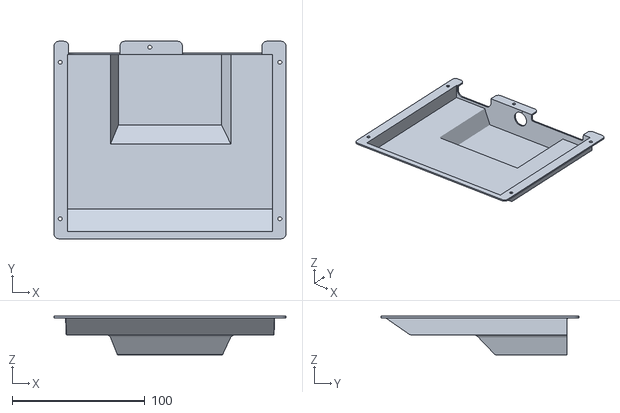
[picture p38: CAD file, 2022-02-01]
case_zx80/case2/zx-80_top.stl
174.6 x 148.7 x 29.0

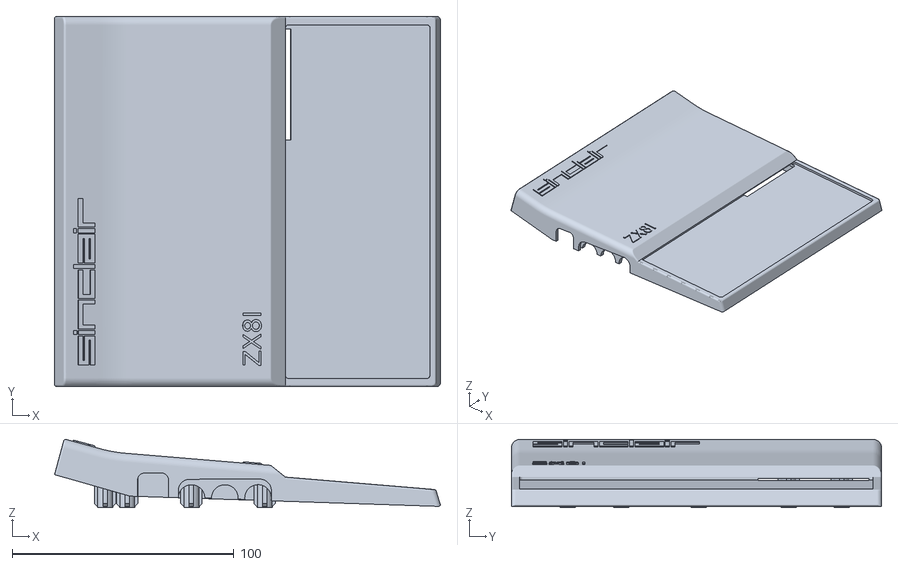
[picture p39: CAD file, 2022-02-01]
case_zx81/case1/files/zx81_case_top.stl
174.0 x 167.0 x 30.7

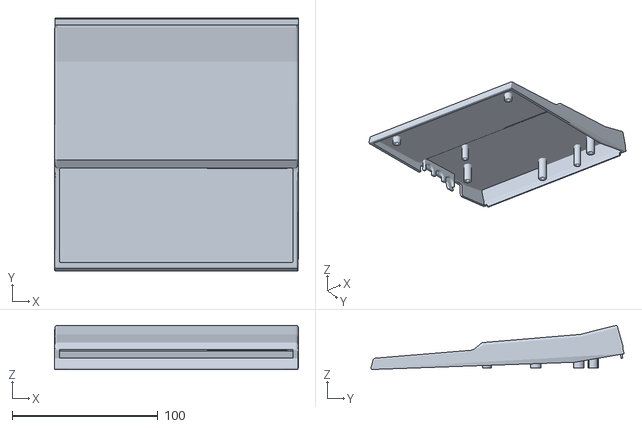
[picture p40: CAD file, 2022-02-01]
case_zx81/case3/files/zx81Top-EuroPort.stl
167.2 x 173.6 x 30.2

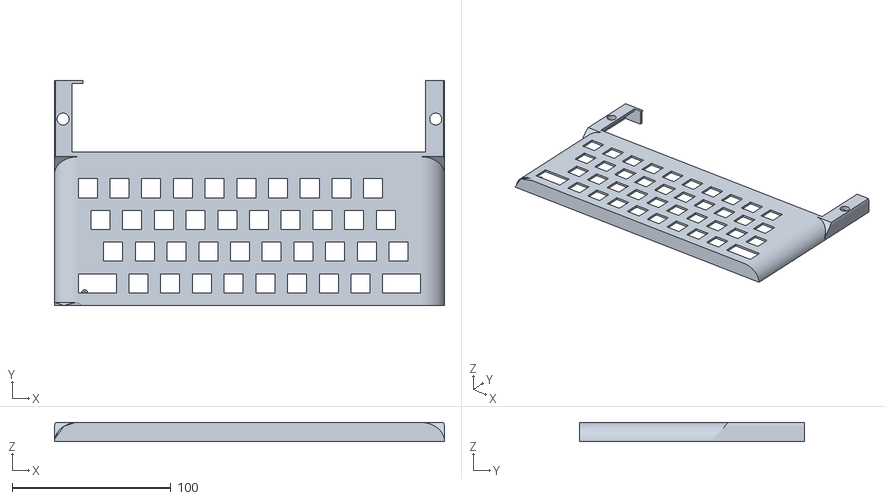
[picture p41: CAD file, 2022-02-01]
case_zxspectrum/files/Spectrum_case2.stl
246.0 x 142.0 x 12.1

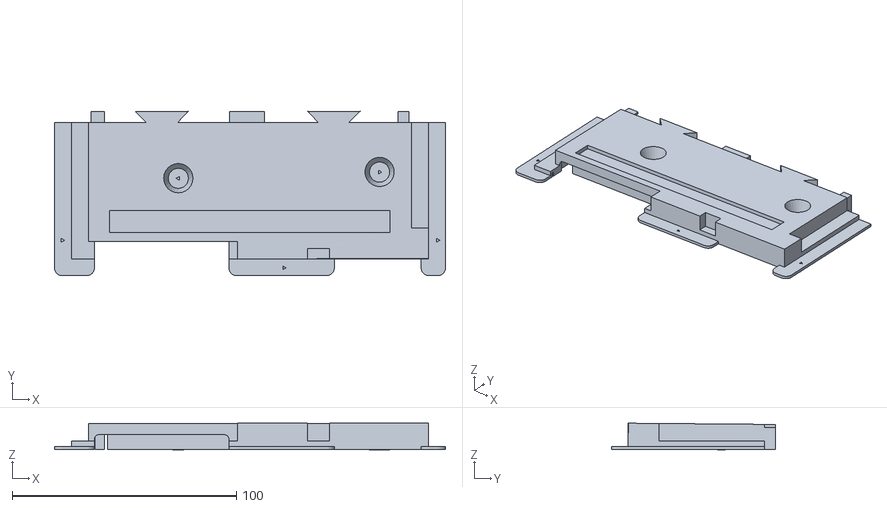
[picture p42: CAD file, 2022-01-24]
case_zx80/case1/files/abajo_b_no_switch_soportes.stl
174.3 x 73.3 x 11.9

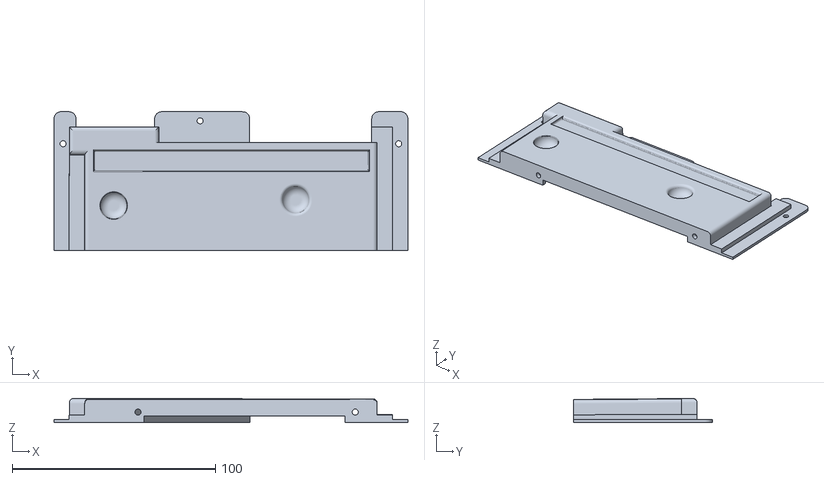
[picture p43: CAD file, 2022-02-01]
case_zx80/case2/zx-80_bottom_part2.stl
174.4 x 68.3 x 11.9

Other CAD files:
case_zx81/case2/files/zx81-case-top-horizontal-with-standoff-ribs.stl
case_zx80/case1/files/abajo_b_no_switch_no_sup.stl
case_zx80/case1/files/abajo_b_switch_no_sup.stl
case_zx80/case1/files/abajo_b_switch_soportes.stl
case_zx80/case1/files/abajo_entero_no_switch_soportes.stl
case_zx80/case1/files/abajo_entero_switch_soportes.stl
case_zx80/case1/files/carcasa_v14.1a.stl
case_zx80/case1/files/carcasa_v14.skp
case_zx80/case1/files/carcasa_v20.3t.stl
case_zx80/case1/files/carcasa_v20.3t_no_av_hole.stl
case_zx80/vacuum_mold1/files/ZX80_Bottom_Mold.skp
case_zx80/vacuum_mold1/files/ZX80_Top_Mold.skp
case_zx80/vacuum_mold2/zx80_bottom_mold.skp
case_zx80/vacuum_mold2/zx80_top_mold.skp
case_zx81/case1/files/zx81_case_bottom.stl
case_zx81/case1/files/zx81_case_top-vertical.stl
case_zx81/case2/files/zx81-case-bottom.stl
case_zx81/case2/files/zx81-case-top-vertical-with-standoff-ribs.stl
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

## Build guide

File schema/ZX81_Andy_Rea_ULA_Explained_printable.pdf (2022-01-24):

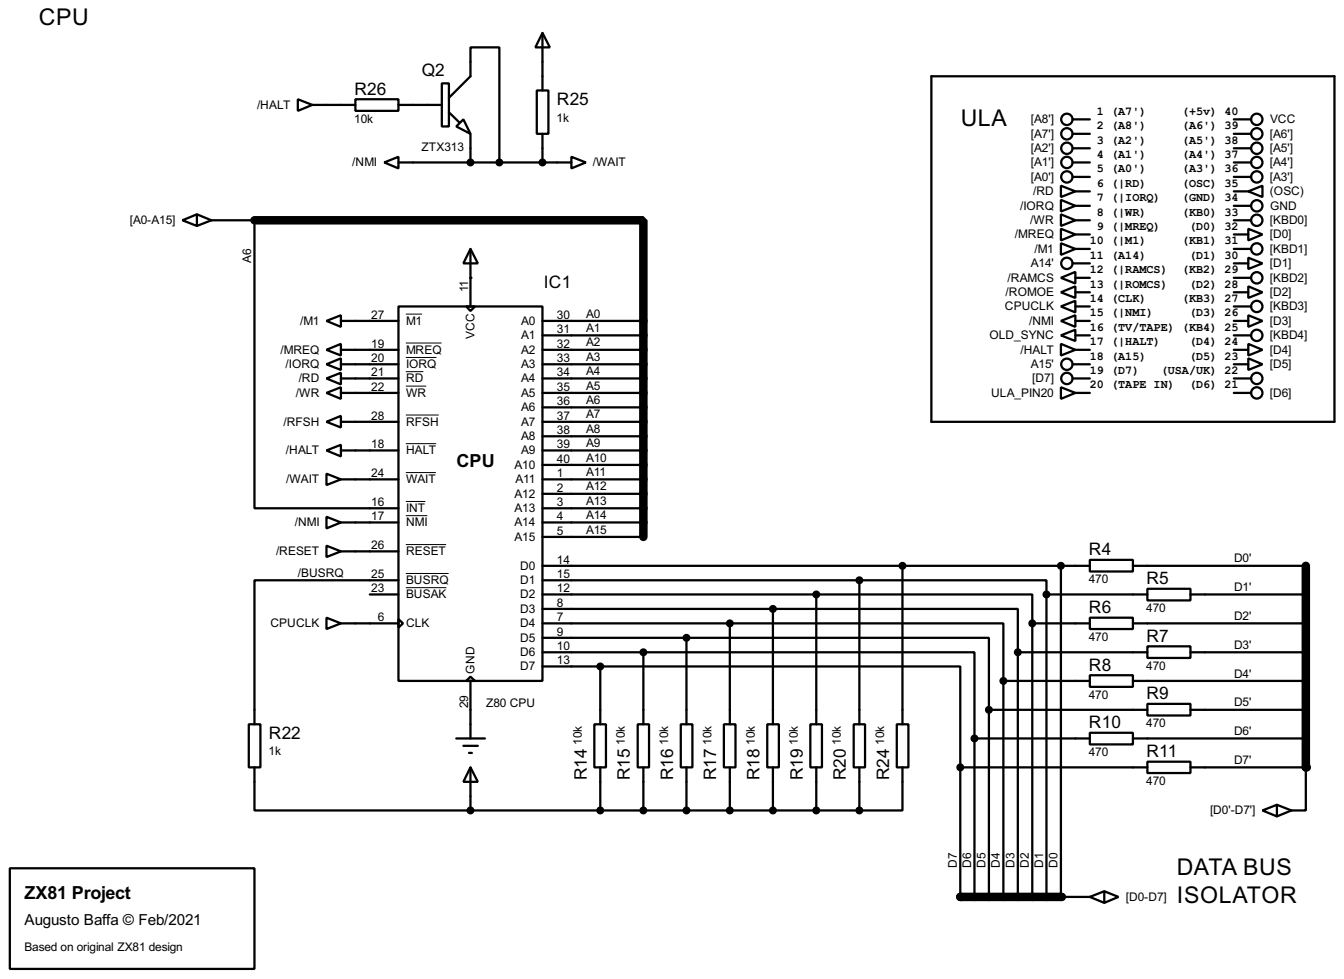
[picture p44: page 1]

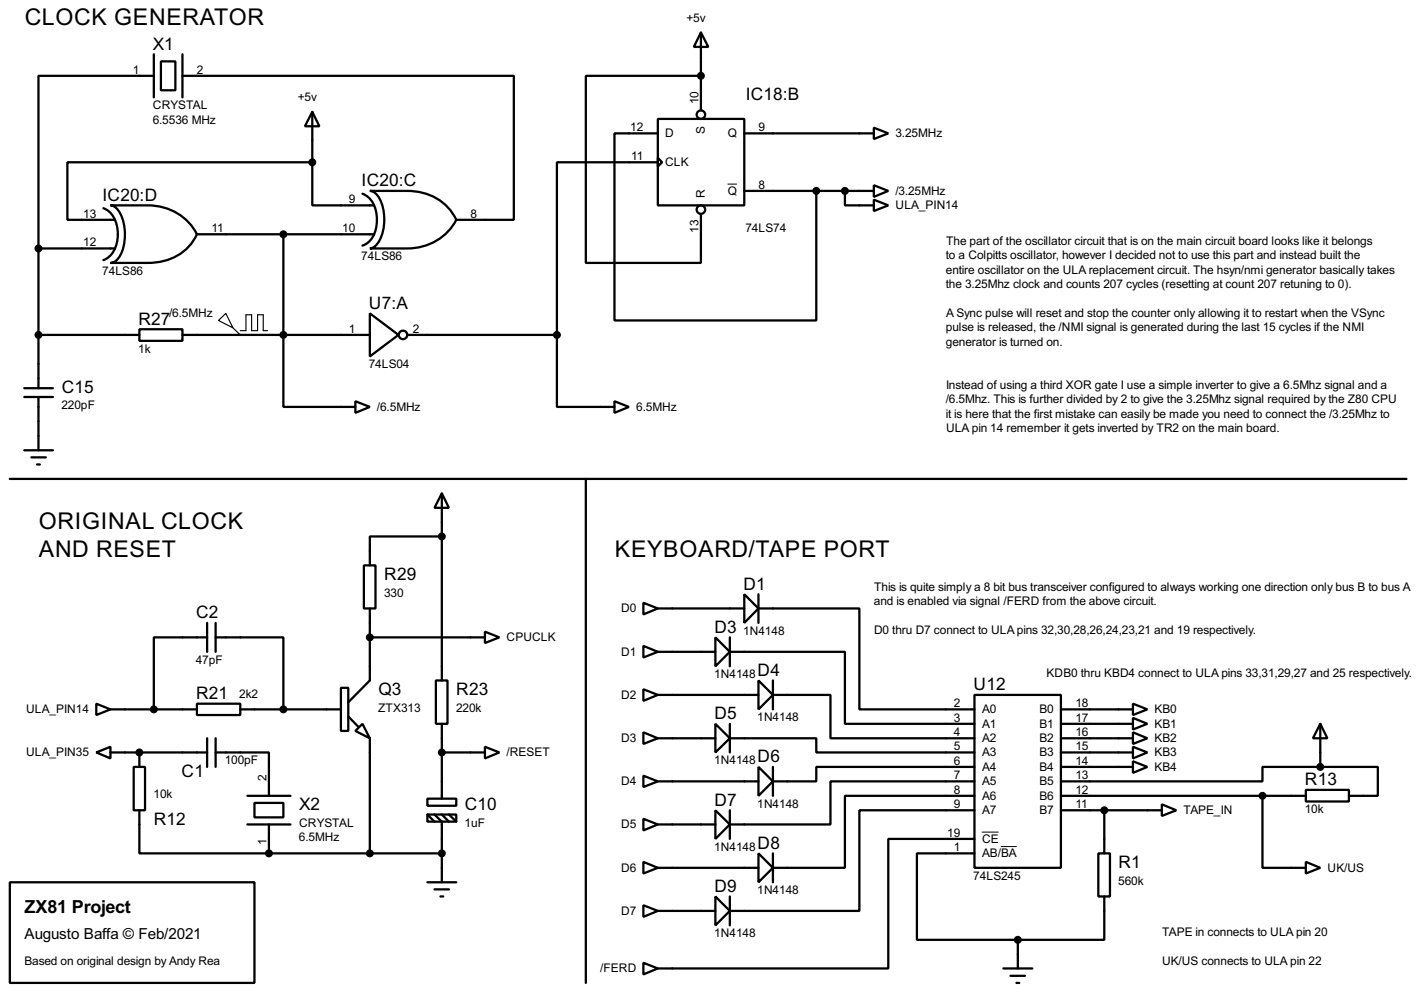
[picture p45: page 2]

The part of the oscillator circuit that is on the main circuit board looks like it belongs
to a Colpitts oscillator, however I decided not to use this part and instead built the
entire oscillator on the ULA replacement circuit. The hsyn/nmi generator basically takes
the 3.25Mhz clock and counts 207 cycles (resetting at count 207 retuning to 0). A Sync pulse will reset and stop the counter only allowing it to restart when the VSync pulse is released, the /NMI signal is generated during the last 15 cycles if the NMI generator is turned on.

Instead of using a third XOR gate I use a simple inverter to give a 6.5Mhz signal and a
/6.5Mhz. This is further divided by 2 to give the 3.25Mhz signal required by the Z80 CPU
it is here that the first mistake can easily be made you need to connect the /3.25Mhz to ULA pin 14 remember it gets inverted by TR2 on the main board.

This is quite simply a 8 bit bus transceiver configured to always working one direction only bus B to bus A
and is enabled via signal /FERD from the above circuit.

D0 thru D7 connect to ULA pins 32,30,28,26,24,23,21 and 19 respectively.

KDB0 thru KBD4 connect to ULA pins 33,31,29,27 and 25 respectively.

TAPE in connects to ULA pin 20 UK/US connects to ULA pin 22

Based on original design by Andy Rea

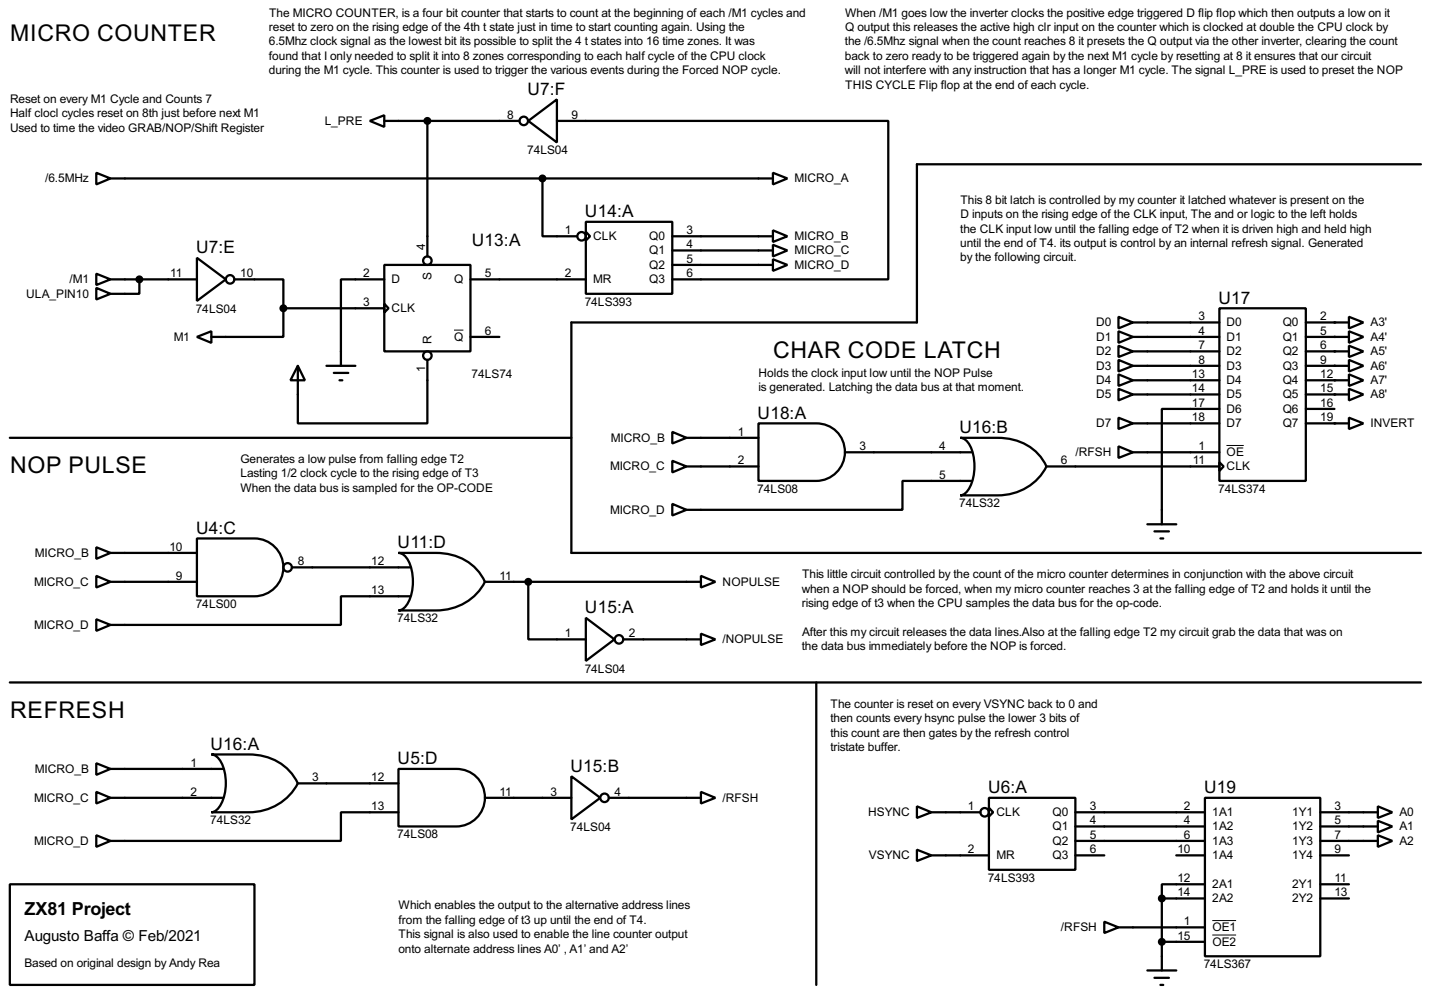
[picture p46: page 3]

The MICRO COUNTER, is a four bit counter that starts to count at the beginning of each /M1 cycles and
reset to zero on the rising edge of the 4th t state just in time to start counting again. Using the
6.5Mhz clock signal as the lowest bit its possible to split the 4 t states into 16 time zones. It was
found that I only needed to split it into 8 zones corresponding to each half cycle of the CPU clock during the M1 cycle. This counter is used to trigger the various events during the Forced NOP cycle.

When /M1 goes low the inverter clocks the positive edge triggered D flip flop which then outputs a low on it Q output this releases the active high clr input on the counter which is clocked at double the CPU clock by

the /6.5Mhz signal when the count reaches 8 it presets the Q output via the other inverter, clearing the count back to zero ready to be triggered again by the next M1 cycle by resetting at 8 it ensures that our circuit will not interfere with any instruction that has a longer M1 cycle. The signal L_PRE is used to preset the NOP

THIS CYCLE Flip flop at the end of each cycle.

Reset on every M1 Cycle and Counts 7 Half clocl cycles reset on 8th just before next M1 Used to time the video GRAB/NOP/Shift Register

This 8 bit latch is controlled by my counter it latched whatever is present on the D inputs on the rising edge of the CLK input, The and or logic to the left holds

the CLK input low until the falling edge of T2 when it is driven high and held high
until the end of T4. its output is control by an internal refresh signal. Generated
by the following circuit.

Holds the clock input low until the NOP Pulse
is generated. Latching the data bus at that moment.

Generates a low pulse from falling edge T2
Lasting 1/2 clock cycle to the rising edge of T3 When the data bus is sampled for the OP-CODE

This little circuit controlled by the count of the micro counter determines in conjunction with the above circuit when a NOP should be forced, when my micro counter reaches 3 at the falling edge of T2 and holds it until the

rising edge of t3 when the CPU samples the data bus for the op-code. After this my circuit releases the data lines.Also at the falling edge T2 my circuit grab the data that was on

the data bus immediately before the NOP is forced.

The counter is reset on every VSYNC back to 0 and
then counts every hsync pulse the lower 3 bits of
this count are then gates by the refresh control tristate buffer.

/RFSH Which enables the output to the alternative address lines
from the falling edge of t3 up until the end of T4. This signal is also used to enable the line counter output onto alternate address lines A0’ , A1’ and A2’

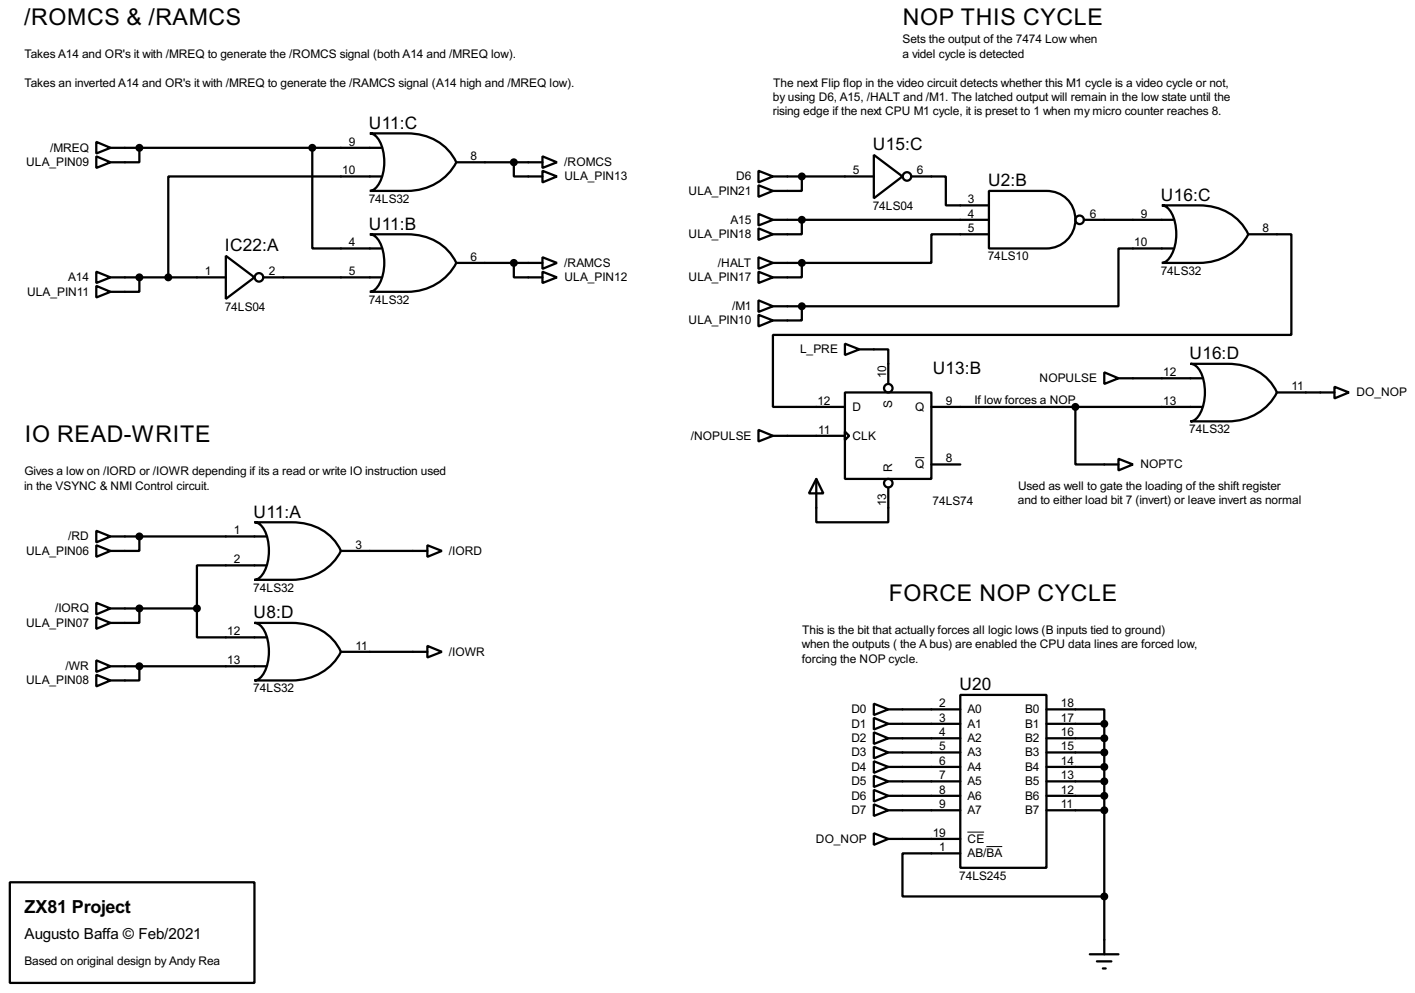
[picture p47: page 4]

Sets the output of the 7474 Low when
a videl cycle is detected

Takes A14 and OR's it with /MREQ to generate the /ROMCS signal (both A14 and /MREQ low). Takes an inverted A14 and OR's it with /MREQ to generate the /RAMCS signal (A14 high and /MREQ low).

The next Flip flop in the video circuit detects whether this M1 cycle is a video cycle or not, by using D6, A15, /HALT and /M1. The latched output will remain in the low state until the

rising edge if the next CPU M1 cycle, it is preset to 1 when my micro counter reaches 8.

If low forces a NOP

Gives a low on /IORD or /IOWR depending if its a read or write IO instruction used
in the VSYNC & NMI Control circuit.

Used as well to gate the loading of the shift register and to either load bit 7 (invert) or leave invert as normal

This is the bit that actually forces all logic lows (B inputs tied to ground) when the outputs ( the A bus) are enabled the CPU data lines are forced low,
D0D1D2D3D4D5D6D7 DO_NOP

forcing the NOP cycle.

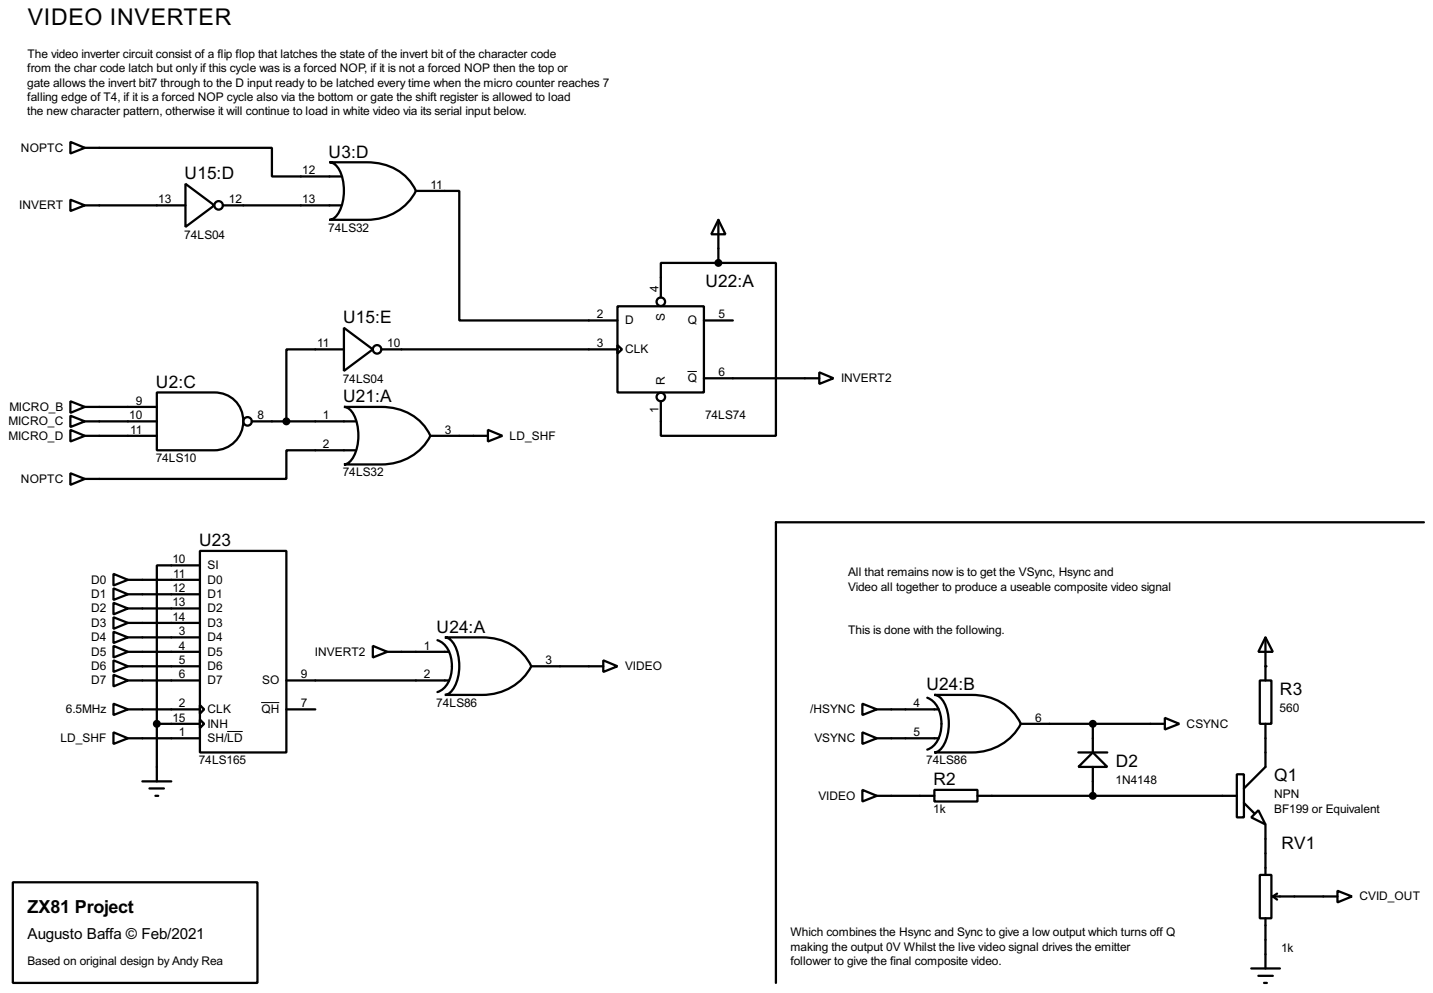
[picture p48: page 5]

The video inverter circuit consist of a flip flop that latches the state of the invert bit of the character code
from the char code latch but only if this cycle was is a forced NOP, if it is not a forced NOP then the top or gate allows the invert bit7 through to the D input ready to be latched every time when the micro counter reaches 7

falling edge of T4, if it is a forced NOP cycle also via the bottom or gate the shift register is allowed to load
the new character pattern, otherwise it will continue to load in white video via its serial input below.

All that remains now is to get the VSync, Hsync and Video all together to produce a useable composite video signal

This is done with the following.

Which combines the Hsync and Sync to give a low output which turns off Q making the output 0V Whilst the live video signal drives the emitter

follower to give the final composite video.

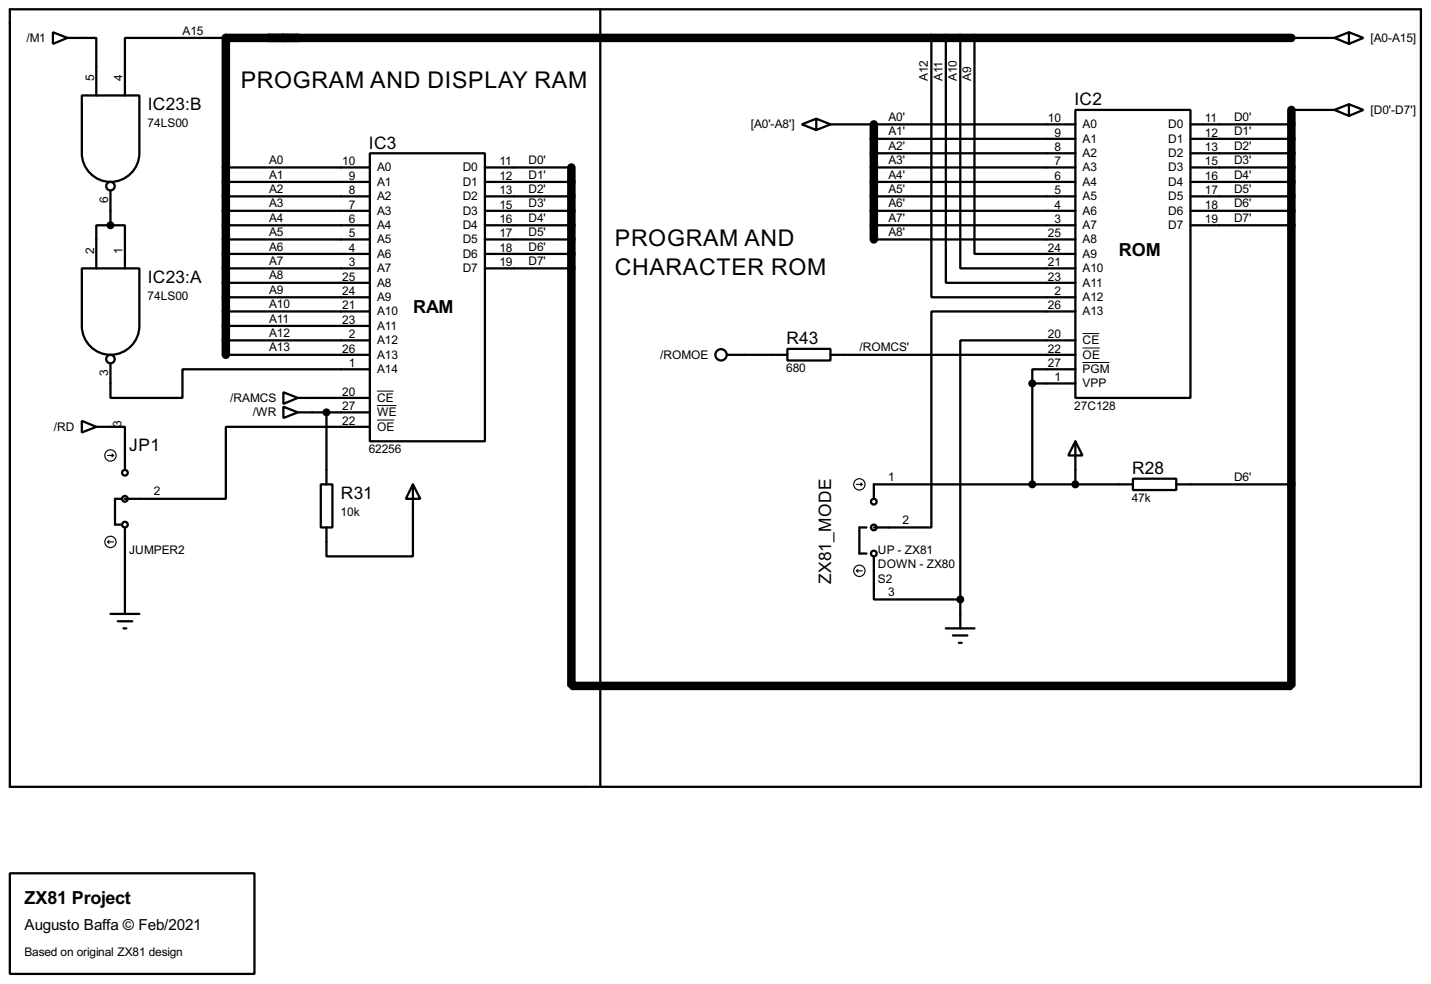
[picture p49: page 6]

Based on original ZX81 design

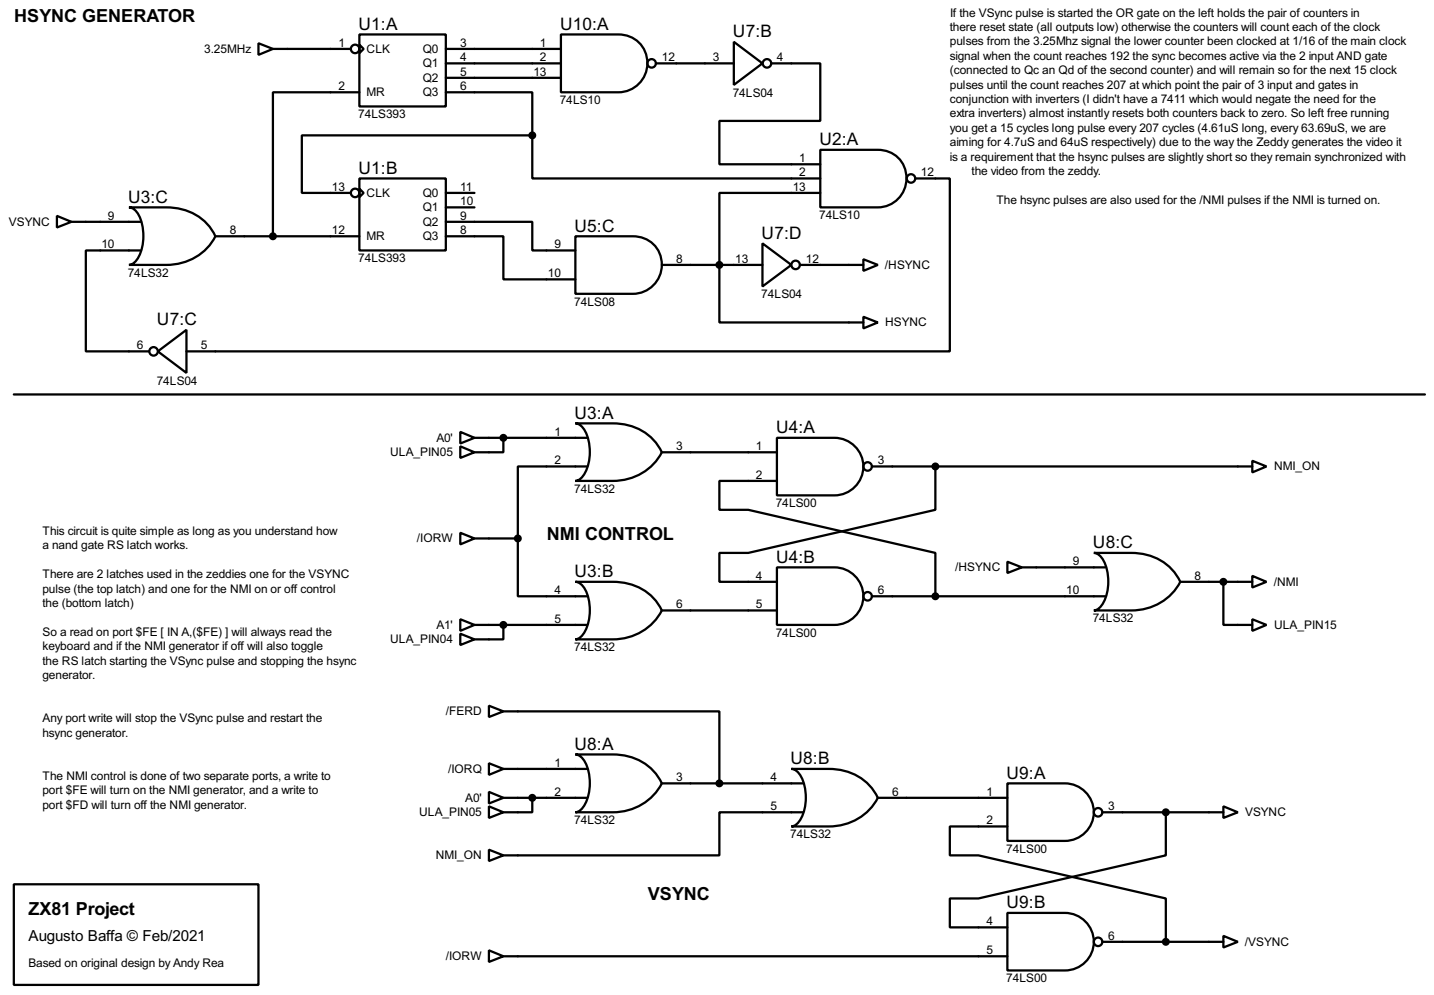
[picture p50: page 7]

If the VSync pulse is started the OR gate on the left holds the pair of counters in
there reset state (all outputs low) otherwise the counters will count each of the clock pulses from the 3.25Mhz signal the lower counter been clocked at 1/16 of the main clock

signal when the count reaches 192 the sync becomes active via the 2 input AND gate
(connected to Qc an Qd of the second counter) and will remain so for the next 15 clock pulses until the count reaches 207 at which point the pair of 3 input and gates in

conjunction with inverters (I didn't have a 7411 which would negate the need for the
extra inverters) almost instantly resets both counters back to zero. So left free running
you get a 15 cycles long pulse every 207 cycles (4.61uS long, every 63.69uS, we are
aiming for 4.7uS and 64uS respectively) due to the way the Zeddy generates the video it
is a requirement that the hsync pulses are slightly short so they remain synchronized with
the video from the zeddy. The hsync pulses are also used for the /NMI pulses if the NMI is turned on.

U1:B
13 | Q0 CLK | | 13

This circuit is quite simple as long as you understand how
a nand gate RS latch works. There are 2 latches used in the zeddies one for the VSYNC

pulse (the top latch) and one for the NMI on or off control the (bottom latch) So a read on port $FE [ IN A,($FE) ] will always read the

keyboard and if the NMI generator if off will also toggle
the RS latch starting the VSync pulse and stopping the hsync generator.

Any port write will stop the VSync pulse and restart the
hsync generator.

The NMI control is done of two separate ports, a write to
port $FE will turn on the NMI generator, and a write to
port $FD will turn off the NMI generator.

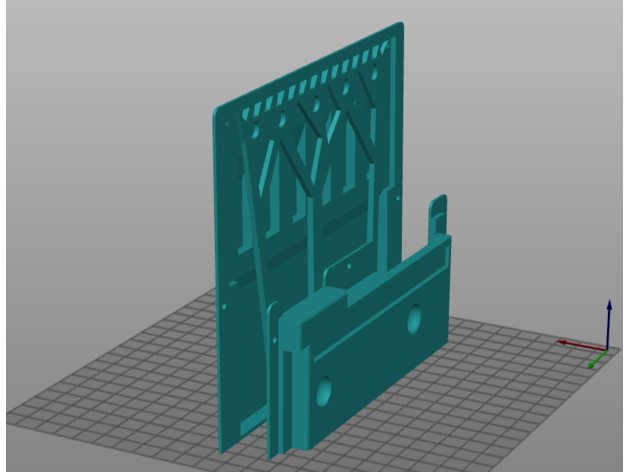
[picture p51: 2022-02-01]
case_zx80/case3/images/Bottom_On_3D_Printer_2.PNG

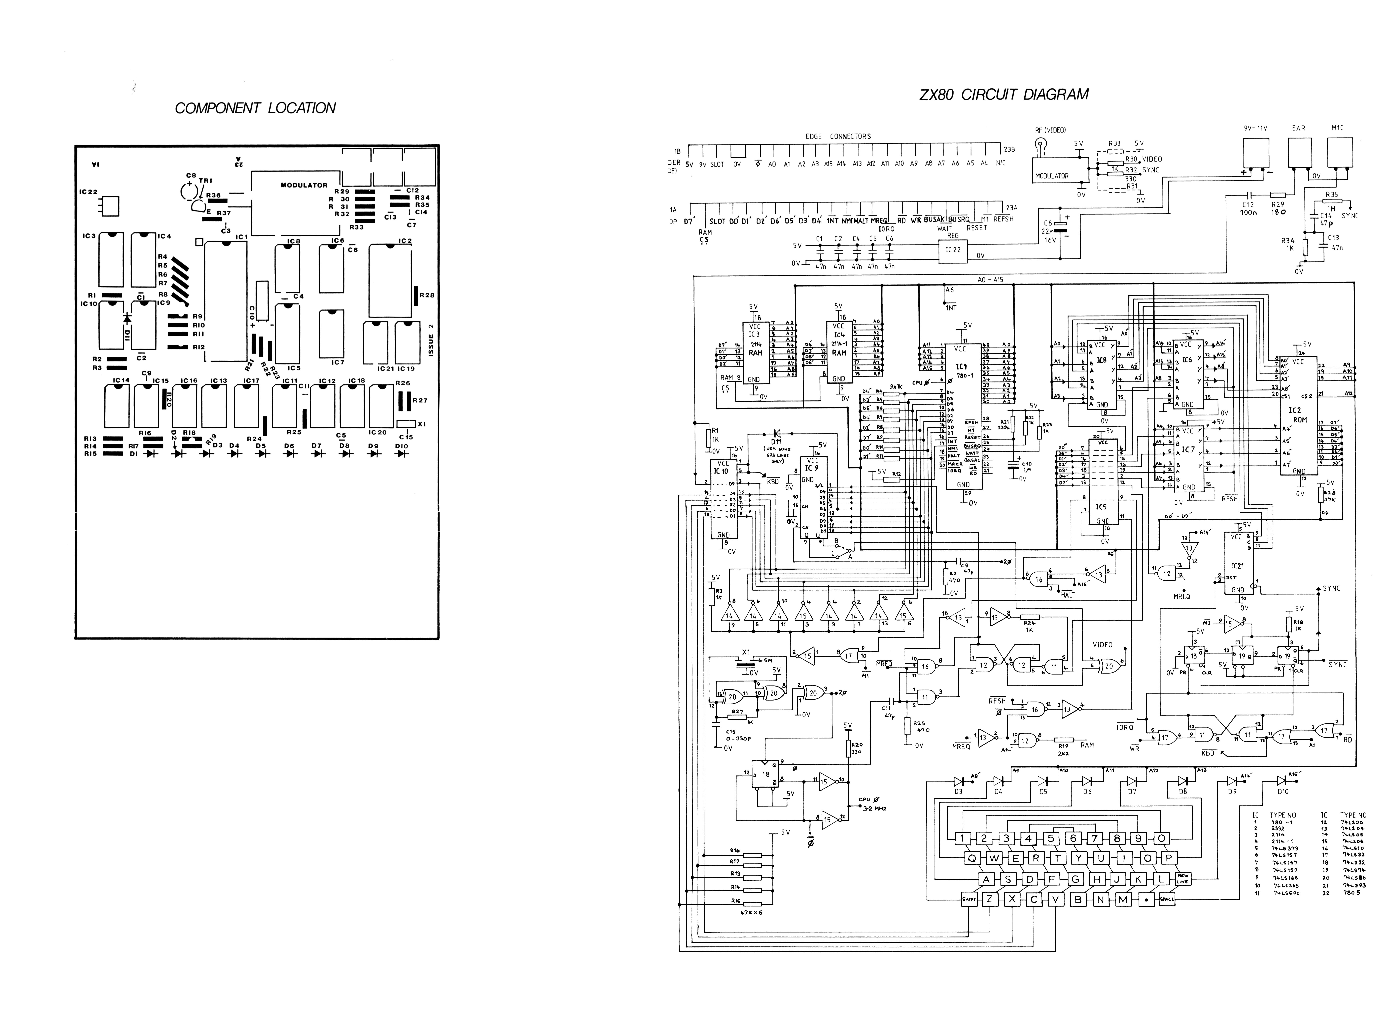
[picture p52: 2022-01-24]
_manual/ZX80_Assembly_Part2.jpeg

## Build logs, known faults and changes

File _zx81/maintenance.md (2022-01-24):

# ZX81 Maintenance

## Video Signal Generation

The video signal is generated by the ULA. Said signal is transmitted from pin 16 of the ULA to the RF modulator.

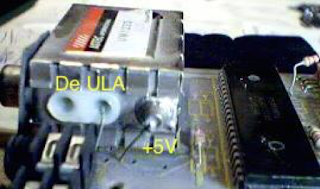
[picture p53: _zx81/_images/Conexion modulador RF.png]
Rf Modulator


The ULAs models 2C158E and 2C184E do not generate the "backporch" signal, so the image on a modern TV comes out very black, even after adjusting the contrast or brightness. Something that was not a problem in old TVs since they were not very sensitive to this signal, although the PAL and NTSC standards were not exactly met. The ULA model 2C210E solves this problem.

During software LOAD and SAVE operations using an external player connected to the corresponding jacks on the computer, the tuning signal to the TV is lost. This is because the TV signal and the connection to the TAPE jack share the same ULA pin (pin 16). This TAPE jack is connected to the MIC jack on the computer. The ULA cannot undertake both operations at the same time, TV signal generation and the TAPE/TAPE IN operation.

The following figure shows the typical display pattern of signal loss during software upload and write operations.

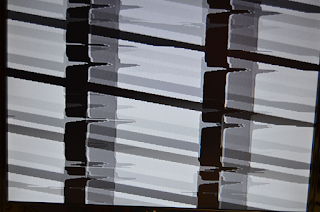
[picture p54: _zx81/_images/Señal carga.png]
loading_signal Loading signal


If the ZX81 has a video circuit that allows the use of a modern TV through a composite video or SCART socket, it is very possible that the signal is completely lost (black screen), recovering again after finishing charging or recording.

Below is the part of the schematic that shows the TV signal generation circuit. 

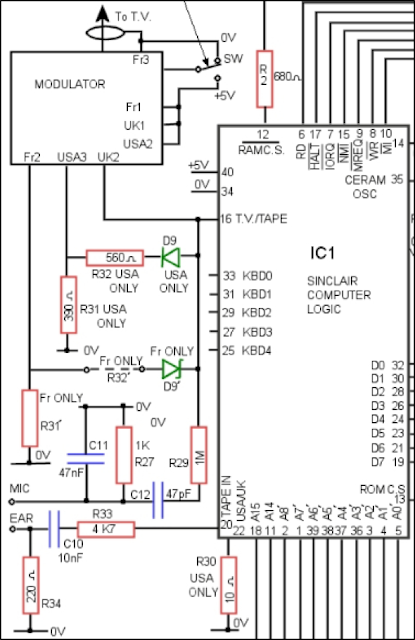
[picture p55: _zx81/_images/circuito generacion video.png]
Video_Generation_Circuit Video Generation Circuit


## Improved Video Output Quality

There are several alternatives to improve the quality of the video signal that can be consulted on various websites. It is recommended to consult these websites to see the modification proposal.

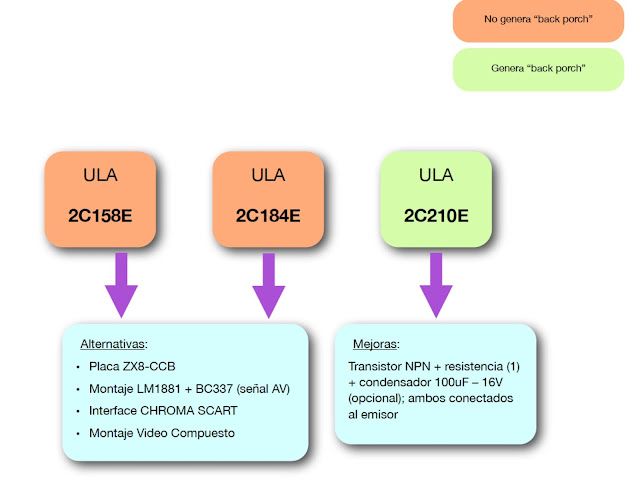
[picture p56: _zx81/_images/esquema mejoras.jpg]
ULA Improvements


(1) The values of the resistor connected to the emitter of the NPN transistor vary depending on the
source: 33, 75, 82 and 100 ohms.

### References

* [Website The Spectrum Storage Room](http://trastero.speccy.org/)
* [ZX-TEAM website](http://www.zx81.de/)
* [Blog old8bits](http://old8bits.blogspot.com.es/)

## Generating Composite Video Signal

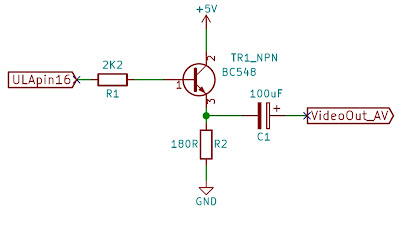
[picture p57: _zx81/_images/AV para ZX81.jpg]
Composite Video


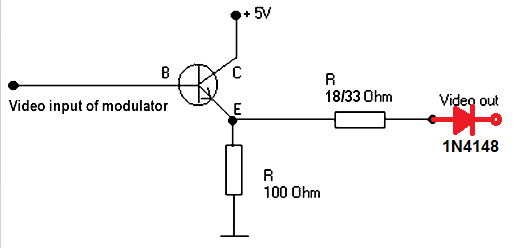
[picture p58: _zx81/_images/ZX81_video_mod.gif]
Composite Video2


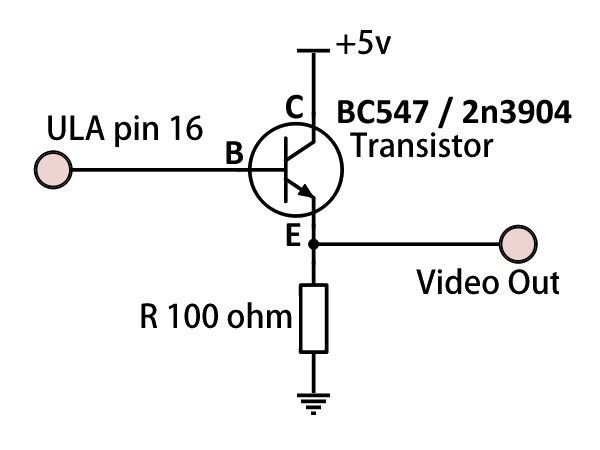
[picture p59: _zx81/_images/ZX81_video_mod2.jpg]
Composite Video3


## Keyboard Membrane Replacement

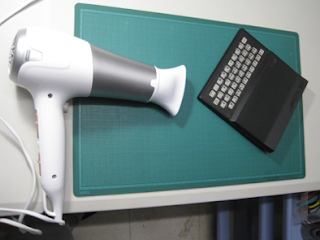
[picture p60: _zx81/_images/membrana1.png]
Membrane 1 Menbrane 1


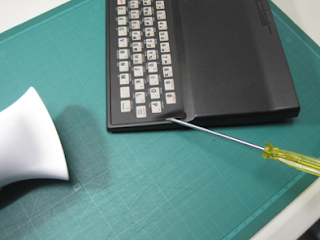
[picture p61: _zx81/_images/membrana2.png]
Membrane 2 Menbrane 2


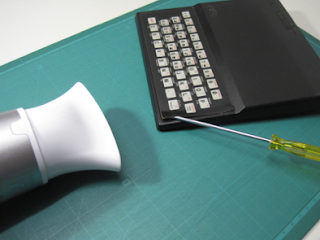
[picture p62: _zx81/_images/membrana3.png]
Membrane 3 Menbrane 3


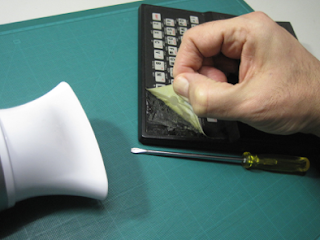
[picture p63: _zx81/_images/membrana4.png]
Membrane 4 Menbrane 4


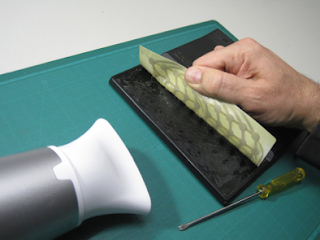
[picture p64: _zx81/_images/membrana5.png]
Membrane 5 Menbrane 5


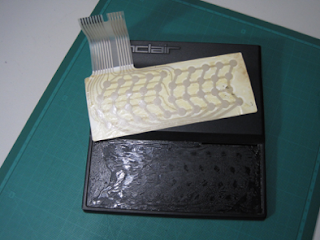
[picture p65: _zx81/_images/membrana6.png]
Membrane 6 Menbrane 6


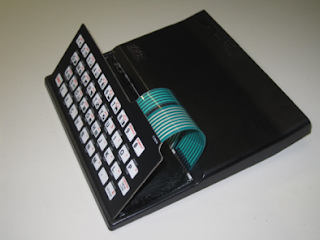
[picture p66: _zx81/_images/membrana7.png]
Membrane 7 Menbrane 7


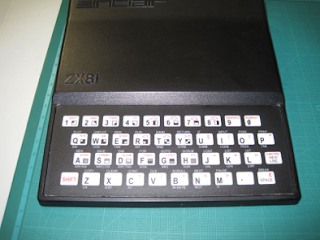
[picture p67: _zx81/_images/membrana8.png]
Membrane 8 Menbrane 8


## Increasing Useful Life

The ULA is, together with the 7805 regulator, the component that generates the most heat inside the computer. Some tests carried out with a heatsink on the ULA have managed to lower the temperature by more than 10ºC. Also on the ZX81, there is space between the top of the ULA and the case for installation.

The other element to replace is the 7805 regulator, whose task is to convert and regulate the unregulated voltage that comes from the power supply from +9V to +5V. The unnecessary intensity is evacuated in the form of heat through the dissipating plate to which it is screwed.

This set can be replaced by more modern regulators, which do not heat up and therefore do not need a heatsink, such as the TracoPower ones. The suitable TracoPower model is the TSR 1-2450 that allows currents of 1A, and a wide range of input voltages (6.5 - 36 VDC). It is not necessary to install a capacitor to filter the ripple of the output signal since the TracoPower already incorporates these filter capacitors in its internal circuit.

Other components different from the one proposed are perfectly valid taking into account the criteria of size, regulation, intensity and voltage delivered, and temperature generated.

Indirectly, changing this component also has the benefit of lengthening the life of the keyboard membrane, whose connectors are very close to the heat dissipating plate.

Replacement of electrolytic capacitors is always recommended after several years. The ZX81 only has two electrolytic capacitors (C3 and C5) so this operation is simple.

## HRG on Original Memory Expansion Modules

Original memory expansion modules, such as those from Sinclair, Timex, or Memotech, do not support the use of High-Resolution Graphics (HRG or HIRES) routines. There are two mounting schemes that can be found on the web, although both are very similar and vary only in the value of the resistors.

The software that uses the HIRES routines requires 6 kB of memory and RAM to be available during memory refresh. The mount does just that, isolating the RFSH and RD signals from memory expansion. This circuit converts each refresh cycle into a read cycle.

The assembly shown is based on the ZX-Team schematic. Another assembly is the one proposed by Wilf Ritger in his web-tutorial on the ZX81 video system.

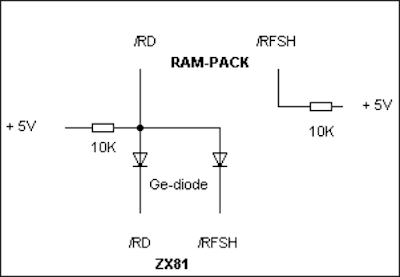
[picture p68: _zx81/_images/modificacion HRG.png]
HGR Mod


This modification can be done on a rear bus expansion board so that neither the original ZX81 board nor the memory expansion module have to be modified. In this case, a ZX81XT board like the one shown in the following photo has been used.

The diode model used for assembly is 1N34A.

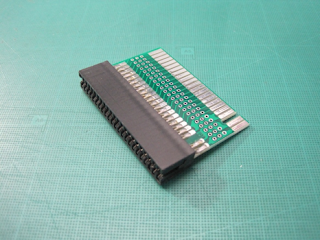
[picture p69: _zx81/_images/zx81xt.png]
HGR Mod xt


You have to identify the pins corresponding to the RFSH and RD signals and isolate them from their corresponding track.

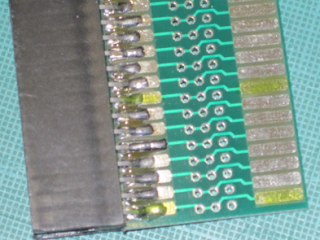
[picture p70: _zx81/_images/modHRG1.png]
HGR Mod1


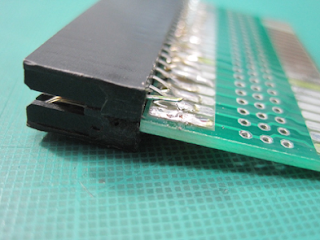
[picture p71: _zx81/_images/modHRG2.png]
HGR Mod2


The following photo shows the final assembly.

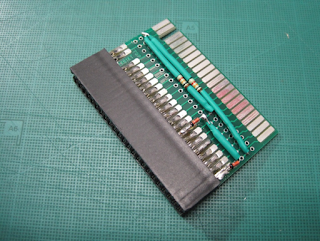
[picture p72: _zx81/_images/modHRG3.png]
HGR Mod3


### References

* [ZX81 Video Tutorial by Wilf Ritger](http://www.user.dccnet.com/wrigter/index_files/ZX%20Video%20Tutorial.htm)
* [Video Output ZX-TEAM web](http://www.zx81.de/english/_frame_e.htm)

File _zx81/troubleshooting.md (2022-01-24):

# ZX81 Troubleshooting

Leaving aside the signal tuning problems in modern TVs and the keyboard membrane, a list of the most common failures would be the following:

* Failures in the ULA other than the tuning of the TV signal. A clear symptom is the lack of image generation, or sometimes showing the screen in white with black lines forming some pattern, without showing the K cursor. In this type of pattern, also check the CPU.
* Connection faults in the contacts in the power connector, which is a Jack type (3.5 mm). The same jacks are used for the EAR and MIC connections, which can also be faulty. It is recommended to insert the power connector without the power supply being connected to the network.
* The ZX81 only works in FASTs mode. Check the circuit formed by TR1, C1, R1 and R17. Normally, TR1 is the element that has failed.
* Black screen and computer does not work, that is, it is not a fault related to the generation of the TV signal. Check that the 3.5MHz CLK signal is generated. Using an oscilloscope or logic probe, check the clock signal on pin 14 of the ULA. If the value is obtained, the generation is correct by the ULA. Then check the signal on pin 6 of the CPU. If it is not generated correctly, check the circuit formed by TR2, C7, R5 and R6. The normal thing is that transistor TR2 has failed. Another fault that causes a black screen is ROM or CPU failure, either because the ROM routines cannot be accessed or cannot be executed.
* Blank screen, without the K cursor appearing. It is a fault that can be attributed to the RAM or the ROM. The CPU executes the “START” routine of the ROM that the first thing it does is check the RAM (“RAM-CHECK” routine), and after this check the “INITIALISATION” routine is executed. This routine ends by displaying the cursor. Therefore, not showing the cursor is a symptom that some action has not been executed correctly for whatever reason. The most normal thing is that the “RAM-CHECK” routine has not obtained any expected value in the RAM check, keeping in mind that the “RAM-CHECK” routine is only executed if the ZX81 has 16kB.
* Integrated located in sockets. Many times, the problems are derived from bad connections, so a good cleaning and checking of the contacts may be enough. Sometimes the 24-pin ROM is plugged into a 28-pin socket. The correct connection is with the ROM aligned towards the bottom edge, i.e. the one closest to the heat sink.

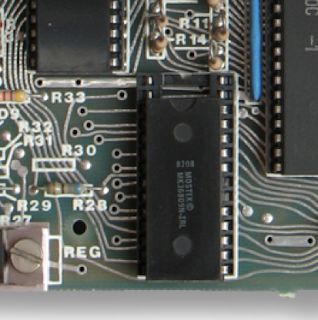
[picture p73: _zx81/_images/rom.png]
Rom


On the ZX81 board there is only one voltage level, besides GND: +5V. Although these levels can be checked in the 7805 regulator, it is worth doing a quick check in the integrated ones. The following table shows the relationship of pins with the voltage levels in each of the integrated ones.

|  | CPUs | ULA | ROM | RAM 2114 | RAM 4118 | RAM 4816 |
|--|---|-----|-----|---|---|---|
| GND | P29 | P34 | P12 | P9 | P12 | P14 |
| +5V | P11 | P40 | P24 | P18 | P24 | P28 |

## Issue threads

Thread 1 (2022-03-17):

authorship and acknowledgments removed

wilco2009, 2022-03-17:
I have no problem with people making modifications to my PCB but it's not okay to remove my authorship and acknowledgments. Please, I beg you to put them back and notify hackaday (jenny list article) that it is a derivative work of mine.

[Wilco2009 blog](https://www.google.com/url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)

Closed 2022-03-17.

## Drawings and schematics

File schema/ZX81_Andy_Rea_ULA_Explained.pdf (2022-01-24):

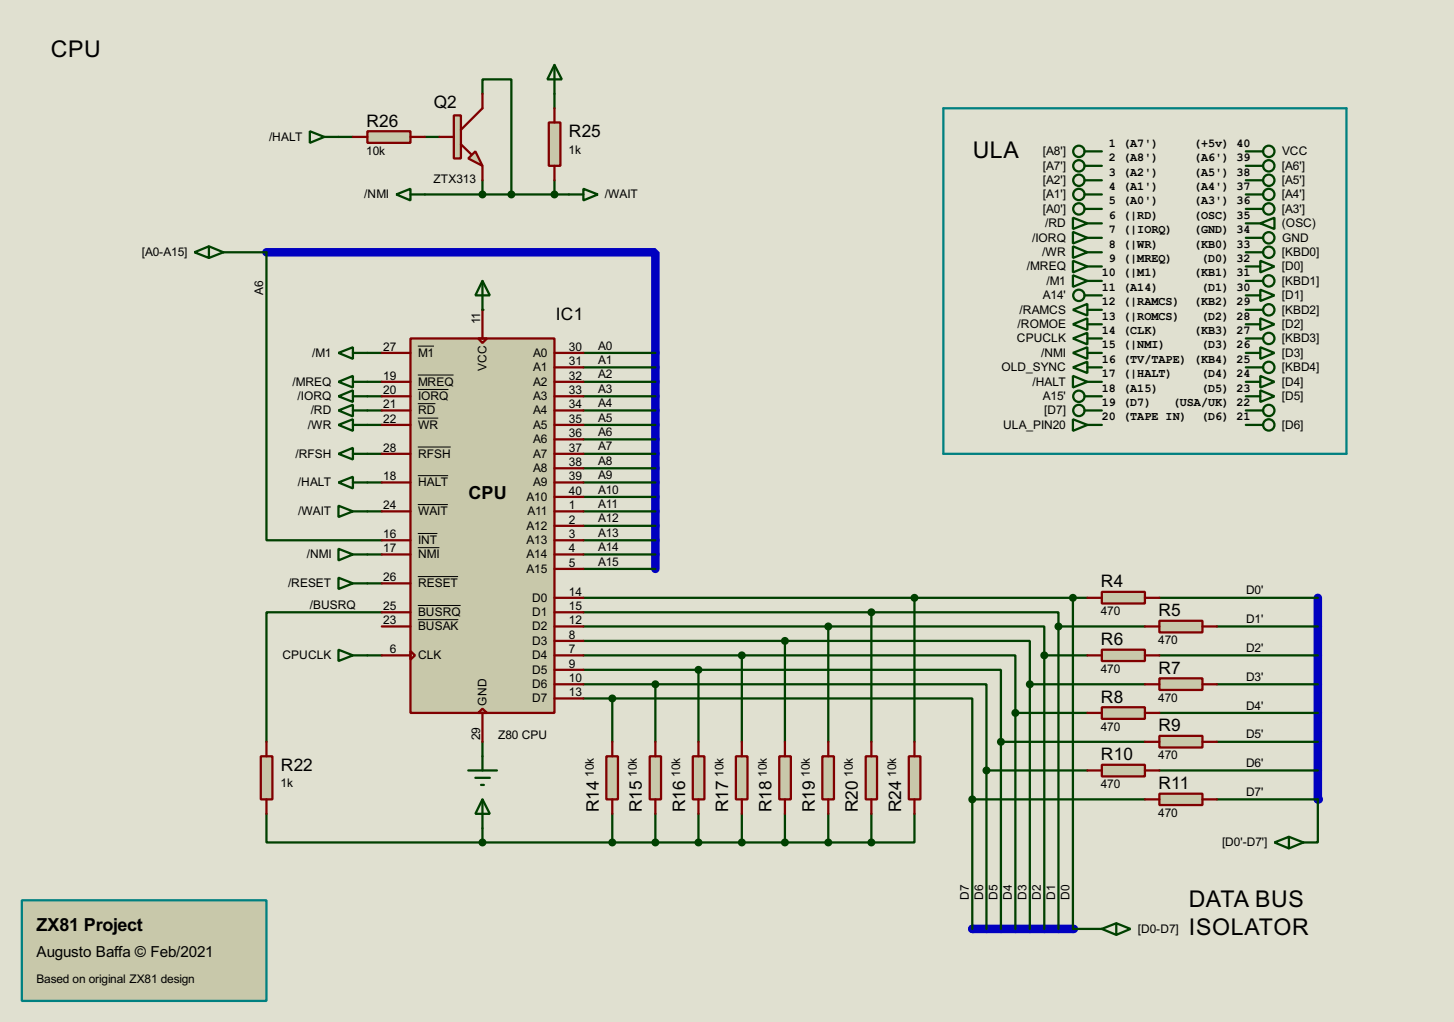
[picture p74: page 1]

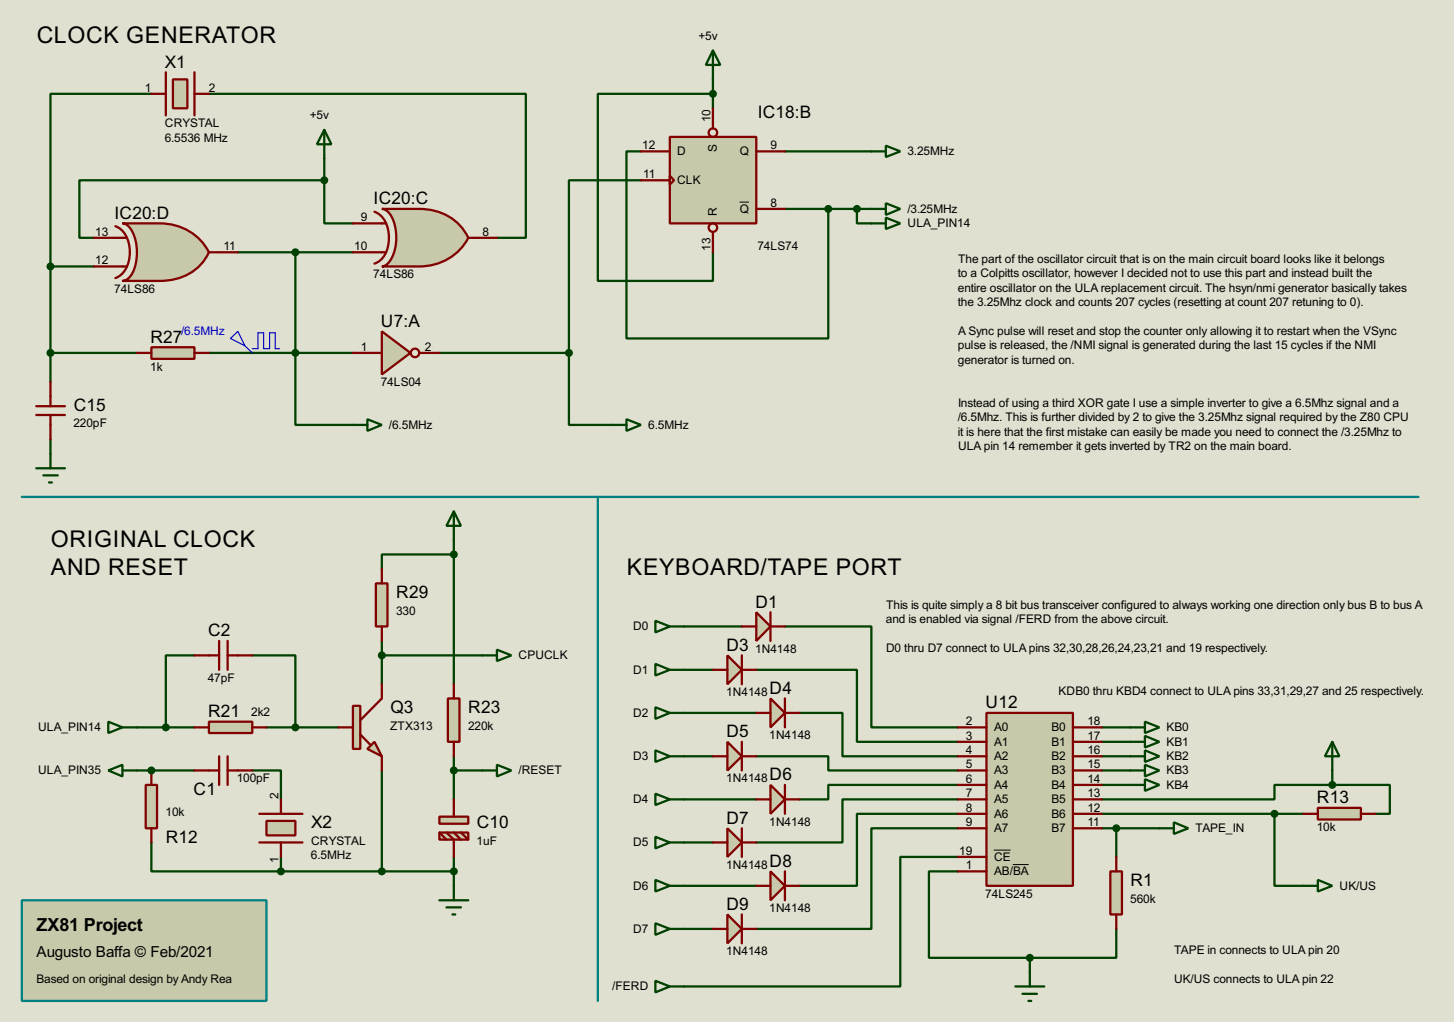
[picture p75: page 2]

The part of the oscillator circuit that is on the main circuit board looks like it belongs
to a Colpitts oscillator, however I decided not to use this part and instead built the
entire oscillator on the ULA replacement circuit. The hsyn/nmi generator basically takes
the 3.25Mhz clock and counts 207 cycles (resetting at count 207 retuning to 0). A Sync pulse will reset and stop the counter only allowing it to restart when the VSync pulse is released, the /NMI signal is generated during the last 15 cycles if the NMI generator is turned on.

Instead of using a third XOR gate I use a simple inverter to give a 6.5Mhz signal and a
/6.5Mhz. This is further divided by 2 to give the 3.25Mhz signal required by the Z80 CPU
it is here that the first mistake can easily be made you need to connect the /3.25Mhz to ULA pin 14 remember it gets inverted by TR2 on the main board.

This is quite simply a 8 bit bus transceiver configured to always working one direction only bus B to bus A
and is enabled via signal /FERD from the above circuit.

D0 thru D7 connect to ULA pins 32,30,28,26,24,23,21 and 19 respectively.

KDB0 thru KBD4 connect to ULA pins 33,31,29,27 and 25 respectively.

TAPE in connects to ULA pin 20 UK/US connects to ULA pin 22

Based on original design by Andy Rea

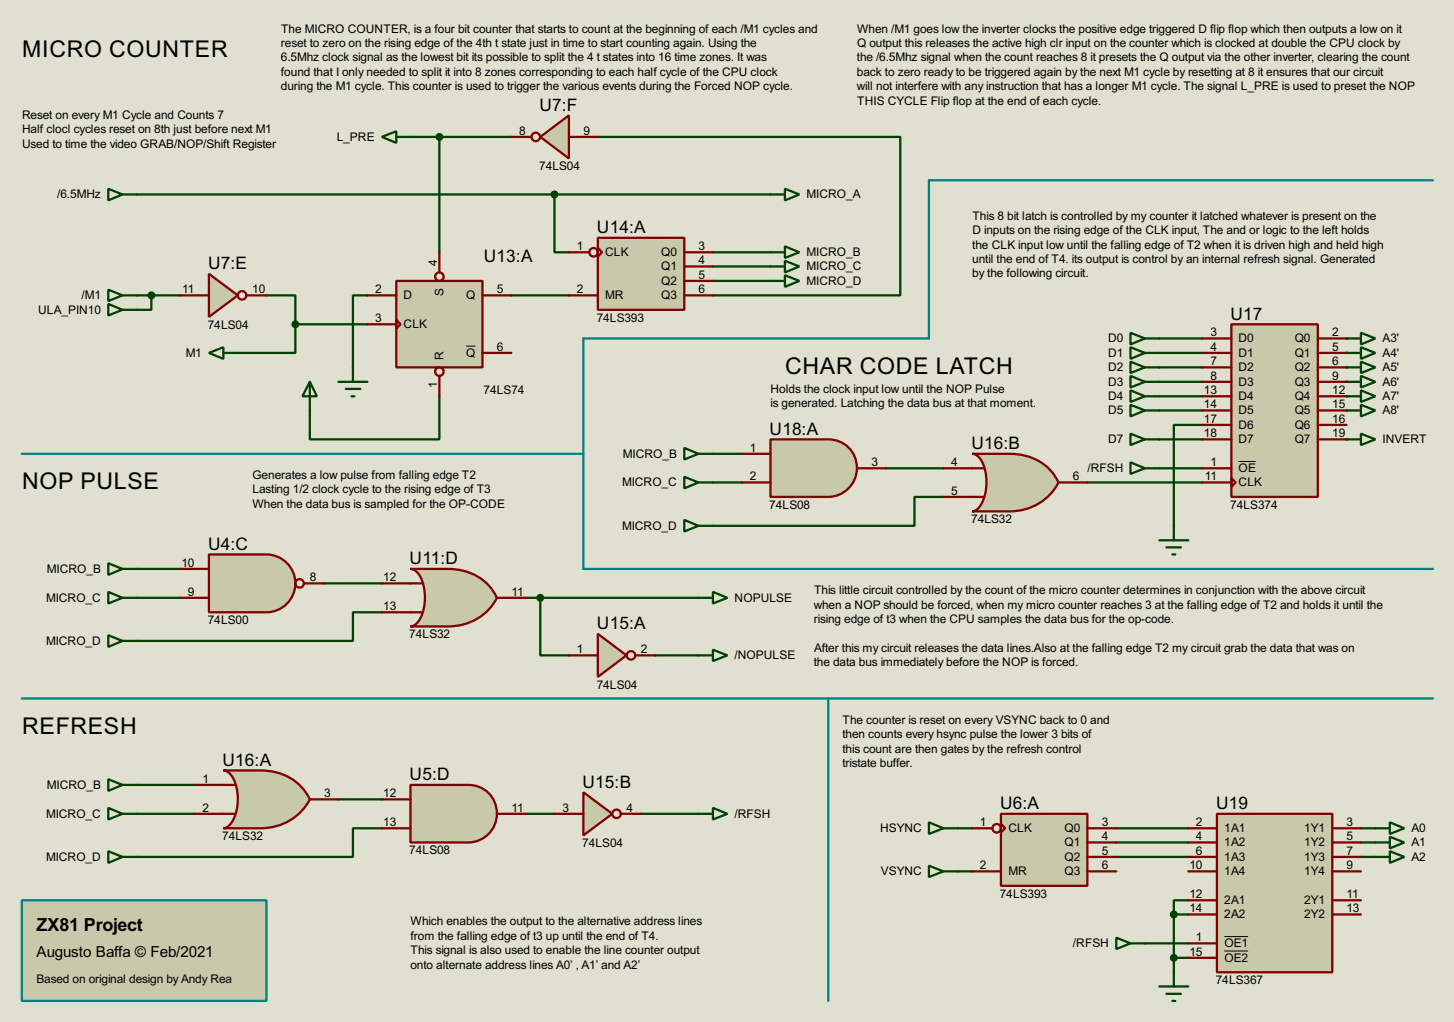
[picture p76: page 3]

The MICRO COUNTER, is a four bit counter that starts to count at the beginning of each /M1 cycles and
reset to zero on the rising edge of the 4th t state just in time to start counting again. Using the
6.5Mhz clock signal as the lowest bit its possible to split the 4 t states into 16 time zones. It was
found that I only needed to split it into 8 zones corresponding to each half cycle of the CPU clock during the M1 cycle. This counter is used to trigger the various events during the Forced NOP cycle.

When /M1 goes low the inverter clocks the positive edge triggered D flip flop which then outputs a low on it Q output this releases the active high clr input on the counter which is clocked at double the CPU clock by

the /6.5Mhz signal when the count reaches 8 it presets the Q output via the other inverter, clearing the count back to zero ready to be triggered again by the next M1 cycle by resetting at 8 it ensures that our circuit will not interfere with any instruction that has a longer M1 cycle. The signal L_PRE is used to preset the NOP

THIS CYCLE Flip flop at the end of each cycle.

Reset on every M1 Cycle and Counts 7 Half clocl cycles reset on 8th just before next M1 Used to time the video GRAB/NOP/Shift Register

This 8 bit latch is controlled by my counter it latched whatever is present on the D inputs on the rising edge of the CLK input, The and or logic to the left holds

the CLK input low until the falling edge of T2 when it is driven high and held high
until the end of T4. its output is control by an internal refresh signal. Generated
by the following circuit.

Holds the clock input low until the NOP Pulse
is generated. Latching the data bus at that moment.

Generates a low pulse from falling edge T2
Lasting 1/2 clock cycle to the rising edge of T3 When the data bus is sampled for the OP-CODE

This little circuit controlled by the count of the micro counter determines in conjunction with the above circuit when a NOP should be forced, when my micro counter reaches 3 at the falling edge of T2 and holds it until the

rising edge of t3 when the CPU samples the data bus for the op-code. After this my circuit releases the data lines.Also at the falling edge T2 my circuit grab the data that was on

the data bus immediately before the NOP is forced.

The counter is reset on every VSYNC back to 0 and
then counts every hsync pulse the lower 3 bits of
this count are then gates by the refresh control tristate buffer.

/RFSH Which enables the output to the alternative address lines
from the falling edge of t3 up until the end of T4. This signal is also used to enable the line counter output onto alternate address lines A0’ , A1’ and A2’

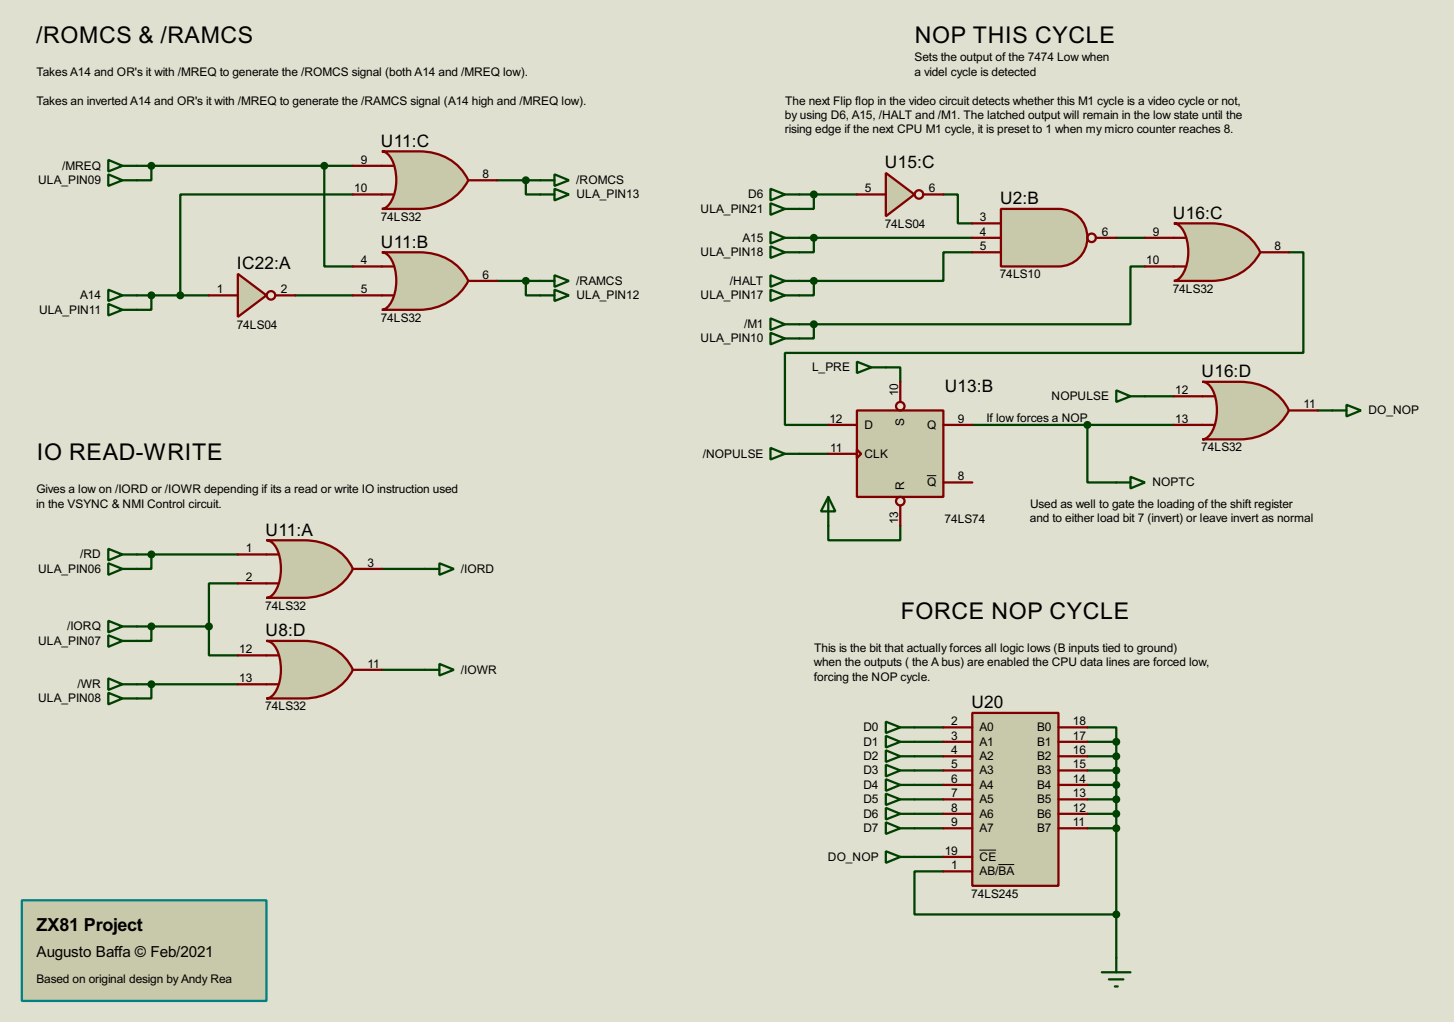
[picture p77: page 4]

Sets the output of the 7474 Low when
a videl cycle is detected

Takes A14 and OR's it with /MREQ to generate the /ROMCS signal (both A14 and /MREQ low). Takes an inverted A14 and OR's it with /MREQ to generate the /RAMCS signal (A14 high and /MREQ low).

The next Flip flop in the video circuit detects whether this M1 cycle is a video cycle or not, by using D6, A15, /HALT and /M1. The latched output will remain in the low state until the
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

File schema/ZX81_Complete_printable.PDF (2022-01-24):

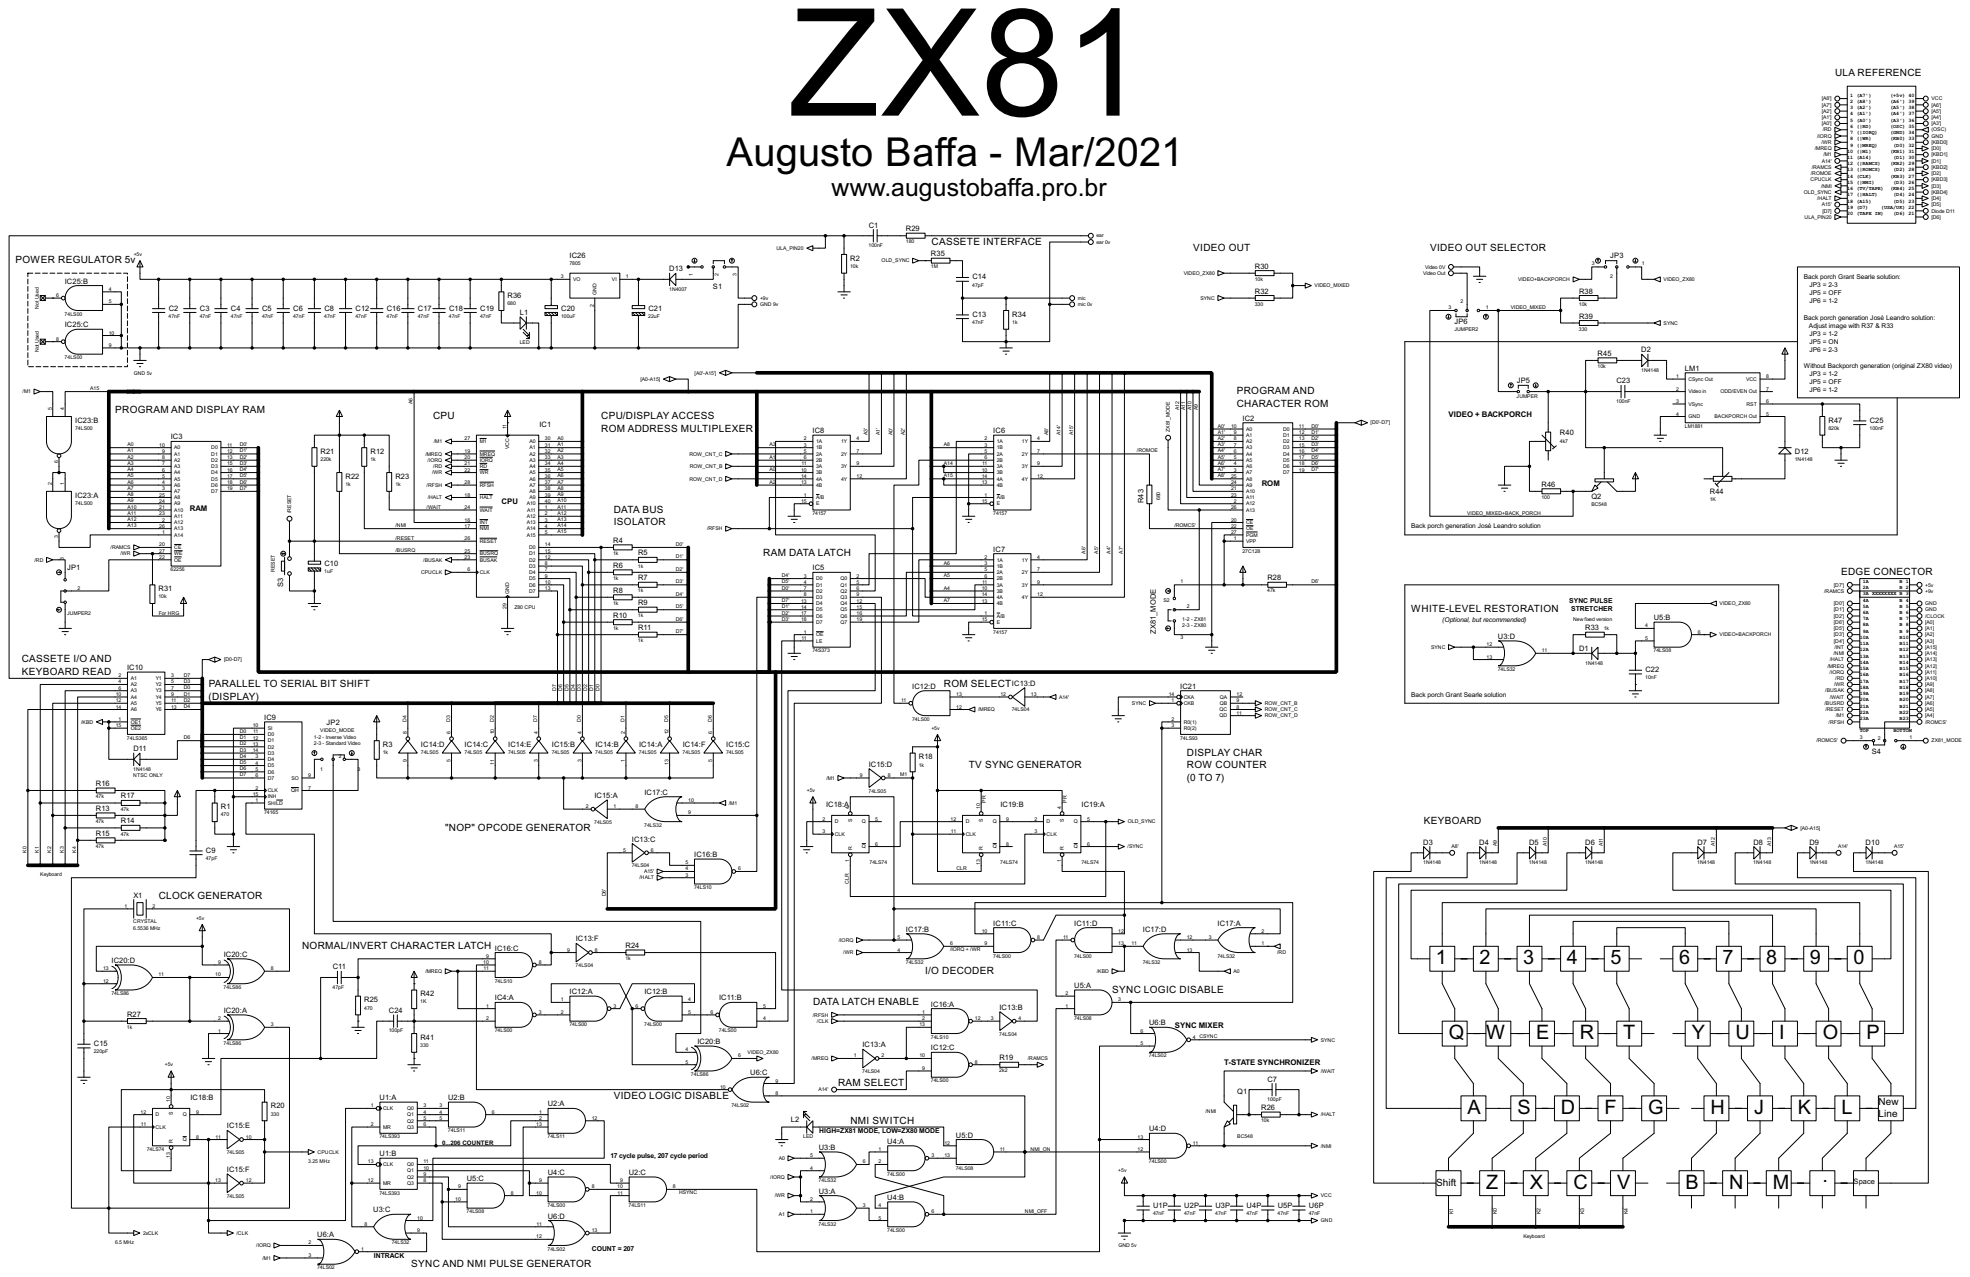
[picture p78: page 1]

Back porch Grant Searle solution: JP3 = 2-3

Not Used

Back porch generation José Leandro solution: Adjust image with R37 & R33

Back porch generation José Leandro solution

11

Back porch Grant Searle solution

5 CLK 6 | 9 CLK | 5 CLK 6

CLR

NORMAL/INVERT CHARACTER LATCH

/RFSH DATA LATCH ENABLE

HIGH=ZX81 MODE, LOW=ZX80 MODE

17 cycle pulse, 207 cycle period

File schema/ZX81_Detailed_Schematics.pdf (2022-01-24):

# ZX80/81 Project

# by Augusto Baffa, Phd

# Assembled and Tested - Feb/2021

# http://www.augustobaffa.pro.br/

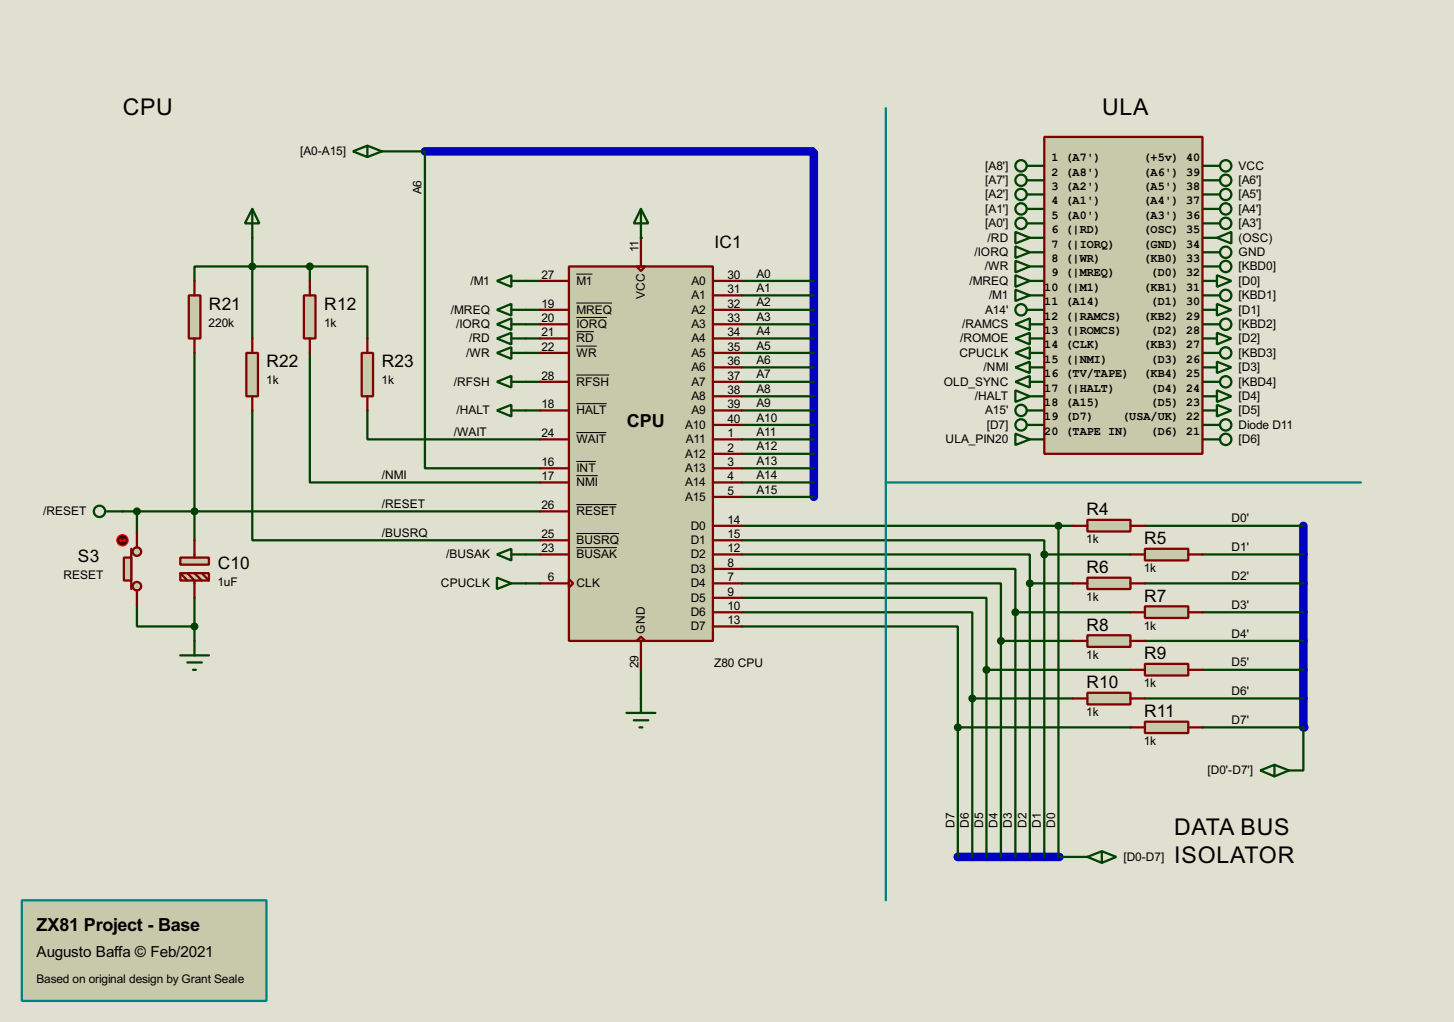
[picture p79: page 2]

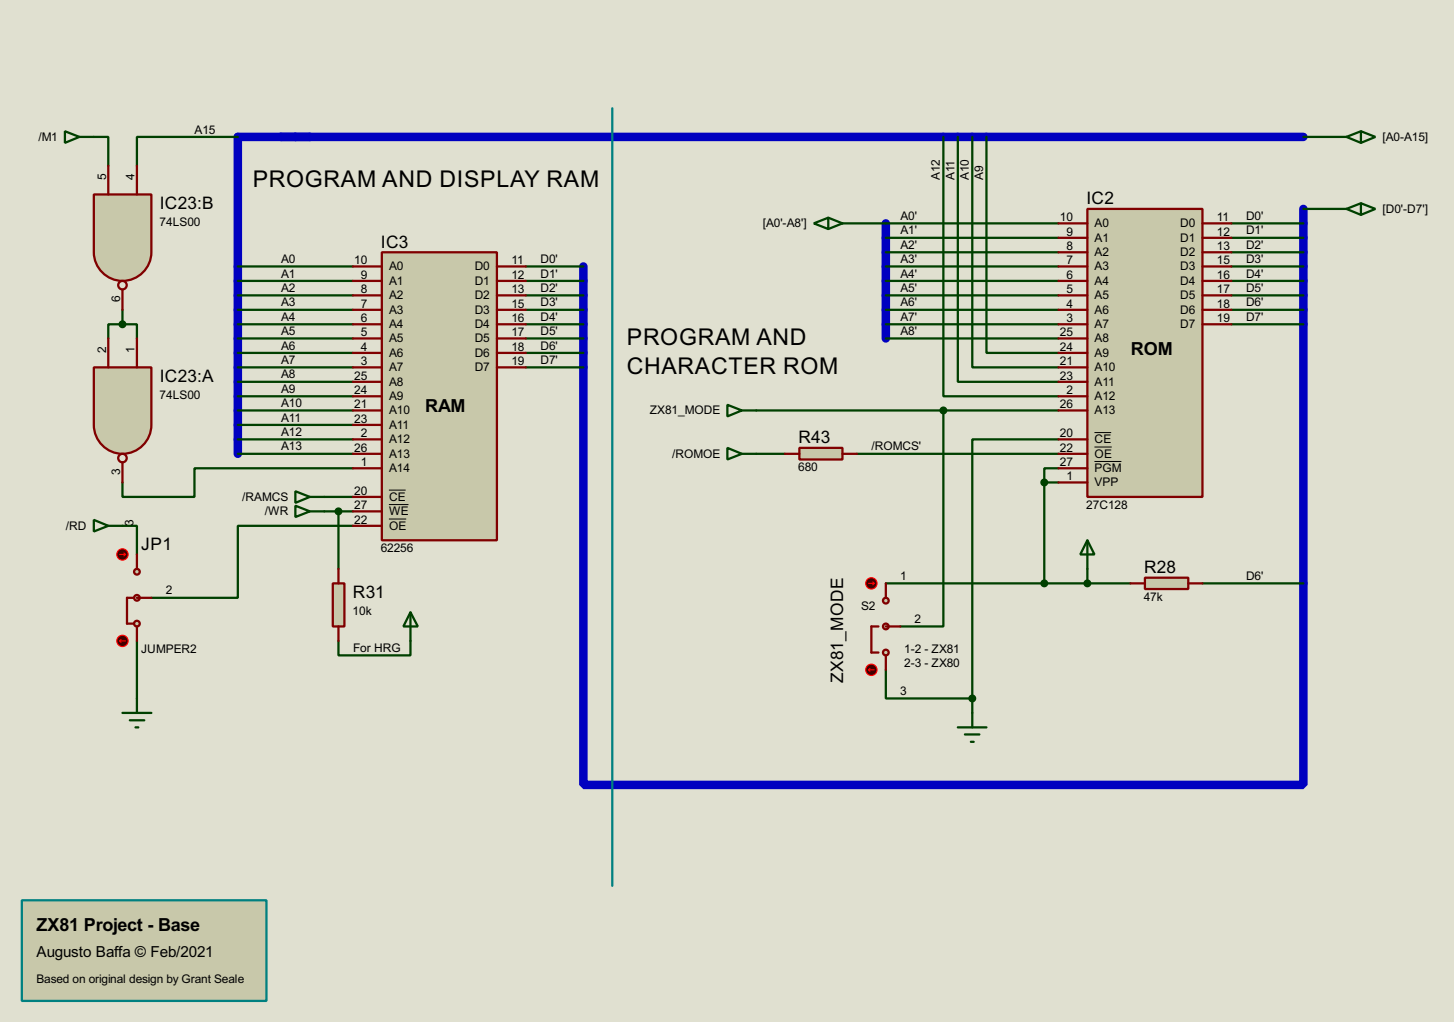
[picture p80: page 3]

Based on original design by Grant Seale

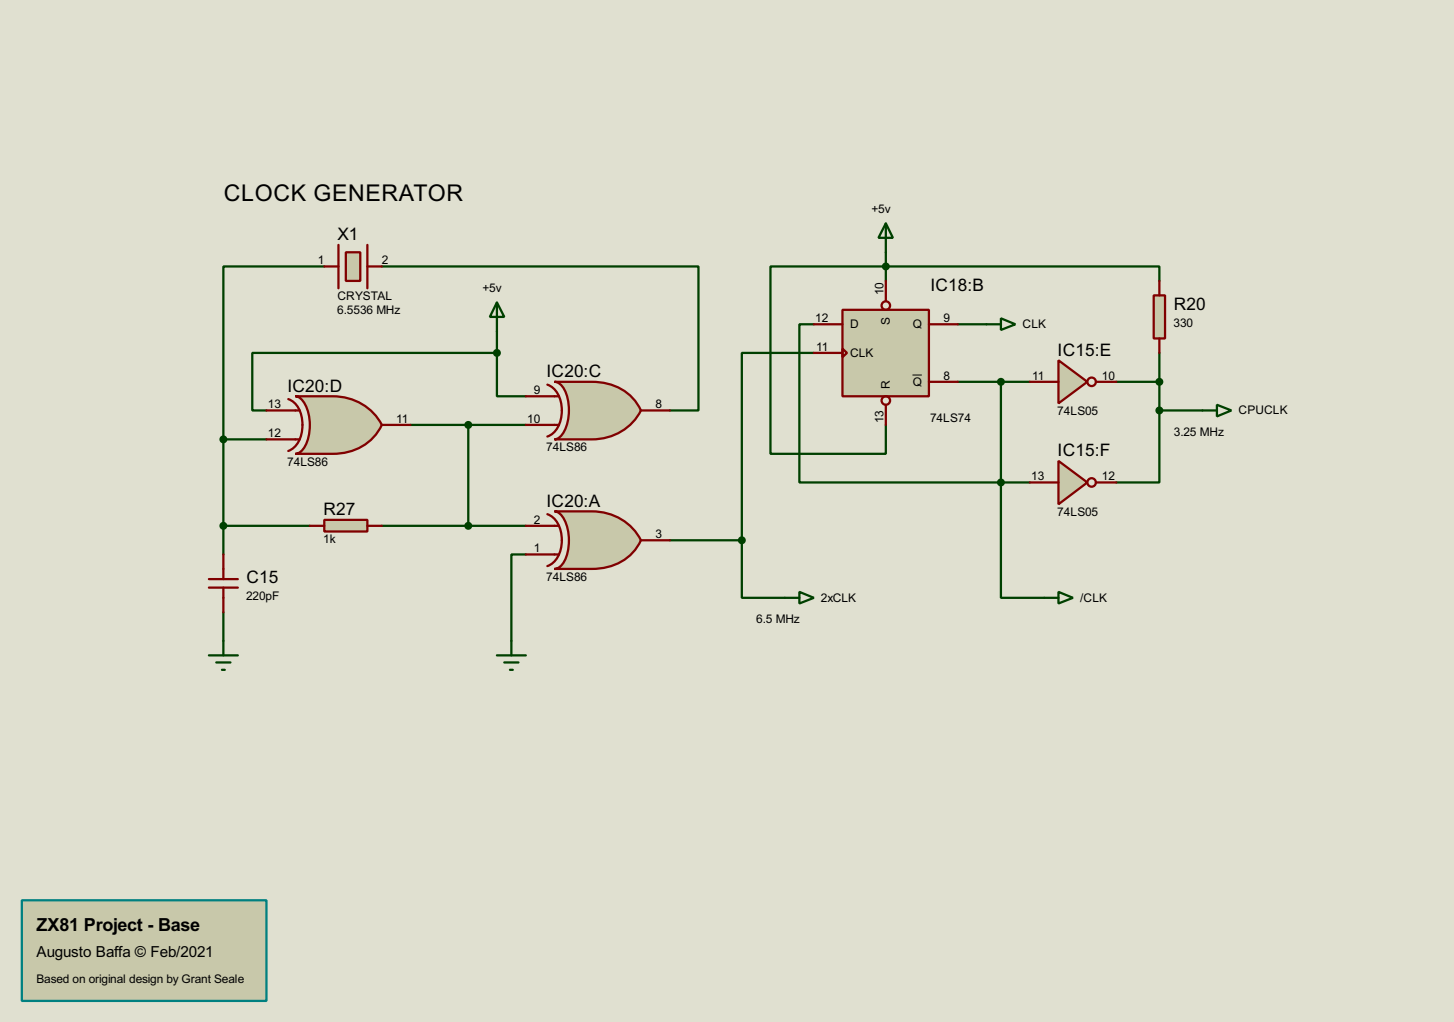
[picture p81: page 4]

9 CLK

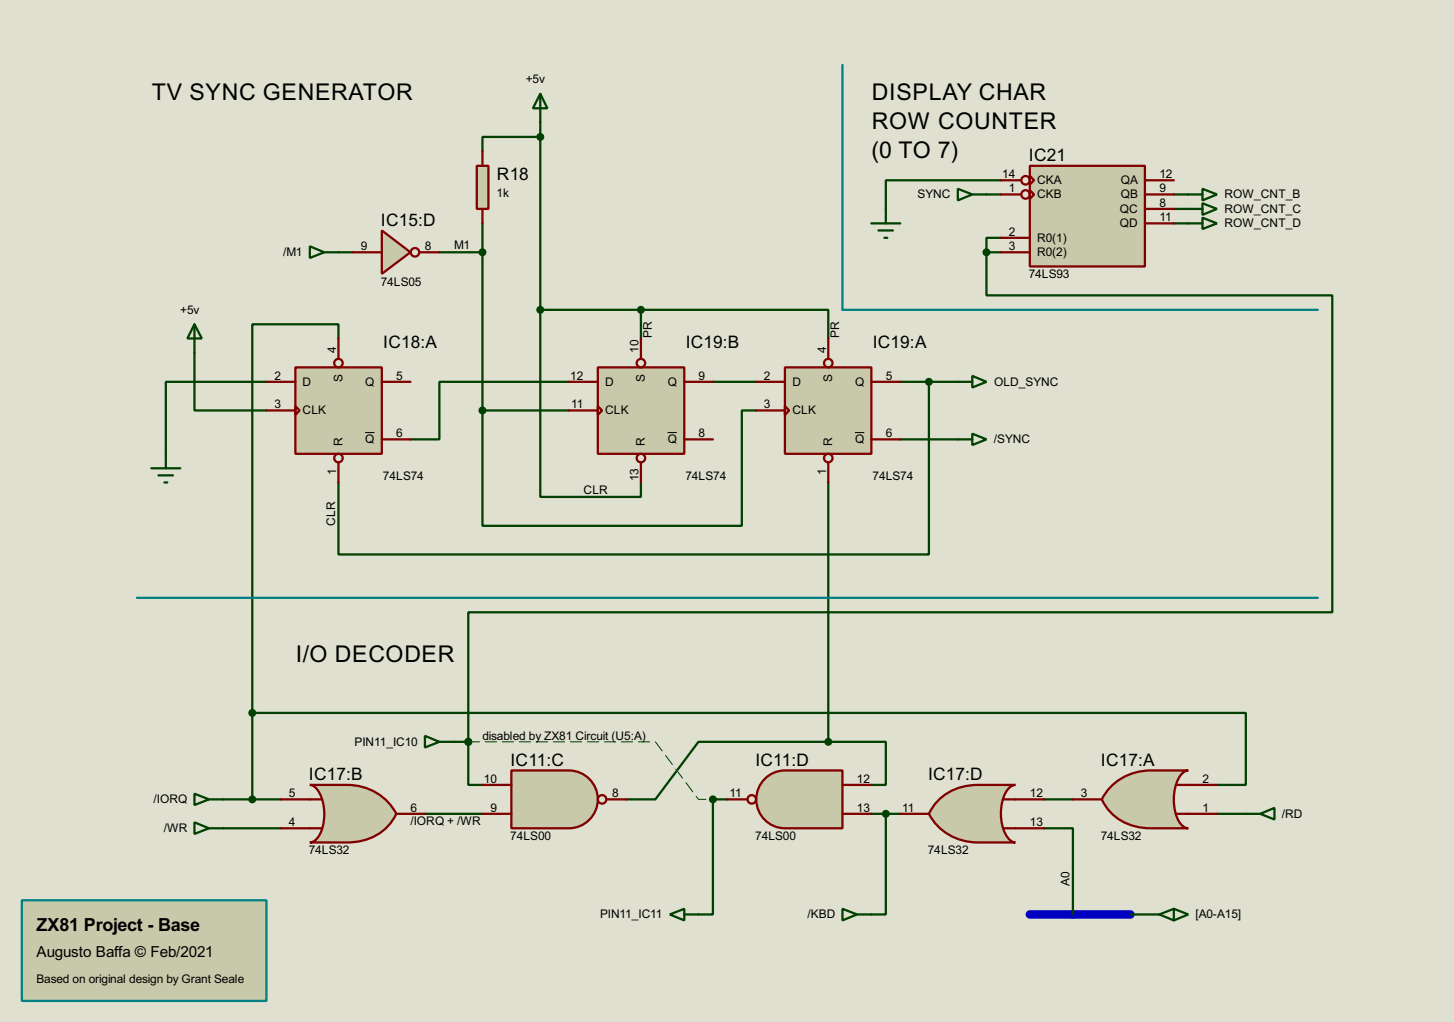
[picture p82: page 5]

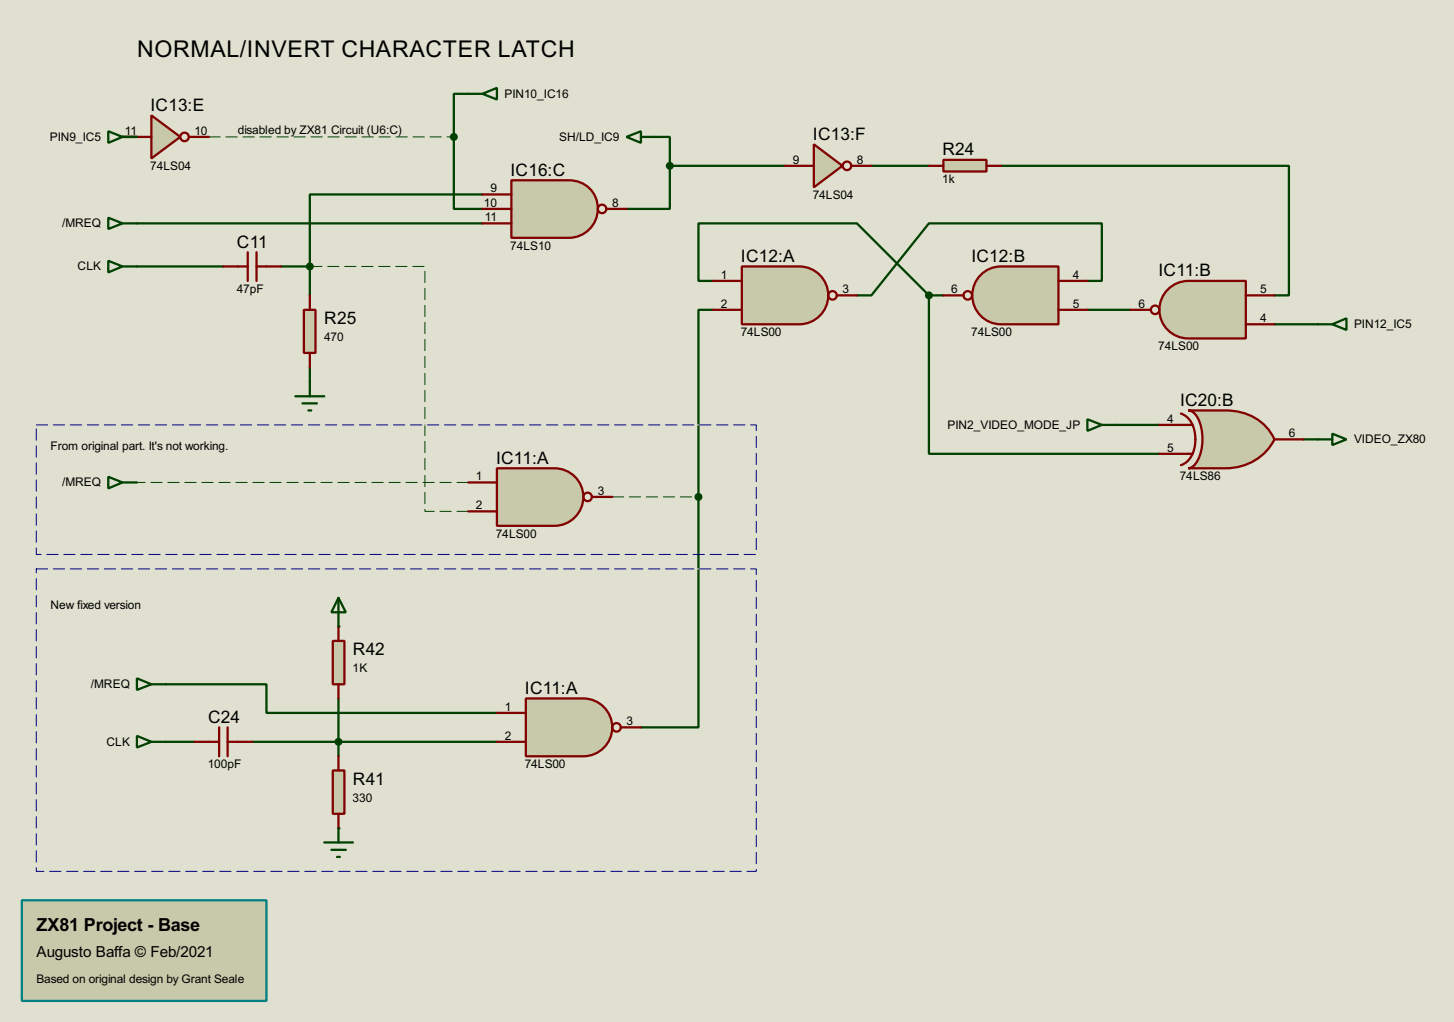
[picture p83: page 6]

NORMAL/INVERT CHARACTER LATCH

From original part. It's not working.

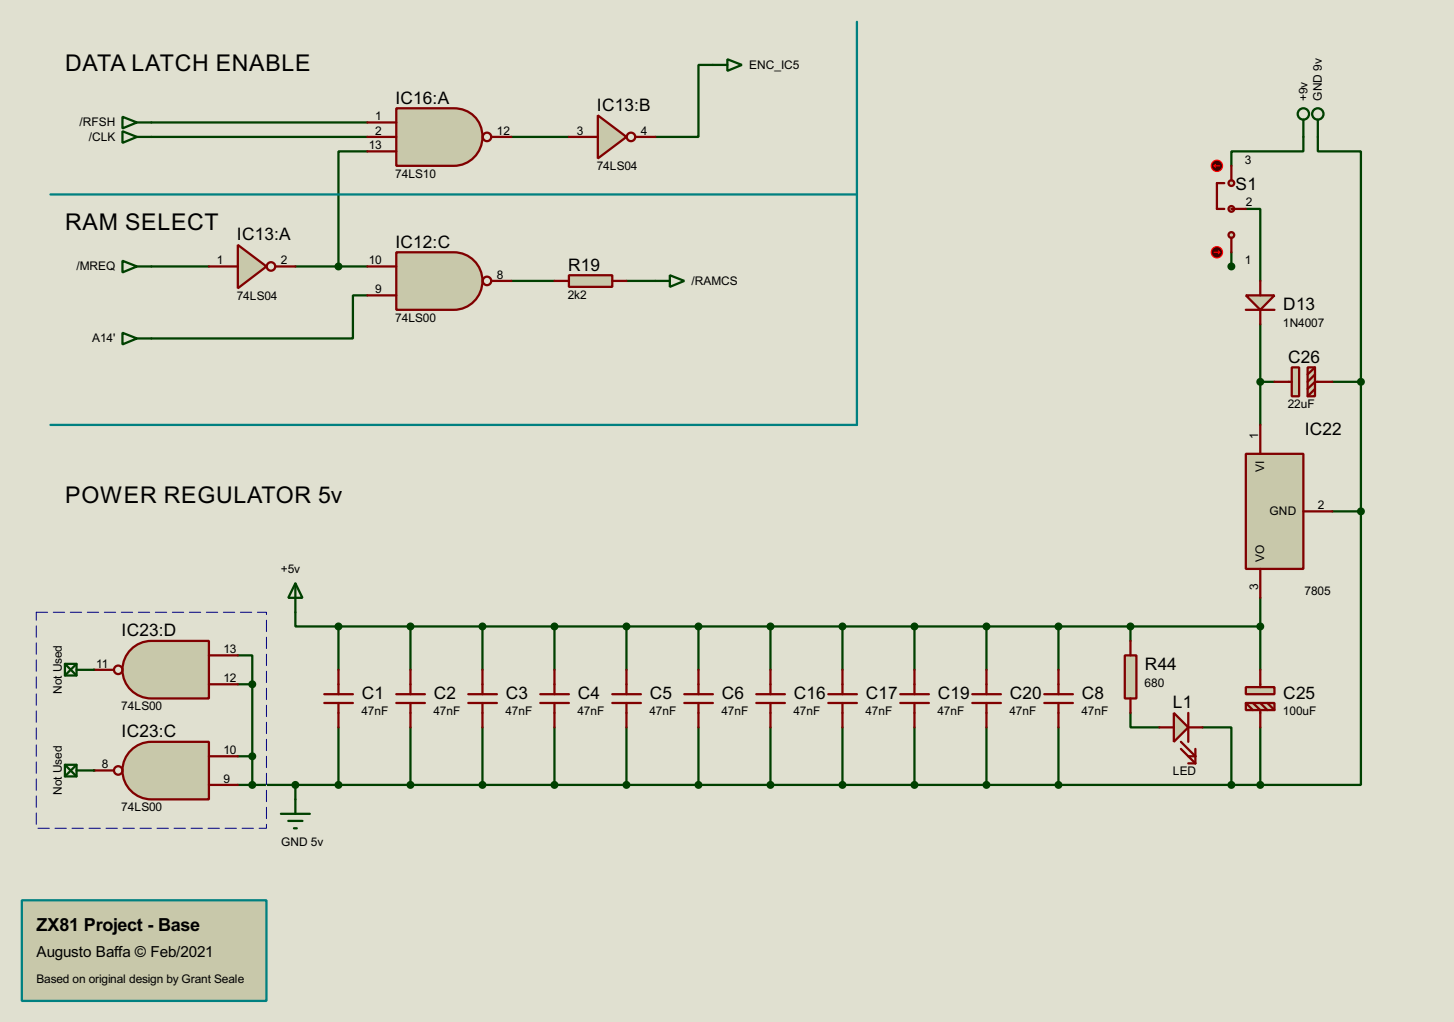
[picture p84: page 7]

/RFSH DATA LATCH ENABLE

Not Used Not Used A14'

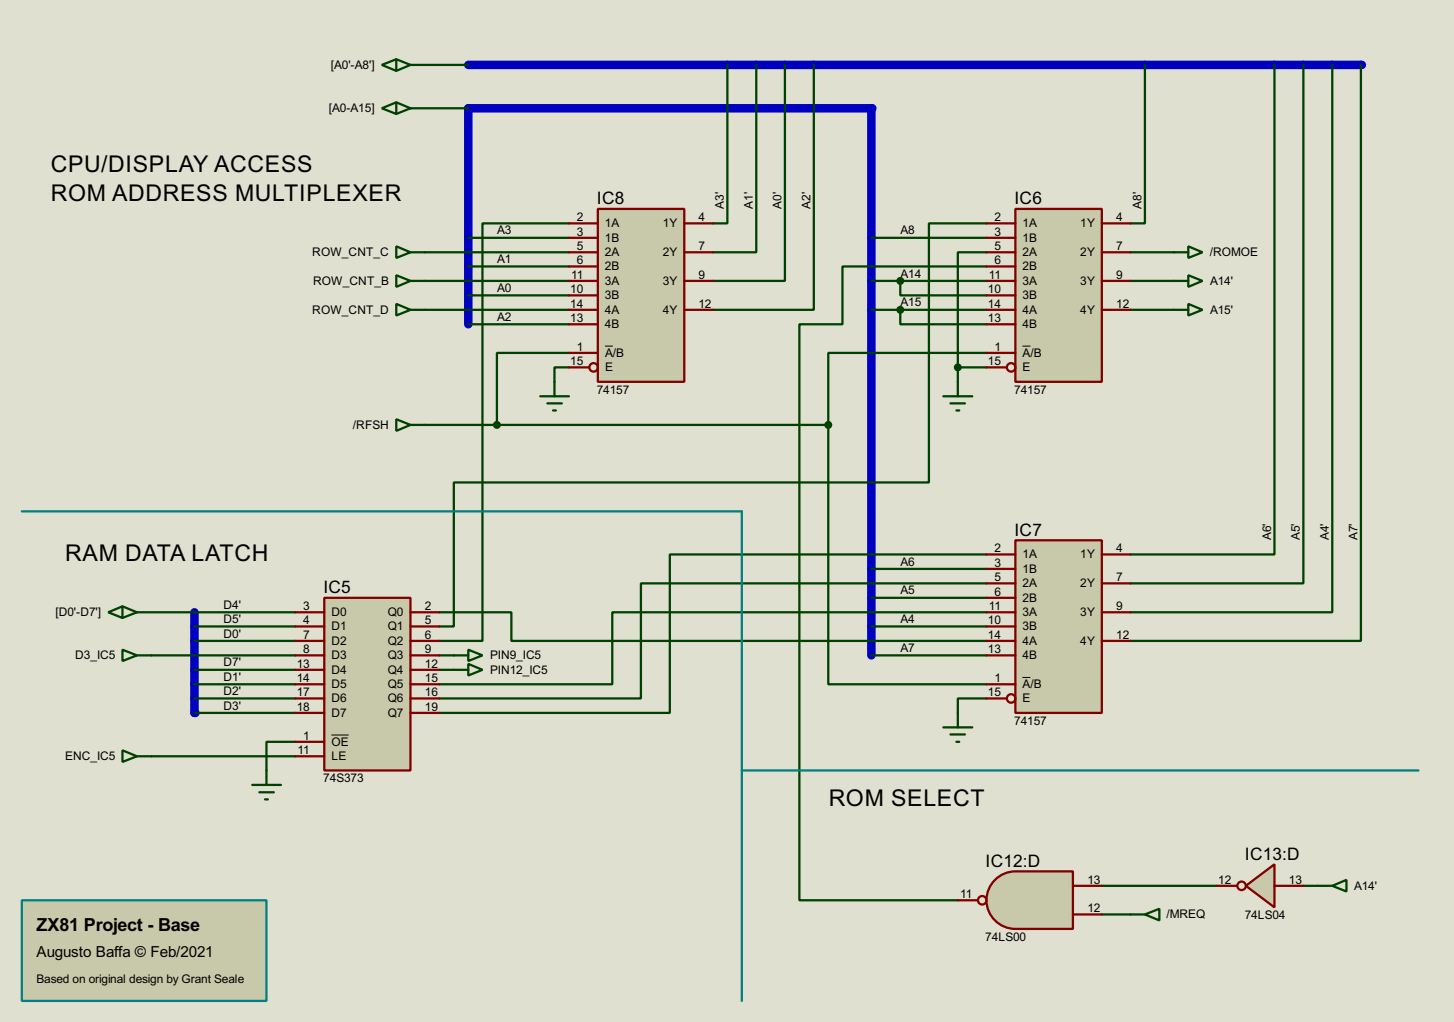
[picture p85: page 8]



From original part. Procuces low volume.

New fixed version




SYNC AND NMI PULSE GENERATOR

17 cycle pulse, 207 cycle period

HIGH=ZX81 MODE, LOW=ZX80 MODE



Back porch Grant Searle solution: JP3 = 2-3

Back porch generation José Leandro solution: Adjust image with R37 & R33

Back porch generation José Leandro solution

Based on original design by José Leandro

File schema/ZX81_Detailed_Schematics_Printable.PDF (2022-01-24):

# ZX80/81 Project

# by Augusto Baffa, Phd

# Assembled and Tested - Feb/2021

# http://www.augustobaffa.pro.br/



Based on original design by Grant Seale


9 CLK



NORMAL/INVERT CHARACTER LATCH

From original part. It's not working.


/RFSH DATA LATCH ENABLE

Not Used Not Used A14'




From original part. Procuces low volume.

New fixed version




SYNC AND NMI PULSE GENERATOR

17 cycle pulse, 207 cycle period

HIGH=ZX81 MODE, LOW=ZX80 MODE



Back porch Grant Searle solution: JP3 = 2-3

Back porch generation José Leandro solution: Adjust image with R37 & R33

Back porch generation José Leandro solution

Based on original design by José Leandro



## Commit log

2022-01-24 . adding talkback gerbers . rename case_zx80
    [abajo_b_no_switch_no_sup.stl, abajo_b_no_switch_soportes.stl, abajo_b_switch_no_sup.stl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]
2022-02-01 . cases organized
    [Spectrum_case1.stl, Spectrum_case2.stl, Spectrum_case3.stl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]
2022-02-01 . reorganizing cases for zx80
    [ZX-80_bottom_part1.stl, ZX-80_bottom_part2.stl, ZX-80_top.stl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]
2022-03-17 Wrong files
    [zx80_build034.routed.GBL, zx80_build034.routed.GBO, zx80_build034.routed.GBP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]
